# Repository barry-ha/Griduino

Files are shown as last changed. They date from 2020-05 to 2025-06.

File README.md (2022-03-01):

# Griduino
Griduino logoGPS display for vehicle dashboard showing position in the Maidenhead Locator System with distance to nearby grids. This is ideal for ham radio rovers.

# Introduction
Ham radio deals with invisible things.

We talk to invisible people. We look for contacts with invisible people that occupy invisible grid squares. To do so, we need to see invisible lines in the sky. I drive up mountains and travel on grid expeditions for VHF weak-signal operation. Being able to see these “invisible lines” is important to me. Seeing and hearing the unseen is always improved with technology (although I have that one uncle who doesn’t need any help /joke).

I want to know when I exit one grid square and enter another. Better yet, I want to know "how far to the next grid line in my current direction of travel?"

In contests I want time and distance figures to help me budget my time. I want to judge whether to stop and make contacts before leaving a grid. I want to get a sense of how long until I’m in the next grid. So, I’d like to know if a "new grid" opportunity is only a short distance away.

# Project Goals
For the operator:

1. How far to the next grid line?
1. What’s my current grid square?
1. Where am I in relation to the grid I’m occupying?
1. Where have I been? Or, how did I get here?
1. Make a bright display readable by a driver in motion.
1. What’s my altitude? Or, am I within a SOTA activation zone?
1. Hardware is powered from vehicle

For hobbyist developers:

1. Publish the software as open source
1. Make a programmable platform easily adaptable to related projects
1. Help the rover community build upon the platform.
1. Hardware should be possible for other hobbyists to duplicate
1. Hardware should small enough to mount conveniently on vehicle’s dashboard

# 	Griduino Usage
## Setup
Connect power: Griduino can be powered from two sources:

1. Connect USB to a computer for normal operation or programming, or
1. Attach 10- to 15-vdc source (automotive power) to the 5.5 mm barrel connector. The on-board regulator drops out at 9.8v. It seems to run okay with a 9v transistor battery for 30 minutes or more.

The speaker is louder with automotive power than with USB power, because the audio amplifier uses whichever power source has higher voltage. 

Connect speaker:

1. Connect a small speaker to the 3.5 mm stereo jack.
It produces one-channel (mono) output. If you attach a stereo speaker then both L and R output will have the same signal.

Place Griduino face up, preferably with a view of the sky to improve GPS satellite reception. The GPS receiver is very sensitive and will often work indoors.

## Operation
On power-up, Griduino shows credits (a splash screen) and plays Morse code callsigns of the authors.

Then it shows a Help screen to explain the touch-sensitive areas.
Touch Screen: There is a pressure-sensitive layer on top of the glass. We chose comically large touch regions so an operator can hit a target without looking.

- Top half:	Advance from one data screen to the next
- Bottom half:	Change brightness

Data Screens: Griduino v0.10 will display these screens.

1. Power-up animation (one time only)<br/>
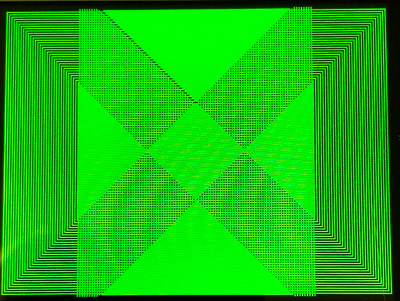
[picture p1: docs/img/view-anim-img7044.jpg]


2. Credits screen (one time only)<br/>
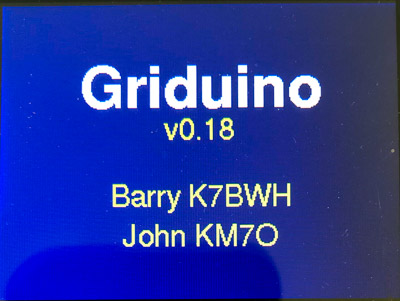
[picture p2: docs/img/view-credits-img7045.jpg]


3. Help screen (one time only)<br/>
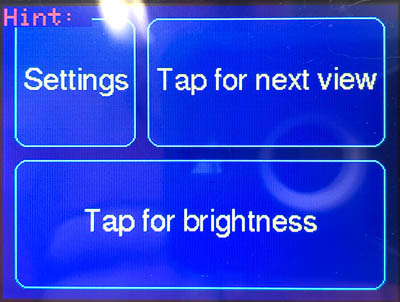
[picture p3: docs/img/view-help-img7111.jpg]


4. Grid location view<br/>
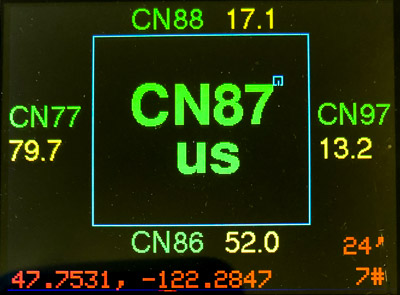
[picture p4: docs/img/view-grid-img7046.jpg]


5. Grid details view<br/>
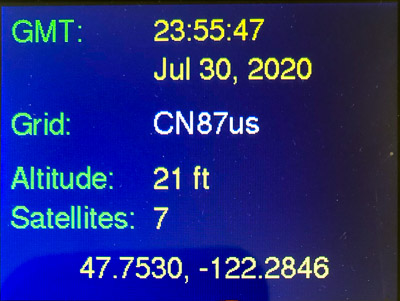
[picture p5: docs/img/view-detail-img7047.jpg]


6. GMT clock view<br/>
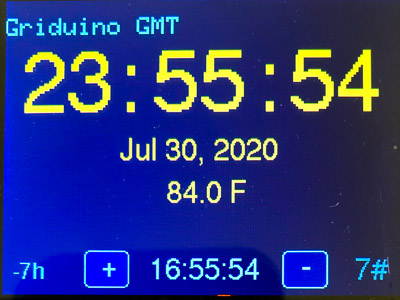
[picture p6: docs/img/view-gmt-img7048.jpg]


7. Audio volume control<br/>
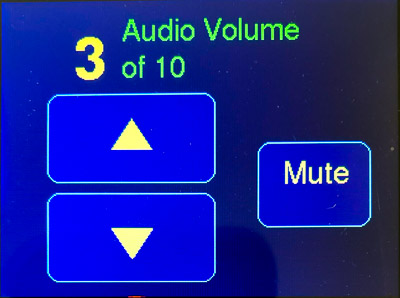
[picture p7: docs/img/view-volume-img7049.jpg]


8. Settings<br/>
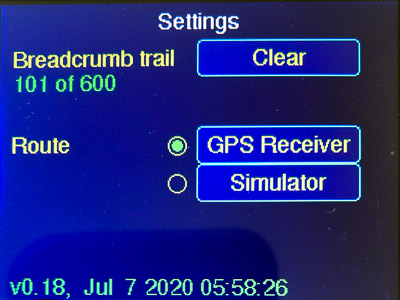
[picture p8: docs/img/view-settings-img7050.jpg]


# Programming
Griduino project hardware and software is open source and available on Github: [github.com/barry-ha/](https://github.com/barry-ha/)

To work with Griduino's source code, see the [Griduino Programming](./docs/PROGRAMMING.md) document.

# Parts List
Griduino's main building blocks are:
1. Arduino Feather M4 Express - https://www.adafruit.com/product/3857 
1. Adafruit 3.2" TFT color LCD display ILI-9341 - https://www.adafruit.com/product/1743 
1. Adafruit Ultimate GPS - https://www.adafruit.com/product/746
1. Adafruit Barometric Sensor - https://www.adafruit.com/product/3966 
1. Speaker for voice or CW grid-crossings. The audio chain produces line-level output to a digital potentiometer DS1804 for volume control, and an LM386 audio amplifier to a built-in speaker.

For a detailed list of parts, see the [Bill of Materials](./hardware/bill_of_materials.md).

Griduino kits are available from www.Griduino.com. Contact us directly to inquire about a pre-built and fully finished assembly.

# Support

Please browse our public group forum at [groups.io/g/Griduino/](https://groups.io/g/Griduino/)

Join our group to hear about upgrades, new software, ask questions, share your experience and suggest features.

# Disclaimer

The information provided is for general education and entertainment. We hope you learn from this and enjoy your hobbies in a safe manner with this new GPS information available at a glance. We take no responsibility for your assembly and construction, nor for how you use these devices. 

**Do not adjust Griduino while driving**. Keep your full attention on the road and the traffic around you. We cannot be held responsible for any property damage or injuries while using by this project. You are advised to check your local laws and consult professionals for any project involving electricity, construction or assembly. You are advised to drive in a safe and legal manner, consistent with all local laws, safety rules and good common sense.

You must accept that you and you alone are responsible for your safety and safety of others in any endeavor in which you engage.

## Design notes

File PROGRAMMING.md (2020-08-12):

<h1>Griduino Programming Instructions</h1>

<h2>1. Introduction</h2>

Griduino logoThank you for purchasing a Griduino GPS navigation kit. After [assembling the kit](https://github.com/barry-ha/Griduino/blob/master/ASSEMBLY.md "ASSEMBLY.md"), use this document to program it with the latest Griduino software. 

You can install a pre-compiled binary Griduino program, or set up the Arduino IDE (integrated development environment) to compile the source code yourself. By using the IDE, you can compile our example programs or modify the Griduino program or write all new software.

Griduino is open-source: https://github.com/barry-ha/Griduino

When complete, you'll have a useful driver's aid dedicated to show your location in the Maidenhead grid square system, your altitude, the exact time in GMT, barometric pressure and more.

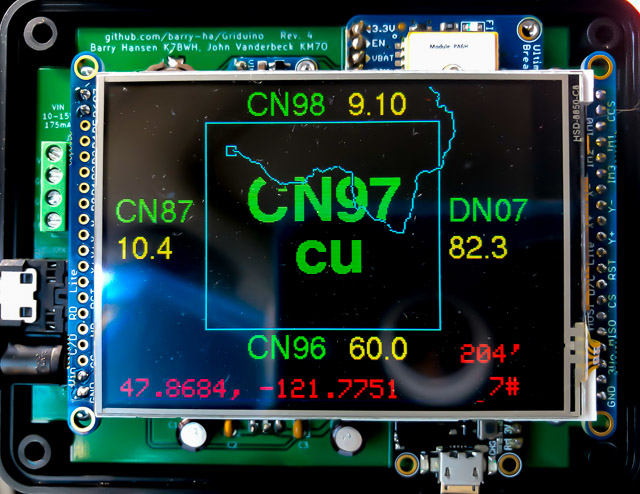
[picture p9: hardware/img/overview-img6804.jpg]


<h2>2. How to Install a Pre-Compiled Program on Griduino</h2>
Follow these steps to obtain the Griduino binary file and update the hardware.

1. **Download and Run Arduino IDE**<br/>
The Arduino IDE (integrated development environment) is the main workbench for writing, compiling and testing Arduino programs. Visit www.arduino.cc and find the **Software Downloads** section. Scroll down to the **Download the Arduino IDE** section. Find and **run the installer** for your operating system. For Windows, it is normal for it to open the Microsoft Store and download over 200 MB. Follow the prompts to install the software. **Launch the Arduino IDE**.<br/>
As of 8-7-2020, the latest workbench version is Arduino IDE v1.8.13

1. **Plug in Griduino**<br/>
Use a standard USB cable to connect your Griduino hardware to your computer. Depending on your computer, you should see some message about "setting up device" and possibly "device Feather M4 is ready".

1. **Select Port**<br/>
You'll need to figure out your COM port for this step. Here's how:<br/>
On Windows, run the **Device Manager** and expand the section for **Ports**. One of the items listed under Ports represents the Griduino device. It is possible for the port assignment to change from day to day, so be prepared to return to the Device Manager as needed.<br/>
In the Arduino IDE menu bar, go to **Tools > Port** and select the COM port that was given by the Device Manager. If there was more than one port listed, try them one by one.

1. **Install Board Support**<br/>
In this step, we will install support files needed by Arduino IDE to talk to the Feather M4. Here's how:<br/>
In the Arduino IDE menu bar, go to **Tools > Board > Boards Manager**. It will display a long list of hardware. Install the latest version of:
<ul>
<li>Arduino AVR Boards by Arduino: v1.8.3</li>
<li>Arduino SAMD Boards (32-bits ARM Cortex-M0+): v1.8.6</li>
</ul>

1. **Select Board**<br/>
On the Arduino IDE menu bar, select **Tools > Board > Arduino SAMD (32-bits ARM Cortex-M0+ and Cortex-M4) > Adafruit Feather M4 Express**<br/>
If the option is not available, please review previous step "Install Board Support".

1. **Download Griduino Binary**
You'll need a copy of the latest pre-compiled Griduino binary file. Here's how:<br/>
Visit the GitHub repository at https://github.com/barry-ha/Griduino. Find and click on **Griduino.ino.feather_m4.bin**. This will open a new web page for the binary file alone. Find and click on the **Download** link. Save this file in a place where you can easily find it for the next step.<br/>
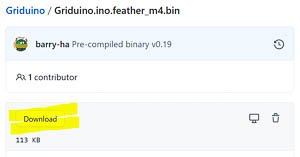
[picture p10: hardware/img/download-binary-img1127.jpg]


1. **Install Griduino Binary on Feather M4 Express**
Now that the Arduino IDE is ready, and we have the binary file, here's how to download it to the Feather M4.<br/>
<ul>
<li>Check that the Griduino hardware is still plugged in via USB to your computer.</li>
<li>Run Arduino IDE</li>
<li>On the menu bar, use **Tools > something (help!)**
</ul>

How to install without the IDE: https://forum.arduino.cc/index.php?topic=417659.0<br/>

How to install with AVRDude: https://arduino.stackexchange.com/questions/20978/is-there-a-way-to-upload-precompiled-code-to-an-arduino<br/>

More and sample cmd: https://forum.arduino.cc/index.php?topic=292979.0 such as "avrdude -c stk500v1 -P [com port] -p atmega328p -U flash:w:[Filename.hex]:i"<br/>

My command line is:<br/>
C:\Users\barry\Documents\ArduinoData\packages\arduino\tools\bossac\1.8.0-48-gb176eee/bossac -i -d --port=COM12 -U -i --offset=0x4000 -w -v C:\Users\barry\AppData\Local\Temp\arduino _ build _ 72645/Griduino.ino.bin -R

<h2>3. How to Setup the Arduino IDE for Griduino</h2>
If you want to compile Griduino source code or work with its example files (and we hope you do) then here's everything you need to setup the workbench.

(Coming soon)

<h2>4. How to Create a Binary File for Distribution</h2>

It may be useful to know how to create a binary image of a compiled program for Arduino processors in general. If you ever want to distribute an Arduino program, it is easier for people to install a binary image than to compile the source code themselves. 

This section also applies to how we create the Griduino program for general distribution.

1. **Launch Arduino IDE**<br/>
Run the Arduino workbench on your computer.

1. **File > Open > Griduino.ino**<br/>
Open the main source code file.

1. **Sketch > Export Compiled Binary**<br/>
Wait for the compilation process to finish

2. **Sketch > Show Sketch Folder**<br/>
You will find a binary file in the sketch folder with **.bin** extension. This is the compiled file which can be installed onto an Arduino board. e.g. “Griduino.ino.feather_m4.bin”

<h2>4. Disclaimer</h2>

The information provided is for general education and entertainment. We hope you learn from this and enjoy your hobbies in a safe manner with this new GPS information available at a glance. We take no responsibility for your assembly and construction, nor for how you use these devices. 

**Do not adjust Griduino while driving**. Keep your full attention on the road and the traffic around you. We can not be held responsible for any property or medical damages caused by these projects. You are advised to check your local laws and consult professionals for any project involving electricity, construction or assembly. You are advised to drive in a safe and legal manner, consistent with all local laws, safety rules and good common sense.

You must accept that you and you alone are responsible for your safety and safety of others in any endeavor in which you engage.

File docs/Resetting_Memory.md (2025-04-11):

<h1>Griduino Memory Reset Instructions</h1>

<h2 id="intro">1. Introduction</h2>

Griduino logoIn rare instances, the Griduino flash memory may become corrupted. Here's how to recover by reformatting its internal file system and then re-installing Griduino software.

<h2 id="save">2. Backup Your Current Griduino Software</h2>
These steps will copy the software from Griduino to your hard drive. This is easier than downloading new software. Later, you'll restore this backup onto Griduino which guarantees you'll be running the exact same version as before.

1. **Plug in Griduino**<br/>
   - Use a standard USB data cable to connect your Griduino hardware to your computer.
   - Depending on your computer, you should see a message about "setting up device" and possibly "device Feather M4 is ready".
   - Remove Griduino's top cover to expose the "reset" button adjacent to the USB connector.

1. **Open Feather as a Drive**<br/>
   - Press the Feather's "reset" button **twice** rapidly, about a tenth of a second apart.
   - The Griduino screen may go blank out and turn white. Many computers will sound an audible "drive ready" chime.
   - In Windows, open the **File Explorer**.
   - Find the new drive, e.g. "**FEATHERBOOT (F:)**"
   - If the USB device name is CIRCUITPY, then double-click the Reset button again until you get FEATHERBOOT.

1. **Copy "CURRENT.UF2" from FEATHERBOOT to your computer**
   - Note: The file "current.uf2" is always the current software program loaded into the processor memory system.
   - Drag and drop "current.uf2" to your computer's local storage. 
   - Store the .UF2 file in a temporary place that you can find again later when you restore this software.

<h2 id="program">2. Reformat File System</h2>
Normally, you'll never need to reformat Arduino's file system. In the rare case you need to start over with a clean file system, here's how. 

1. **Download "flash_erase_express.uf2" file from GitHub**<br/>
   - Visit https://github.com/barry-ha/Griduino/tree/master/downloads
   - Download a copy of **flash_erase_express.uf2**
   - Note: We pre-compiled this program for you. It is a direct and unmodified program from the `examples` folder of https://github.com/adafruit/Adafruit_SPIFlash

1. **Install flash_erase_express**<br/>
   - Press the Feather's "reset" button **twice** rapidly, about a tenth of a second apart.
   - Drag the .UF2 file that you downloaded and drop it on the new FEATHERBOOT drive. Or you can copy/paste it to the new drive.
   - After the copying completes, the on-board Neopixel will be blue.
   - A few seconds later, the Neopixel should starting flashing green once per second. This indicates the SPI flash has been erased and all is well.
   - If the Nexopixel starts flashing red two or three times a second, an error has occurred and hardware repair is needed.
 
<h2 id="circuitpy">3. Install CircuitPython</h2>
We temporarily install CircuitPython, which prepares the flash memory file system to become compatible with Windows file systems.

1. **Download "CircuitPython" binary distribution file**<br/>
   - Get the latest CircuitPython UF2 file for your board (Feather M4 Express) from https://circuitpython.org/downloads.
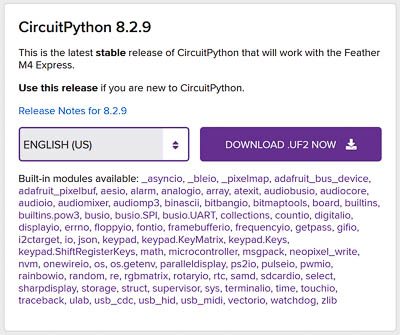
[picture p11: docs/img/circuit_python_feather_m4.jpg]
   - As of April 2025, the latest stable release is 9.2.7 and the UF2 file is named "[adafruit-circuitpython-feather_m4_express-en_US-8.2.9.uf2](https://downloads.circuitpython.org/bin/feather_m4_express/en_US/adafruit-circuitpython-feather_m4_express-en_US-9.2.7.uf2)" and will look something like:<br/>

1. **Start the bootloader on the Feather board** by double-clicking its Reset button.<br/>
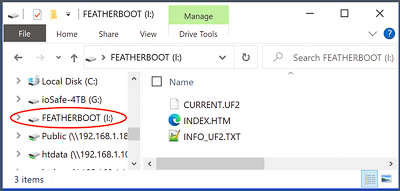
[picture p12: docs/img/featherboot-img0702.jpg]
   - After a moment, you should see a "FEATHERBOOT" drive appear on your desktop computer.<br/>

1. **Drag the circuitpython UF2 file** from Windows to FEATHERBOOT.
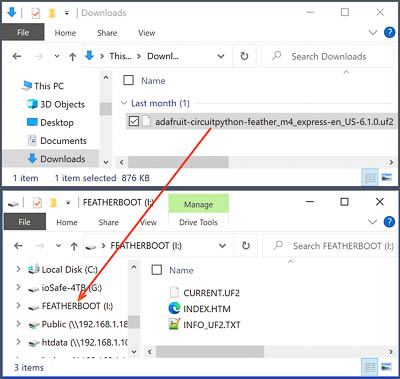
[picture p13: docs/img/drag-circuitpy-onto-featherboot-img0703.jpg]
   - 
   - The UF2 file will be copied and the Feather will reboot.
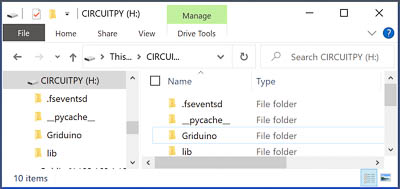
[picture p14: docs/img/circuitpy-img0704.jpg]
   - Then you should see a CIRCUITPY drive appear as an external USB drive. It will already have a few files on it.<br/>

<h2 id="audio">4. Optional: Install Audio Files</h2>

Optional: Griduino can use speech to announce grid lines. To do so, you can install audio recordings of the letters and numbers. These are .WAV files provided on GitHub in the `audio` folder.

If you don't need spoken-word announcements, skip to "Re-install Griduino Program" below.

You only need to install audio files one time.

The idea here is to use the CircuitPython installation (above) which allows the Flash memory to appear as an external USB drive. Then we can copy the "audio" folder to Flash. If, instead, the Griduino software is running then we cannot access its file system from the computer. The first time CircuitPython is installed, it automatically formats Flash memory in a way that remains compatible thereafter.

1. **Download "griduino_audio.zip" file from GitHub**<br/>
   - Visit https://github.com/barry-ha/Griduino/tree/master/downloads
   - Get a copy of **audio_female.zip** and **audio_male.zip**
   - Choose the voice you want; Griduino can only work with one voice at a time. To switch to another voice, repeat this process with the other files.
   - If you want to make your own recordings that are compatible with Griduino, see the README document at https://github.com/barry-ha/Audio_QSPI.

1. **Unzip e.g. "audio_male.zip"**
   - Extract this file to a temporary folder. 
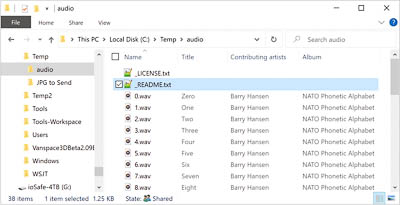
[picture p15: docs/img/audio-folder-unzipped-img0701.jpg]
Extracted audio folder
   - The result will have a folder named "audio" that contains 26 letters and 10 numbers as short recordings in standard Microsoft WAV format.<br/>

1. **Start the bootloader on the Feather board** by double-clicking its Reset button.<br/>
   - After a moment, you should see a "FEATHERBOOT" drive appear on your desktop computer.<br/>

1. **Drag the circuitpython UF2 file** from Windows to FEATHERBOOT.
   - 
   - The UF2 file will be copied and the Feather will reboot.
   - Then you should see a CIRCUITPY drive appear as an external USB drive. It will already have a few files on it.<br/>

1. **Drag the audio folder** from Windows to CIRCUITPY.<br/>
   - Be sure to store all of the WAV files (there are at least 36 of them) in a top-level folder named "audio".
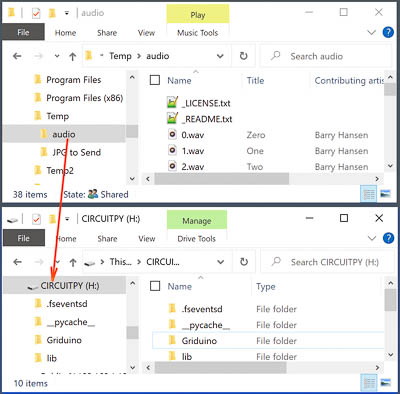
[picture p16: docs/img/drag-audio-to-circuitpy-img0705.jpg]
   - Note that file names and folders are case-sensitive.<br/>
   - Now we're all done with CircuitPy mode, although you can use re-install CircuitPy later for direct access to the file system.

<h2 id="griduino">4. Re-install Griduino Program</h2>

You can re-install the Griduino software you saved earlier, or you may download the latest software from GitHub.

1. **Open Feather as a Drive**<br/>
   - Press the Feather's "reset" button **twice** rapidly, about a tenth of a second apart.
   - Find the new drive, e.g. "**FEATHERBOOT (F:)**"
   - If the USB device name is CIRCUITPY, then double-click the Reset button again until you get FEATHERBOOT.

1. **Install Griduino Software on Feather M4 Express**<br/>
   - Drag the .UF2 file that you saved earlier and drop it on the new FEATHERBOOT drive. Or you can copy/paste it to the new drive.
   - After the copying completes, Griduino will automatically restart with the new software.
   - First it shows an animation, then it shows a credits screen with the program name and version number, then a hints screen with a visual reminder of the default touch-sensitive areas.

1. **Test Griduino's audio playback**<br/>
   - If you installed audio files: Start the Griduino program
   - Plug a speaker into the speaker jack (or connect to the internal terminal strip).
   - Press the "gear" icon until you see the **Audio Type** screen.<br/>Select **Spoken Word**.<br/>It should immediately announce your grid square.<br/>If it beeps, then Griduino did not find the audio files.
   - Press the "gear" icon until you see the **Speaker Volume** screen.<br/>Press the up/down buttons to adjust a comfortable volume.<br/>It should play an audio sample on each press.
   - To troubleshoot errors, open the **Arduino IDE** and click **Tools** > **Serial Monitor** to read error messages.

<h2 id="uf2">5. Understanding File System's Configuration Files</h2>

Griduino automatically creates and updates its internal configuration files. These are in a binary format you'll never need to work with them. However, it may be interesting to know where they are and how they work.

The files are stored in Flash memory in a section of onboard memory. To see the directory of files:

* **Terminal window:** Open a terminal window and send the command "list files", or
* **CircuitPy:** Reload Griduino with the CircuitPy program and use Windows File Explorer

Some of the files you can expect to see are:

* Directory of audio
   * `19004 0.wav`
   * `24712 1.wav`
   * `19602 2.wav`
   * etc
   * `25040 z.wav`
   * `38 files, 799330 bytes`
* Directory of Griduino
   * ` 97 announce.cfg` - Morse code, Spoken word, No audio
   * `272 gpshistory.csv` - GPS breadcrumb trail
   * `216 gpsmodel.cfg` - latitude, longitude, altitude, metric/english, timezone
   * ` 97 nmea.cfg` - send NMEA sentences to USB cable yes/no
   * `100 screen.cfg` - screen orientation
   * `100 volume.cfg` - audio volume
   * `9 files, 882 bytes`

<h2 id="more">Appendix. Griduino's File System</h2>

Here is additional information about Griduino's file system:

1. (Understanding Configuration Files)[https://github.com/barry-ha/Griduino/blob/master/docs/PROGRAMMING.md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]
1. (How to Use a Serial Console)[https://github.com/barry-ha/Griduino/blob/master/docs/PROGRAMMING.md#8-how-to-use-a-serial-console]
1. (Griduino Programming Instructions)[https://github.com/barry-ha/Griduino/blob/master/docs/PROGRAMMING.md]

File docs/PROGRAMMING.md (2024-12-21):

<h1>Griduino Programming Instructions</h1>

<h2 id="intro">1. Introduction</h2>

Griduino logoThank you for purchasing a Griduino GPS navigation kit. After [assembling the kit](https://github.com/barry-ha/Griduino/blob/master/ASSEMBLY.md "ASSEMBLY.md"), use this document to program it with the latest Griduino software.

You can install a pre-compiled binary Griduino program, or set up the Arduino IDE (integrated development environment) to compile the source code yourself. By using the IDE, you can compile our example programs or modify the Griduino program or write all new software.

Griduino is open-source: https://github.com/barry-ha/Griduino

When complete, you'll have a useful driver's aid dedicated to show your location in the Maidenhead grid square system, your altitude, the exact time in GMT, barometric pressure and more.



<h2 id="program">2. Install the Griduino Program</h2>
Follow these steps to obtain the Griduino binary file and update the software.

1. **Download Griduino Binary**<br/>
   - Visit https://github.com/barry-ha/Griduino
   - Click on **downloads/griduino_v108.uf2** or later version. This will open a new web page for the binary UF2 file.
   - Click on the **Download** link. Save this file where you can easily find it for the next step.

1. **Plug in Griduino**<br/>
   - Use a standard USB cable to connect your Griduino hardware to your computer.
   - Depending on your computer, you should see a message about "setting up device" and possibly "device Feather M4 is ready".
   - Get a wooden (must not be metal or conductive) toothpick that can fit in the hole in the front cover. Or remove the cover to expose the "reset" button.

1. **Open Feather as a Drive**<br/>
   - Press the Feather's "reset" button **twice** rapidly, about a tenth of a second apart.
   - The Griduino screen will blank out and turn white. Most Windows computers will sound an audible "drive ready" chime.
   - In Windows, open the **File Explorer**.
   - Find the new drive, e.g. "**FEATHERBOOT (F:)**"
   - If the USB device name is CIRCUITPY, then double-click the Reset button again until you get FEATHERBOOT.

1. **Install Griduino Software on Feather M4 Express**<br/>
   - Drag the .UF2 file that you downloaded and drop it on the new FEATHERBOOT drive. Or you can copy/paste it to the new drive.
   - After the copying completes, Griduino will automatically restart with the new software.
   - First it shows an animation, then it shows a credits screen with the program name and version number, then a hints screen with a visual reminder of the default touch-sensitive areas.

<h2 id="audio">3. Install Audio Files</h2>

Griduino can use speech to announce grid lines. To do so, we must install audio recordings of the letters and numbers. These WAV files are copied onto the Feather separately using a different process than the binary program file.

You only need to install audio files one time.

The idea here is to temporarily install CircuitPython which allows the Flash memory to appear as an external USB drive. Then copy our "audio" folder to Flash and install the Griduino program again. The first time CircuitPython is installed, it automatically formats Flash memory in a way that remains compatible thereafter.

1. **Download "griduino_audio.zip" file from GitHub**<br/>
   - Visit https://github.com/barry-ha/Griduino/tree/master/downloads
   - Get a copy of **audio_female.zip** and **audio_male.zip**
   - Choose the voice you want; Griduino can only work with one voice at a time. To switch to another voice, repeat this process with the other files.
   - If you want to make your own recordings that are compatible with Griduino, see the README document at https://github.com/barry-ha/Audio_QSPI.

1. **Unzip e.g. "audio_female.zip"**
   - Extract this file to a temporary folder. 
   - The result will have a folder named "audio" that contains 26 letters and 10 numbers as short recordings in standard Microsoft WAV format.<br/>Extracted audio folder

1. **Download "CircuitPython" binary distribution file**<br/>
   - Get the latest CircuitPython UF2 file for your board (Feather M4 Express) from https://circuitpython.org/downloads.
   - As of December 2023, the latest stable release is 8.2.9 and the UF2 file is named "adafruit-circuitpython-feather_m4_express-en_US-8.2.9.uf2" and will look something like:<br/>

1. **Start the bootloader on the Feather board** by double-clicking its Reset button.<br/>
   - After a moment, you should see a "FEATHERBOOT" drive appear on your desktop computer.<br/>

1. **Drag the circuitpython UF2 file** from Windows to FEATHERBOOT.
   - 
   - The UF2 file will be copied and the Feather will reboot.
   - Then you should see a CIRCUITPY drive appear as an external USB drive. It will already have a few files on it.<br/>

1. **Drag the audio folder** from Windows to CIRCUITPY.<br/>
   - Be sure to store all of the WAV files (there are at least 36 of them) in a top-level folder named "audio".
   - Note that file names and folders are case-sensitive.<br/>

1. **Reboot Feather and re-install Griduino**<br/>
   - Follow the steps (above) in [2. How to Install the Griduino Program](#program) above to run the program.

1. **Test Griduino's audio playback**<br/>
   - Start the Griduino program
   - Press the "gear" icon until you see the **Audio Type** screen.<br/>Select **Spoken Word**.<br/>It should immediately announce your grid square.<br/>If it beeps, then Griduino did not find the audio files.
   - Press the "gear" icon until you see the **Speaker Volume** screen.<br/>Press the up/down buttons to adjust a comfortable volume.<br/>It should play an audio sample on each press.
   - To troubleshoot errors, open the **Arduino IDE** and click **Tools** > **Serial Monitor** to read error messages.

<h2 id="format">4. How to Reformat File System</h2>

Normally, you'll never need to reformat Arduino's file system. The memory partition and FAT file system will automatically take care of itself.

The first time you install CircuitPy it will automatically reformat the Flash chip. Subsequently reloading CircuitPy will not affect the Flash chip contents. 

We recommend loading CircuitPy when you first start using a new Feather M4. This ensures that all further file operations are done in a file system that easily shared with CircuitPy. The file system format is compatible with all IDE program that are based on the Adafruit SPI Flash framework ( https://github.com/adafruit/Adafruit_SPIFlash ).

In the rare case you need to start over with a clean file system, here's how. Adafruit provides some reformatting sketches in their ‘examples’ folder of Adafruit_SPIFlash. Open the IDE and use the menu bar to navigate to Files > Examples > Adafruit SPIFlash. Some of the programs are:

* **Flash erase express** - will nuke the file system from orbit to start over. This will completely erase all data on the QSPI flash for “Express” models, ie, processors with on-board QSPI chips such as the Feather M4 Express. This is handy to reset the flash into a known empty state and fix potential filesystem or other corruption issues.
* **SdFat format** - SPI Flash FatFs formatting example. Use the console (serial monitor) to respond to prompts to confirm the operation. Partitioning and formatting will take about 60 seconds.
* **Flash speedtest** - measures size and R/W speed of the RAM file system. This will erase the chip but not reformat it. You'll need to install CircuitPy next to format the filesystem.

<h2 id="uf2">5. Understanding File System's Configuration Files</h2>

Griduino automatically creates and updates its internal configuration files. These are in a binary format you'll never need to work with them. However, it may be interesting to know where they are and how they work.

The files are stored in Flash memory in a section of onboard memory. To see the directory of files:

* **Terminal window:** Open a terminal window and send the command "list files", or
* **CircuitPy:** Reload Griduino with the CircuitPy program and use Windows File Explorer

The files you can expect to see are:

* Directory of audio
   * `19004 0.wav`
   * `24712 1.wav`
   * `19602 2.wav`
   * etc
   * `25040 z.wav`
   * `38 files, 799330 bytes`
* Directory of Griduino
   * ` 97 announce.cfg` - Morse code, Spoken word, No audio
   * `272 gpshistory.csv` - GPS breadcrumb trail
   * `216 gpsmodel.cfg` - latitude, longitude, altitude, metric/english, timezone
   * ` 97 nmea.cfg` - send NMEA sentences to USB cable yes/no
   * `100 screen.cfg` - screen orientation
   * `100 volume.cfg` - audio volume
   * `9 files, 882 bytes`

<h2 id="uf2">6. How to Create a Binary File for Distribution</h2>

It may be useful to know how to create a binary image of a compiled program for Arduino processors in general. If you ever want to distribute your own Arduino program, it is easier for your users to install your binary image than to compile the source code themselves.

This section also applies to how we prepared the Griduino software for general distribution.

1. **Launch Arduino IDE**<br/>
Run the Arduino workbench on your computer.

1. **File > Open > Griduino.ino**<br/>
Open the main source code file.

1. **Sketch > Export Compiled Binary**<br/>
It will compile; wait for this to finish.

1. **Sketch > Show Sketch Folder**<br/>
You will find a binary file in the sketch folder with **.bin** extension. This is the compiled binary file but it cannot be directly distributed or installed onto an Arduino board.
   - Arduino IDE 1: Griduino.ino.feather_m4.bin
   - Arduino IDE 2: build / adafruit.samd.adafruit_feather_m4 / Griduino.ino.bin

1. **Convert Compiled Binary to UF2**<br/>
Run the Python conversion script (author https://github.com/microsoft/uf2):
   - Open command line window
   - Change directory to the .bin file, e.g.:<br/>**cd C:\Users\barry\Documents\Arduino\Griduino**
   - Run the Python converter script, e.g.:<br/>**py uf2conv.py -c -b 0x4000 -o downloads/griduino.uf2 Griduino.ino.feather_m4.bin**
   - Where "**-c:**" will pass remaining arguments to python script, "**-b 0x4000**" will set start of program, "**-o file.uf2**" is output file, and "**file.bin**" is input file

<h2 id="ide">7. How to Setup the Arduino IDE for Griduino</h2>

If you want to compile Griduino source code or work with its example files (and we hope you do) then here's everything you need to setup the workbench.

1. **Download and Run Arduino IDE**<br/>
The Arduino IDE (integrated development environment) is the main workbench for writing, compiling and testing Arduino programs. As of October 2024, the latest version is Arduino IDE v2.3.3. We recommend the latest version, although initial development was done with v1.18,  and the majority of work was done with v2.0 and v2.2.

  * Visit www.arduino.cc and find the **Software Downloads** section.
  * Scroll down to the **Download the Arduino IDE** section.
  * Find and **run the installer** for your operating system. For Windows, it is normal for it to open the Microsoft Store and download over 200 MB. Follow the prompts to install the software.
  * **Launch the Arduino IDE**.
  
2. **Add Packages Link to Board Manager**<br/>
The IDE can't find the list of SAMD boards unless we add their magic URL to preferences:

  * **File** > **Preferences**
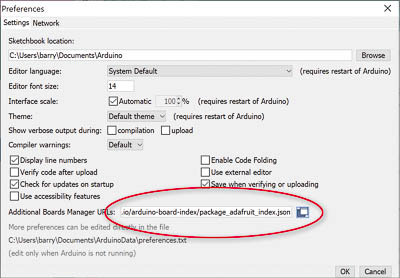
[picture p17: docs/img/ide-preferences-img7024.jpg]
Preferences dialog
  * Find the "Additional Boards Manager URLs" section<br/>
  * To the right is an icon that when selected will open up a window to add the new URL.
  * If the below URL is not visible or a different one is showing, add the following URL using the icon to be able to see the file "Adafruit SAMD Boards v 1.6.3" in the next step.
  * Add: https://adafruit.github.io/arduino-board-index/package_adafruit_index.json
  * It's important to use the icon because if you just type the above in to the URL slot, and select OK it will not store the new URL and be empty when you check it again.
  * Click OK

3. **Install Board Support**<br/>
In this step, we will install support files needed by Arduino IDE to talk to the Feather M4. Here's how:<br/>
In the Arduino IDE menu bar, go to **Tools > Board > Boards Manager**. It will display a long list of hardware. Install the latest version of:

  * Arduino AVR Boards, Built-In by Arduino: v1.8.6
  * Arduino SAMD Boards (32-bits ARM Cortex-M0+): v1.8.14
  * Adafruit SAMD Boards: v1.7.16

4. **Select Board**<br/>
On the Arduino IDE menu bar, select **Tools > Board > Arduino SAMD (32-bits ARM Cortex-M0+ and Cortex-M4) > Adafruit Feather M4 Express**<br/>
If the option is not available, please review previous step "Install Board Support".

5. **Select Port**<br/>
You'll need to figure out your COM port for this step. Here's how:<br/>
On Windows, run the **Device Manager** and expand the section for **Ports**. One of the items listed under Ports represents the Griduino device. It is possible for the port assignment to change from day to day, so be prepared to return to the Device Manager as needed.<br/>
In the Arduino IDE menu bar, go to **Tools > Port** and select the COM port that was given by the Device Manager. If there was more than one port listed, try them one by one.

6. **Install Library Dependencies**</br>
In the Arduino IDE menu bar, go to **Tools > Manage Libraries**. Install the latest version (and their dependencies) of these libraries:
   - ##AudioZero## by Arduino v1.1.2 (orig v1.1.1)
   - ##SD## by Arduino, SparkFun v1.3.0 (orig v1.2.4)
   - ##Adafruit TFTLCD Library## by Adafruit v1.0.3? (orig v1.0.6)
   - ##Adafruit BMP3XX Library## by Adafruit v2.1.5 (orig v2.1.2)
   - ##Adafruit BusIO## by Adafruit v1.16.1 (orig v1.11.0) (there is a known issue with v1.11.1)
   - ##I2CDevice" by Adafruit
   - ##Adafruit GFX Library## by Adafruit v1.11.10 (orig v1.10.13)
   - ##Adafruit GPS Library## by Adafruit v1.7.5 (orig v1.6.0)
   - ##Adafruit ILI9341## by Adafruit v1.6.1 (orig v1.5.10) also available: ILI9341_t3 by Limor Fired, Adafruit, Paul Stoffregen v1.0.0
   - ##Adafruit ImageReader Library## by Adafruit v2.9.2 (orig v2.7.0)
   - ##Adafruit NeoPixel## by Adafruit v1.12.3 (orig v1.10.4)
   - ##Adafruit SPIFlash## by Adafruit v5.0.0 (orig v3.9.0)
   - ##Adafruit TouchScreen## by Adafruit v1.1.5 (orig v1.1.3)
   - ##elapsedMillis## by Paul Stoffregen v1.0.6
   - ##SdFat – Adafruit Fork## by Bill Greiman v2.2.3 (orig v1.5.1)<br>*Note:* Use v1, as we have not tested v2<br> *Note:* There are two libraries with similar names. Be sure to install "SdFat - Adafruit Fork" and not "SdFat" which has an incompatible SdFat.h file
   - #Time# by Michael Margolis v1.6.1 <br>*Note:* searching the library manager for the word "time" lists just about every library. Searching for the word "timekeeping" will show the correct library.

These components are outside of Arduino's Library Manager, so follow these links to GitHub and install the latest version:

- https://github.com/tom-dudman/DS1804 v0.1.1 - library to control DS1804 Digital Potentiometer
- https://github.com/barry-ha/Audio_QSPI v1.1.0 - library to play WAV files from Quad-SPI memory chip

<h2 id=serialconsole>8. How to Use a Serial Console</h2>

You can download GPS tracks from Griduino without the Arduino IDE. There are some common "serial terminal" programs that can interact directly with Griduino's console interface over the USB connection.

We recommend Tera Term (https://tera-term.en.lo4d.com). Although we tested PuTTY (https://www.putty.org/), it randomly fails to chunks of text from Griduino. Use Tera Term instead.

How to use Tera Term to capture the breadcrumb trail in both KML and CSV format:

1. Run Tera Term
1. New connection window:
	1. Choose Serial
	2. Set Port: COM7 <i>(or your own Griduino port)</i>
	3. Leave everything else at default settings <i>(baud rate setting does not matter)</i>
1. Menu bar: <b>File > Log ...</b> <i>(pick a filename you can find later, e.g., griduino.log)</i>
1. Type: <b>stop nmea</b> <i>(don't press Enter!)</i>
1. Type: <b>help</b> <i>(don't press Enter!)</i>
1. Type: <b>version</b> <i>(don't press Enter!)</i>
1. Type: <b>dump kml</b> <i>(don't press Enter!)</i>
1. Type: <b>dump gps</b> <i>(don't press Enter!)</i>
1. Close Tera Term
1. Run Notepad
	1. Edit <i>griduino.log</i>
	1. Keep only from \<xml\> to \</xml\>
	1. Save as <i>griduino.<b>kml</b></i>
	1. Edit <i>griduino.log</i> again
	1. Keep only from "Record, Grid, Lat, Long, Date GMT" <br/>to last line e.g. "101, CN97ct, 47.8128,-121.8053, 11-17-2022  17:57:0"
	1. Save as <i>griduino.<b>csv</b></i>
	
Now you can open <i>griduino.kml</i> in Google Earth and <i>griduino.csv</i> in Microsoft XML.

<h2 id=disclaimer>9. Disclaimer</h2>

The information provided is for general education and entertainment. We hope you learn from this and enjoy your hobbies in a safe manner with this new GPS information available at a glance. We take no responsibility for your assembly and construction, nor for how you use these devices. 

**Do not adjust Griduino while driving**. Keep your full attention on the road and the traffic around you. We can not be held responsible for any property or medical damages caused by these projects. You are advised to check your local laws and consult professionals for any project involving electricity, construction or assembly. You are advised to drive in a safe and legal manner, consistent with all local laws, safety rules and good common sense.

You must accept that you and you alone are responsible for your safety and safety of others in any endeavor in which you engage.

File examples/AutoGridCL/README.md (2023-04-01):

# AutoGridCL

This is a command-line program to update the grid square in WSJT-X from Griduino in real time.

## Install Software

Install Python

* Download and Install Python https://www.python.org/downloads/
* Add Python to PATH https://datatofish.com/add-python-to-windows-path/
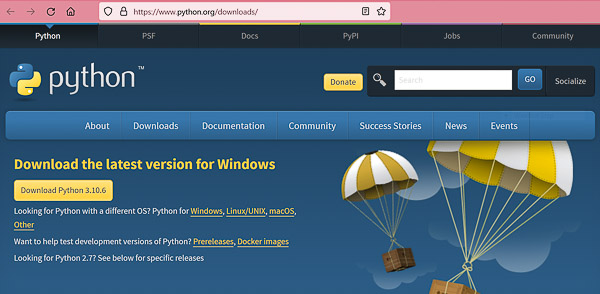
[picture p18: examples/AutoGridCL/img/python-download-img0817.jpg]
python download
<br/>

Get AutoGridCL files into a local folder

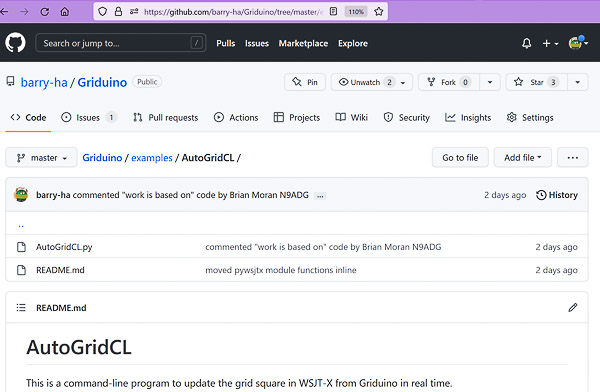
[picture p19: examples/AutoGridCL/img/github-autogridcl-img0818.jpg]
GitHub example folder
* Visit GitHub at https://github.com/barry-ha/Griduino <br/>
* Fetch the files in the 'examples/AutoGridCL' folder, currently:
  * AutoGridCL.py
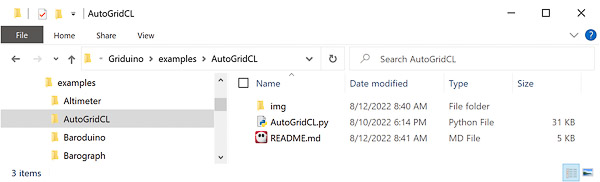
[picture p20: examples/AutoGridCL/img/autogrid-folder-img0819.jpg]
autogrid folder
  * README.md <br/>
 
## Configure WSJT-X for multicast

Run WSJT-X and configure File > Settings > Reporting:

* <b>UDP Server: 224.0.0.1</b> <br/>*224.0.0.1 is the most compatible with JTAlert, GridTracker, HRD, etc and these packets are not routed outboard onto your LAN*<br/>*127.0.0.1 can be used if you use WSJT only with AutoGridCL and no other programs*
* <b>UDP Server port number: 2237</b> <br/>*2237 is the default*
* <b>Outgoing interfaces: loopback_0</b> <br/>*a loopback interface is required*
* <b>Multicast TTL: 1</b> <br/>*this is a packet's Time-To-Live, a small number of seconds*

configure WSJT-X multicast
 
## Configure AutoGridCL

You need to modify the file 'AutoGridCL.py' so it can read NMEA sentences from Griduino and send UDP packets to and from WSJT-X.

Using a text editor (e.g. Notepad or Visual Studio Code), modify 'AutoGridCL.py': 

* line 7: <b>GPS_PORT = "COM53"</b> <br/>*must match that of your Griduino or GPS*
* line 8: <b>GPS_RATE = 115200</b> <br/>*Griduino always runs at 115200 baud. Other GPS devices often use 9600 baud.*
* line 11: <b>MULTICAST_ADDR = "224.0.0.1"</b> <br/>*must match the Multicast IP address in WSJT-X*
* line 12: <b>MULTICAST_PORT = 2237</b> <br/>*must match the Multicast UDP port in WSJT-X*

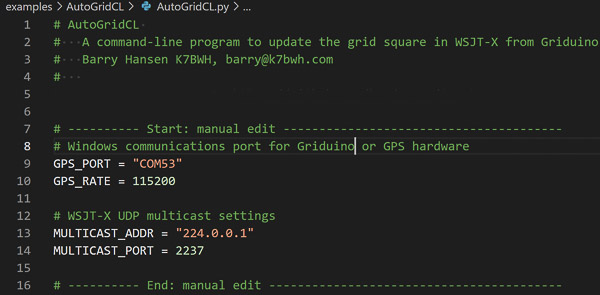
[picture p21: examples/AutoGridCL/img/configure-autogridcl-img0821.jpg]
configure AutoGridCL


## Run AutoGridCL

WSJT-X must be started first. AutoGridCL will not retry if it fails to find WSJT-X - it throws an exception and ends.

Start WSJT-X and set your grid using File>Settings>General to a grid different than the grid you are in and check the box to enable Autogrid.

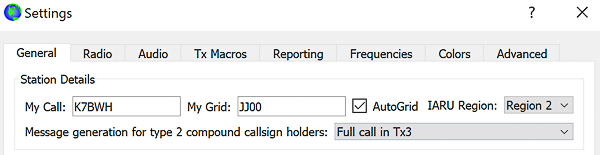
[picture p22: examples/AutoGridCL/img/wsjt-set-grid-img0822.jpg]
configure WSJT grid square


Run AutoGridCL.py by double-clicking it in your File Explorer. Or, you can open a command window and run ''python AutoGridCL.py'

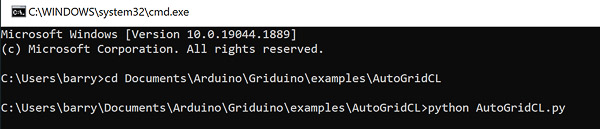
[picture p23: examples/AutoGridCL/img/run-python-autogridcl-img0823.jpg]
run python AutoGridCL from command line


You should see a command line window open with its console messages.

Then you should start to see UDP packets read from WSJT-X and, after Griduino syncs with satellites, some NMEA sentences from the GPS.

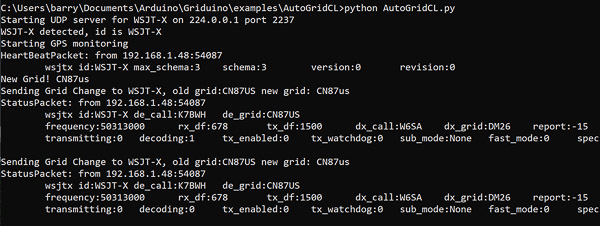
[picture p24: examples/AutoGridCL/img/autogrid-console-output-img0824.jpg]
example output of AutoGridCL


If everything is set up properly, you should see your TX6 message in WSJT-X change to the gridsquare you are actually in.

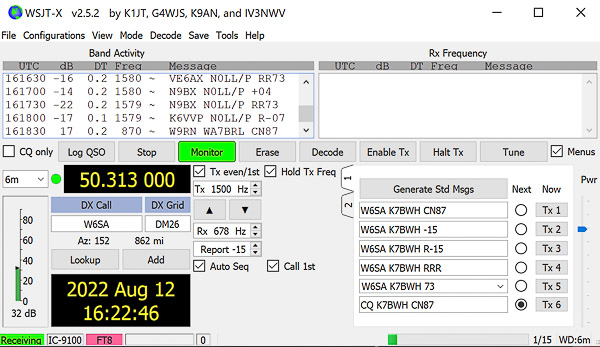
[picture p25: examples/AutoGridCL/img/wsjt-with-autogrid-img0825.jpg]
running WSJT with AutoGridCL


When you end AutoGridCL, its last grid will linger until you change it, or restart WSJT-X, or toggle autogrid off/on. When you restart WSJT-X, it will always remember and revert to the grid square you originally configured.

## Troubleshooting

Error reporting is fairly basic in this program. You will need to be resourceful to troubleshoot problems at this early stage.

In theory, this program should work with several different USB-attached GPS pucks. As long as the GPS sends standard NMEA data with lat/long position in $GPGGA or $GPGLL sentences, this will automatically decode them. We tested and recommend GPS pucks based on the GlobalSat BU-353-S4 chipset, typically $50 on Amazon in 2022.

The serial port for Griduino can only be opened by one program at a time, causing it to be mutually exclusive with programs like NMEA Time2. If you want full-time GPS-based clock synchronization, some work-arounds are:

* AutoGridCL and NMEA Time2 can run together if they each have their own GPS receiver and serial port. 
* Run [JTSync](http://www.dxshell.com/jtsync.html) instead of [NMEA Time2](https://www.visualgps.net/).

Here are some suggestions that might help.

* If a command-line window does not appear after starting AutoGridCL.py, then it might have an exception and have ended right away. To see messages, open a command window, change to the directory where the file is located, and type 'python AutoGridCL.py'
* If you don't see NMEA messages from Griduino, reboot it and watch the screen to see the version number. Griduino software version must be 1.10 or later.
* If this program can't connect to Griduino, close any programs using it (such as NMEA Time2 or the Arduino workbench) before starting AutoGridCL. Note that the USB port cannot be shared, so only one program at a time can listen to Griduino. For extra fun, note that NMEA Time2 is a background service and cannot be closed; you must configure its GPS setting to 'Off' to disconnect it from the serial port.
* Tell Barry about problems you run into so he can add it to the list: barry@k7bwh.com.

## Acknowledgements

We owe a great deal of credit to:

* Francis KV5W, https://kv5w.com/2021/10/17/wsjt-x-autogrid/
* Brian Moran N9ADG, https://github.com/bmo/py-wsjtx

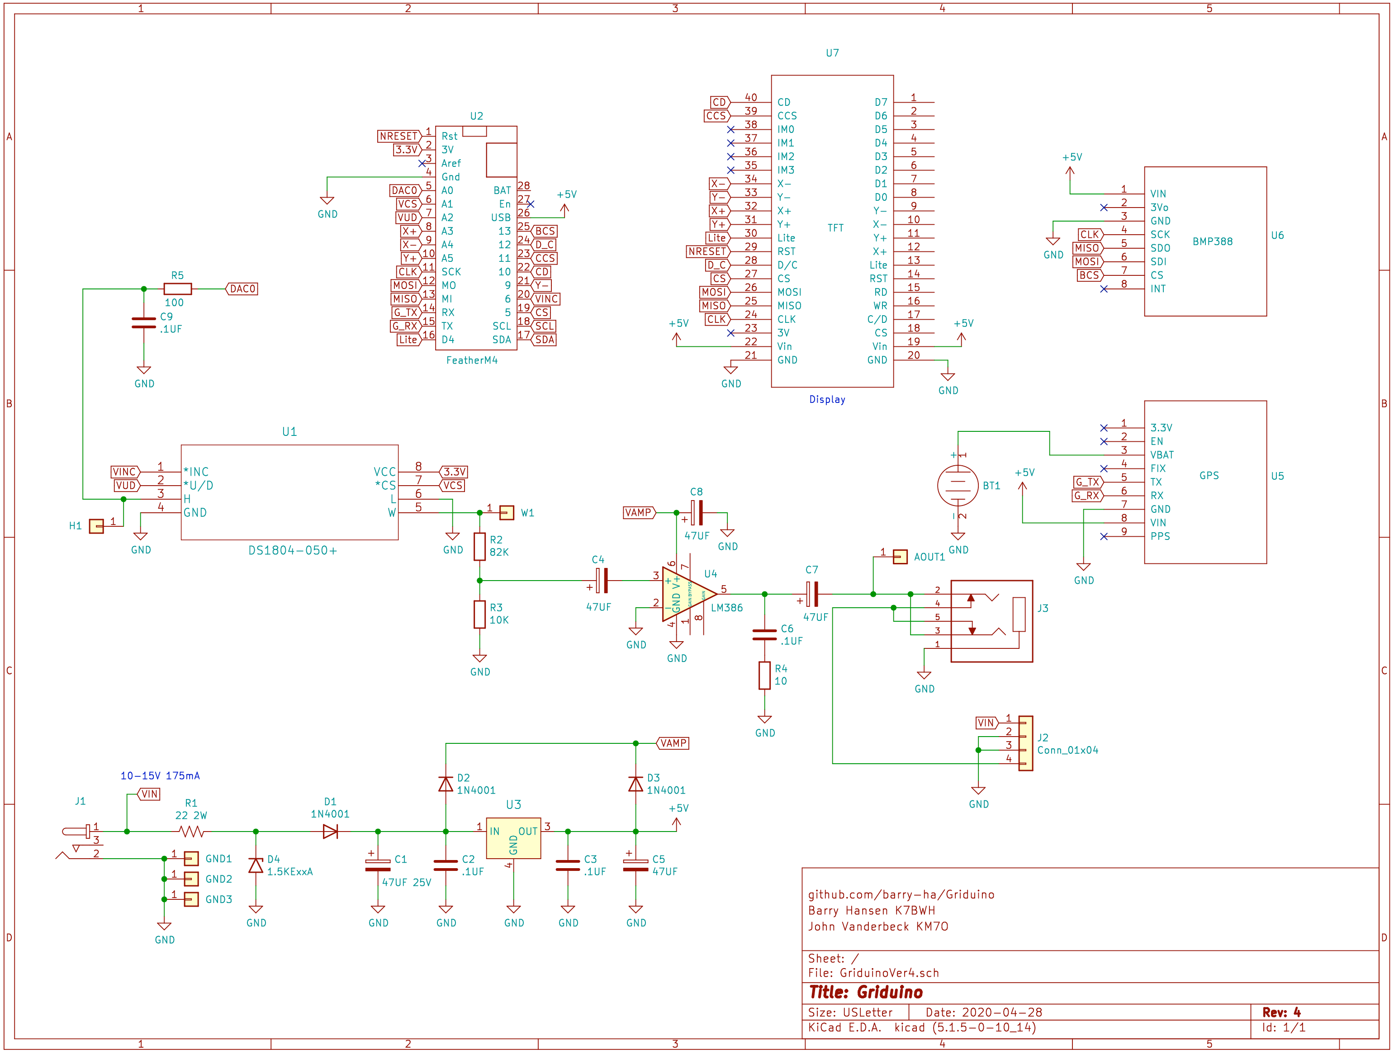
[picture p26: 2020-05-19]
hardware/Griduino v4 Schematic 2020-04-28.png

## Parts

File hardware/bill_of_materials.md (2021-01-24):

# Griduino
GPS display for vehicle dashboard showing position in the Maidenhead Locator System with distance to nearby grids, designed for ham radio rovers.

## Active Components
| Mfr | Mfr Part No | Digi-Key Part No | Reference | Qty | USD$  | Ext$ | Description  |
| --- | --- | --- | --- | :---: | ----- | --- | --- |
| Maxim | DS1804-050+ | DS1804-050+-ND | U1 |  1 |  4.30 | 4.30 | IC Digital Pot 50KOHM 100-tap |
| Adafruit | 3857 | 1528-2648-ND | U2 |  1 | 22.95 |  22.95 | Feather M4 Express |
| Microchip | MIC5239-5.0YS | MIC5239-5.0YS-ND | U3 |  1 |  2.79 | 2.79 | IC Linear Regulator 5v 500mA |
| TI | LM386N-3/NOPB | 296-43959-5-ND | U4 |  1 |  1.24 | 1.24 | Audio Amp, Mono LM386 700MW |
| Adafruit | 746 | 1528-1153-ND | U5 |  1 | 39.95 |  39.95 | Ultimate GPS, 66 channel (do not buy part #4279) |
| Adafruit | 3966 | 1528-2733-ND | U6 |  1 |  9.95 | 9.95 | BMP-388 Barometric Pressure |
| Adafruit | 1743 | 1528-2614-ND | U7 |  1 | 29.95 |  29.95 | TFT Display  |
| | | | **total** | **6** | | **111.13** | |

## Passive Components
| Mfr | Mfr Part No | Digi-Key Part No | Reference |  Qty | USD$  | Ext$ | Description  |
| --- | --- | --- | --- | :----: | ----- | --- | --- |
| Panasonic | ECE-A1EKA470I | P19582CT-ND | C1, C4, C5, C7, C8 | 5 |  0.25 | 1.25 | CAP Electrolytic 47uF 25v radial |
| KEMET | C320C104K5R5TA  | 399-4264-ND | C2, C3, C6, C9 | 4 |  0.24 | 0.96 | CAP Ceramic 0.1uF 50V radial |
| ON Semi | 1N4001G | 1N4001GOS-ND | D1, D2, D3 | 3 |  0.21 | 0.63 | Gen Purpose Diode 50V 1A |
| Vishay | 1.5KE18CA | 1.5KE18CA-E3/51GI-ND | D4 | 1 |  1.33 | 1.33 | Zener Diode 25.2v Clamp |
| Adafruit | 4445 | 3351-ND | LS1 | 1 |  3.95 | 3.95 | Speaker, 3W 4ohm |
| Yageo | FKN2WSJT-73-22R | 22AUCT-ND | R1 | 1 |  0.47 | 0.47 | RES 22-ohm 2W 5% axial |
| Yageo | CFR-25JB-52-82K | 82KQBK-ND | R2 | 1 |  0.10 | 0.10 | RES 82K 1/4W 5% axial |
| Yageo | CFR-25JB-52-10K | CFR-25JB-52-10K | R3 | 1 |  0.10 | 0.10 | RES 10K 1/4W 1% axial |
| Yageo | MFR-25FBF52-10R | 10.0XBK-ND | R4 | 1 |  0.10 | 0.10 | RES 10-ohm 1/4W 1% axial |
| Stackpole | CF14JT100R | CF14JT100RCT-ND | R5 | 1 |  0.10 | 0.10 | RES 100-ohm 1/4W 5% axial |
| | | | **total** | **16** | | **8.99** | |

## Hardware
| Mfr | Mfr Part No | Digi-Key Part No | Reference |  Qty  | USD$  | Ext$ | Description  |
| --- | --- | --- | --- | :---: | ----- | --- | --- |
| Panasonic | CR1220 | P033-ND | B1 | 1 |  1.00 | 1.00 | Lithium Battery 3-volt Coin Cell |
| Keystone | 1056 | 36-1056-ND | BT1 | 1 |  1.50 | 1.50 | Battery Holder (Open) 12.5 mm |
| CUI Devices | PJ-102A | CP-102A-ND | J1 jack | 1 |  0.64 | 0.64 | Connector Power Jack 2X5.5 mm |
| CUI Devices | PP3-002A | CP3-1000-ND | J1 plug | 1 |  1.29 | 1.29 | Connector Power Plug 2.1X5.5 mm |
| Amphenol | YO0421500000G | 609-3920-ND | J2 | 1 |  1.01 | 1.01 | Connector Screw Terminal 4pin |
| CUI Devices | SJ1-3545N | CP1-3545N-ND | J3 jack | 1 |  1.31 | 1.31 | Connector 3.5mm Audio Stereo Jack |
| CUI Devices | MP3-3501 | MP3-3501 | J3 plug | 1 |  1.22 | 1.22 | Connector 3.5mm Audio Mono Plug |
| Sullins | PPTC201LFBN-RC  | S7018-ND | | 1 |  1.23 | 2.46 | Connector 20-pos 0.1 Tin (LCD)  |
| Sullins | PPTC021LFBN-RC  | S7000-ND | | 2 |  0.32 | 0.64 | Connector 2-pos 0.1 Tin (LCD) |
| Keystone | 4952 | 36-4952-ND | TP1-3, TP_GND | 6 |  0.22 | 1.32 | PC Test Point Loop |
| JLC PCB | | n/a | PCB | 1 |  6.00 | 6.00 | Printed Circuit Board |
| Polycase | QS-50MBT | n/a | | 1 | 15.00 |  15.00 | Plastic Case, Custom 4.5 x 3.5 x 1.25 |
| | | | **total** | | | **41.36** | |

## Packaging
| Mfr | Mfr Part No | Digi-Key Part |  Qty  | USD$  | Ext$  | Description  |
| --- | --- | --- | :---: | ----- | ----- | --- |
| Desco | 13879 | 16-1344-ND | 4 |  0.12 |  0.48 | Antistatic bag, 3" x 5" |
| Desco | 12250 | 16-1231-ND | 1 |  0.06 |  0.06 | Antistatic foam, 1/4" 1" x 2" |
| Aviditi | M752 | n/a | 1 |  0.79 |  0.79 | White easy-fold box, 7 x 5 x 2 |
| Beadaholic  | ZDI-0203 | n/a | 1 |  0.05 |  0.05 | Bag for screws 2x3" |
| Alin | | n/a | 1 |  0.19 |  0.19 | Cushion foam pouch 7.5 x 12" |
| | | | **total** | | **1.53** | |

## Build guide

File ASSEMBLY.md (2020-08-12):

<h1>Griduino Kit Assembly Instructions</h1>

<h2>1. Introduction</h2>

Griduino logoThank you for purchasing a Griduino GPS navigation kit. Once assembled, this kit is a useful driver's aid dedicated to show your location in the Maidenhead grid square system, your altitude, the exact time in GMT, barometric pressure and more. Further, the hardware is a highly capable platform for programming your own features.



These assembly instructions apply to Revision 4 of the printed circuit board.

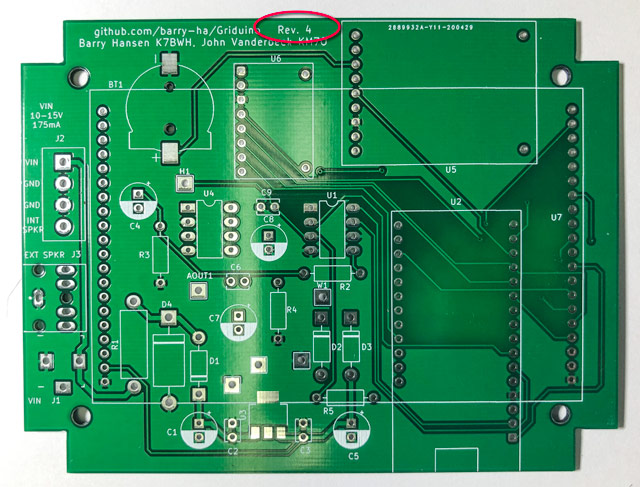
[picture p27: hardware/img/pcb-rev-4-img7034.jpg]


<h2>2. You Will Need</h2>

This kit is almost entirely "through hole" construction. Only two components, the battery holder and voltage regulator, are large surface-mount parts.

<h3>You must have:</h3>

* **Printed BOM and schematic diagram.** The component values are found on the bill of materials and the schematic. For example, to learn that R1 is a 22-ohm 2-watt resistor, you must find it in the BOM or schematic. These assembly instructions generally *don't* include part values in an attempt, possibly futile, to avoid multiple documents getting out of sync. The schematic is your ultimate golden master reference for all Griduino design. This is an open-source project and the latest documents are available on https://github.com/barry-ha/Griduino.
* **Fine-tipped soldering iron.** A standard fine-tipped iron suitable for use with conventional 0.1” pitch through-hole components.  It is recommended that you use a temperature controlled iron at a suitable temperature for your solder, if you have one. It is assumed that you will already have the necessary skills to solder this kit. If however you are not comfortable with through-hole electronic soldering, there are plenty of soldering tutorials available online.
* **Decent quality solder, with a flux core.**  Any decent quality, thin, flux cored solder designed for electronic use should be suitable for assembling this kit. Solder size 0.50 mm is ideal. Do not use solder intended for plumbing.
* **Needle nose pliers.** The component's leads must be bent with small pliers for a good fit into holes. Small pliers are also good for picking up the smallest parts from a tray.
* **Side cutters.** After you solder discrete components to the board, you will need to clip off the protruding wires. Wear eye protection and aim the bits away from you in a safe direction. 
* **Philips-head screwdriver.** There are four small screws to attach the PCB into the case.
* **Solderless breadboard.** To solder header pins onto small board assemblies, temporarily using a solderless breadboard will hold pins in correct alignment.<br/>
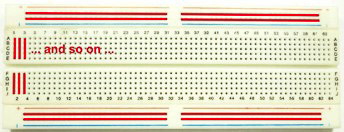
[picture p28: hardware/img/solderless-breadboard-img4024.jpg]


<h3>It will be nice to have:</h3>

* **Hobbyist bench vise.** You'll need a way to hold the PCB at a convenient height and angle for soldering parts. A small adjustable bench vise, such as a <a href="https://www.panavise.com/">Panavise Model 366</a>, will make your task easier. Use a holder wide enough to grip the Griduino PCB of 4-1/2" width.<br/>
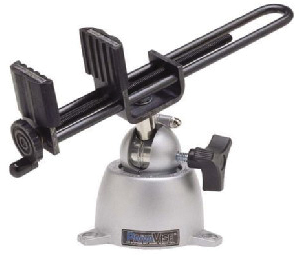
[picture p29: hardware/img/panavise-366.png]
 
 
* **Craft knife.** The plastic case will need small cutouts for power and speaker wires to reach the connectors. A very careful application of a sharp small knife can trim out the holes you need. A craft detail knife such as Fiskars 165110-1002 has better safety and precision than Exacto knives.<br/>


* **Blue painters tape.** While soldering things upside down, an easy-to-remove tape can temporarily hold parts onto the PCB. When you do this, solder only one pin, then double-check the parts are still tight on the PCB. If not, reheat the one pin and press on the part to re-seat it. Then solder the remaining leads.<br/>
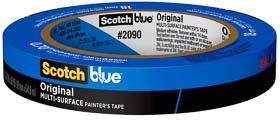
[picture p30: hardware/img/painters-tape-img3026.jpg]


* **Tiny flat head screwdriver.** If you use the 4-terminal strip after assembly (optional), it needs an unusually narrow-bladed screwdriver to reach the recessed screw heads.

* **Ohmmeter.** Use an ohmmeter or VOM (volt-ohm-milliameter) to measure resistors before installation to help ensure you have the right one in the right place.

* **Scosche Magnetic Mount** You'll want a way to mount this in your vehicle within easy view of the driver. The Griduino case can most likely be adapted to almost any popular cellphone mounting system. A particularly convenient and interchangeable system is the **Scosche Magic Mount** product line. It has a magnetic base mounted to the dashboard, and a ferrous plate stuck on the back of a Griduino or cellphone. https://www.scosche.com/
 
<h2>3. Identifying the Components</h2>

Some of Griduino's hardware, such as the connectors and PCB, should be easy to identify. Every connector has a different footprint and will only fit one way.

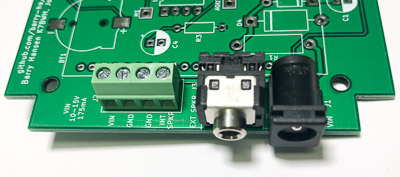
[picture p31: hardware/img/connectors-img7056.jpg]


There are two 8-pin DIPs (dual inline package) chips. Inspect the silkscreen label to identify which is which. Then look closely for a notch at one end -- this helps locate Pin 1. The notch must be oriented the same direction as the semicircle on the PCB.

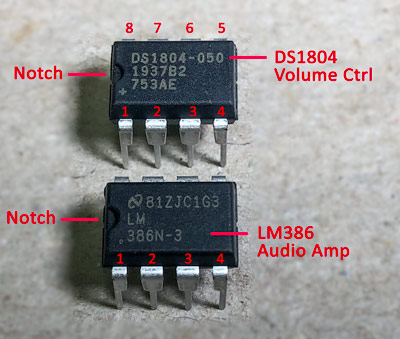
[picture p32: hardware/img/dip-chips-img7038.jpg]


Small 1N4001 diodes are marked with a band on one end for polarity; the band must be oriented the same direction as the band on the PCB. 

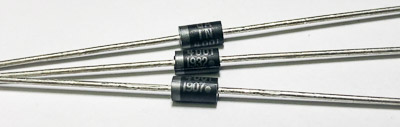
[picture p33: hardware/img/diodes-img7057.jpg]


The larger zener diode, D4, is a TVS protection diode (transient voltage suppressor) for clamping voltage spikes from exceeding +25 or -25 volts. It is bidirectional (not polarized) and can be installed in either orientation.



Electrolytic capacitors are marked with an arrow or "-" to indicate the negative polarity terminal. Also note the "minus" lead is shorter than the other lead. The PCB locations are marked with a filled semicircle (minus) and a small "+" symbol on the other side. When you install electrolytics, mount them flush on the PCB; the image below has extra lead length to show the board markings.

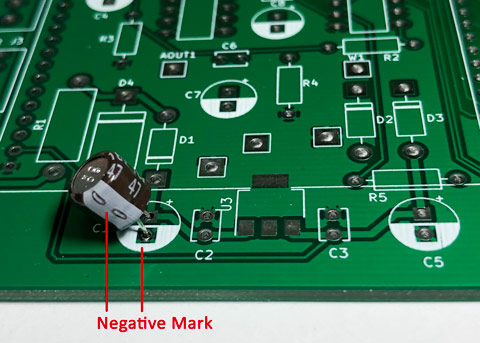
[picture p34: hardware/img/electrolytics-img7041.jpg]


Header pins can join a small PCB onto the main board. They are designed to let you break off the number you need. Use needle nose pliers to hold steady the pins you'll keep and use your fingers to snap off the rest.

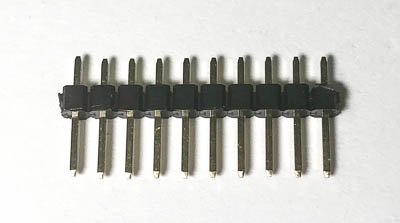
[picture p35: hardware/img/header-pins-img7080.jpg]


<h2>4. Construction Step-By-Step</h2>

You should now be ready to build your Griduino. Here is a step-by-step progression through the assembly process in a recommended order. This order is not compulsory, however it has been chosen to ensure that smaller components are fitted before larger components that may make them difficult to reach for soldering. It is **strongly recommended** that you only unpack one component at a time: that which you are currently installing.

<h3>Step 1: U3 Voltage Regulator</h3>

Start with the small 3-terminal voltage regulator. This is surface-mounted and not a "through hole" component so use a clothespin or surgical clamp or paper clip or anything but your finger to hold it in place while soldering. 

Solder one pin to the board. Remove your clamp. Solder the remaining pins. 

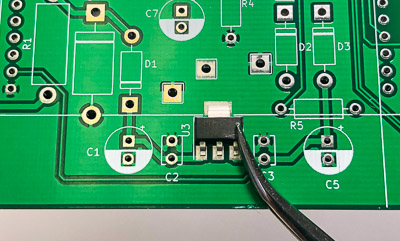
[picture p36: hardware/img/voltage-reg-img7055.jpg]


<h3>Step 2: Diodes</h3>

Insert the three small 1N4001 diodes, D1 - D3, being careful of polarity; match the banded end (cathode) with the board marking. The board also indicates the banded end with a square solder pad. It is good practice to bend its wires in such a way that its marking "4001" is on top and readable.

Solder the three diodes into place and snip off excess wire lengths.

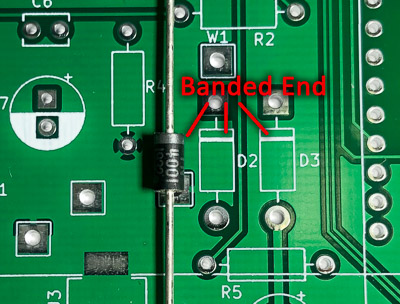
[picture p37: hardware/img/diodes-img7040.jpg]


Insert the larger TVS diode, D4, and solder into place. Although the board marking shows its location with a banded end, this diode is bidirectional and can go either way.

<h3>Step 3: Resistors</h3>

This kit uses five resistors, R1 - R5, each of a different value. Refer to the schematic or bill-of-materials for the values.

Measure the resistance of each item with your ohmmeter before installation. These resistors are very small and it's easy to mistake the color coded bands.

Insert resistor R1 - R5 onto the PCB. It is good practice to orient the color code bands in the same direction; this makes them easier to read.

Solder the five resistors and snip off excess wire lengths.

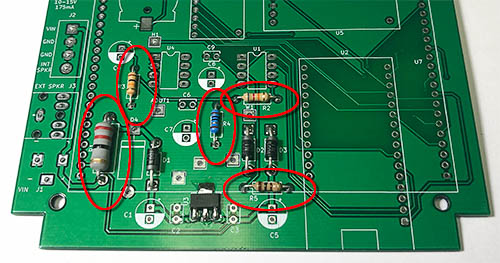
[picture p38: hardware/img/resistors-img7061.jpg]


<h3>Step 4: Small 0.1 uF Capacitors</h3>

The four tiny 0.1 uF ceramic capacitors are all the same, but they're tiny so don't drop them. They are not polarized; however, it is good practice to orient their labels all in the same direction to make it easier to read their legends.

Solder the four small ceramic capacitors onto the PCB and snip off excess wire length.

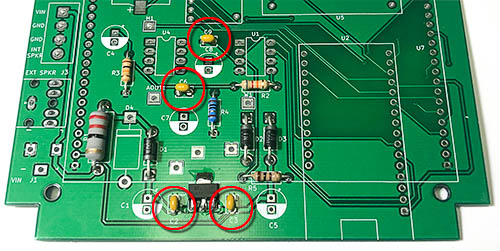
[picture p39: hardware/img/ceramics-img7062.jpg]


<h3>Step 5: Electrolytic Capacitors</h3>

This kit has five identical 47 uF electrolytic capacitors. Be careful of polarity; incorrect installation can cause them to burst and leak acid. The PCB is designed so they are all installed in the same orientation. 

Don't substitute taller capacitors - although they would be electrically equivalent, they won't fit under the display board above them.

Solder only one lead of each electrolytic. Then check that the capacitor is flush with the board. If not, reheat the wire while pushing it down. Then solder the other lead. Snip off excess wire.

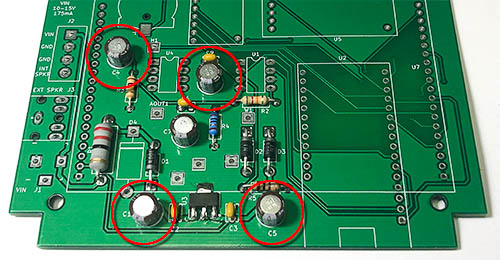
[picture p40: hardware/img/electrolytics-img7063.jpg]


<h3>Step 6: U1 Volume DS1804 and U4 Audio LM386, 8-pin DIPS</h3>

The two 8-pin DIPs (dual inline package) are soldered directly to the board. It is recommended to *not* use a socket so that vibration cannot cause them work loose over time. The notch on the chip must be aligned with the matching semicircle printed on the PCB.

Note: pins on the DIP are slightly wider than the PCB hole spacing. They are designed this way for pick-and-place machines that squeeze DIPS during assembly. You may find it helpful to manually compress the pins together ever so slightly before inserting into the board. Be gentle; if you press too hard the chip flips over and inserts its pins into your thumb.

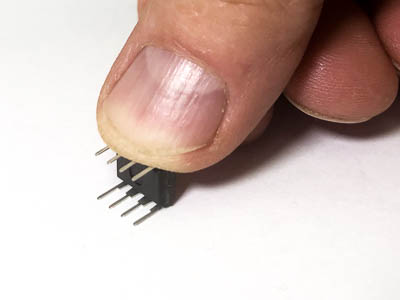
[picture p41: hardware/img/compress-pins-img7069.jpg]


Insert U1 Digital Potentiometer DS1804 and U4 Audio Amplifier LM386 into the PCB. Make sure each chip's notch is oriented to match the board's silkscreen. You may want to tack-solder a single pin from the top to hold the chip in place, before turning over the board to solder all the pins from the bottom.

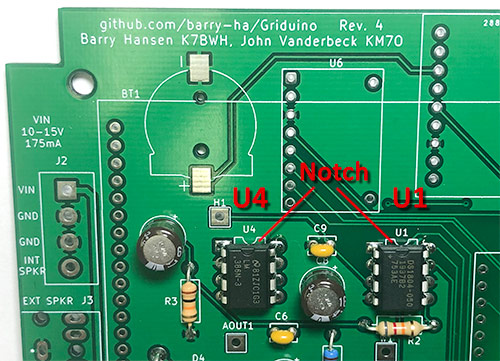
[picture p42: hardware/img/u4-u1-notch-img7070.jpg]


<h3>Step 7: U2 Feather M4 Express</h3>

Test the Feather before using it. By testing first, we ensure it's usable before permanently installing it. To test it, plug a standard micro-USB cable into the Feather's onboard connector; the lights should show activity. If this is a new Feather, it comes with a factory program that shines the NeoPixel LED bright green every two seconds as a simple "hello world" program.

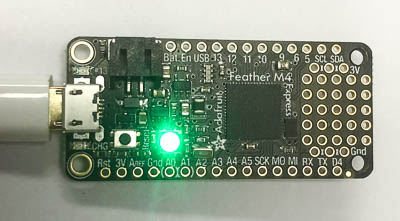
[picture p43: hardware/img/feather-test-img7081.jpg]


The Feather comes with two 16-pin header strips loose in the package. Take one strip and break off 4 pins so it exactly matches the Feather's pinout: one 12-pin strip, and one 16-pin strip. Temporarily put the strips into a solderless breadboard to hold them in precise alignment. The long end of the pins go down into the breadboard; the short end goes into the Feather's PCB. (Actually the long pins can go up *or* down, it doesn't matter. We like them down for a more tidy appearance from the top.) Solder the Feather board to both header pin strips.

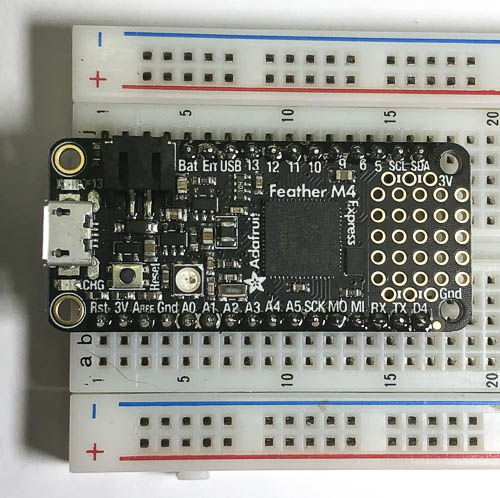
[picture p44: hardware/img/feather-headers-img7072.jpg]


To remove the Feather from the breadboard, carefully work it upward gently from both ends. It can be helpful to lever it *gently* upwards with a small screwdriver from underneath.

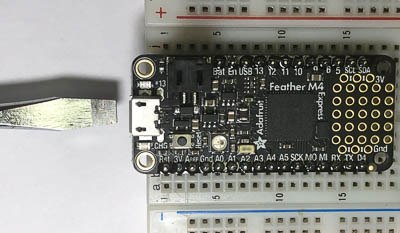
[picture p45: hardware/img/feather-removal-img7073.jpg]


Insert the Feather board into the PCB. Make sure the pins are completely inserted and the Feather is held off the PCB by only the small black part of the header strip. 

<h3 style="color:darkred">Wrong:</h3>

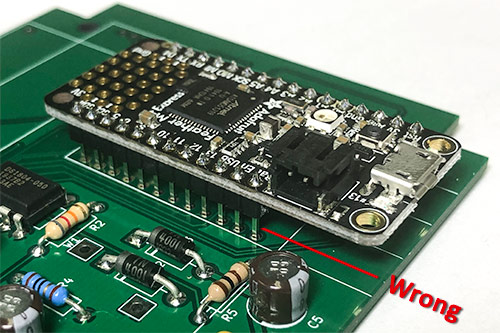
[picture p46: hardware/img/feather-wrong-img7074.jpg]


<h3 style="color:green">Correct:</h3>

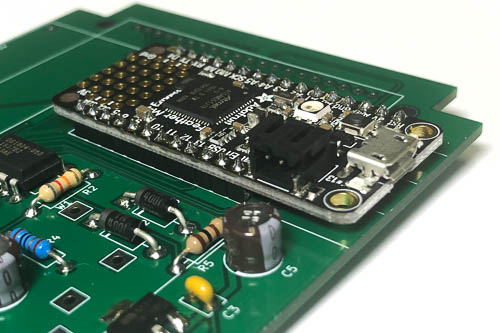
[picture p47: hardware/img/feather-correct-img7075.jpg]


Solder the pins to the Griduino board. You don't need to clip off the long ends; there is ample room inside the case.

<h3>Step 8: U5 Ultimate GPS</h3>

The "Ultimate GPS" package shipped from Adafruit comes with a header strip and a battery holder.

* Count the pins on the supplied header strip. The GPS requires a 9-pin header and sometimes Adafruit may ship an 8-pin header. Add an extra pin from some extra strip, such as the one leftover from the Feather.
* Do not solder a battery holder onto the back of the GPS. It won't hurt anything to have this holder, but it will go unused. Its slot will be unreachable after all the parts are installed. Instead, the Griduino board is designed with a separate coin battery holder, BT1, to replace this one on the back of the Ultimate GPS board.

Insert a 9-pin header pin strip onto the Griduino PCB. Break off two single pins from a leftover strip and insert them into the other two corners. Do not solder them yet. Also shown below are the two battery holders and which one goes on the board in the next step.

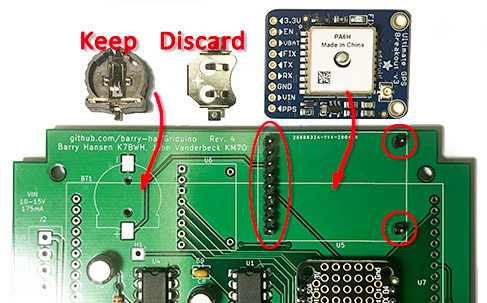
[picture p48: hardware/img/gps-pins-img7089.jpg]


Lower the GPS onto the pins and solder the top pins. The two single pins in the corners only provide physical support and have no other functional purpose.

Tape the GPS assembly in place, if needed. Turn the board over and solder one pin. Check the GPS assembly is still tight to the board. If not, reheat the pin while pushing it down. Solder the remaining pins.

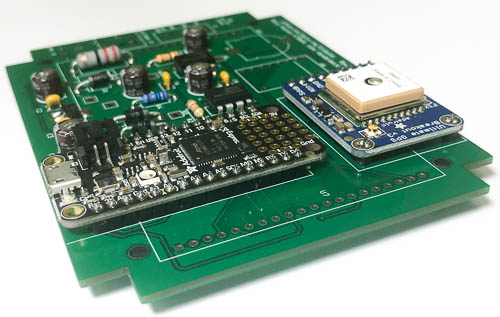
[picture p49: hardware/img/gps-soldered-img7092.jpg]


<h3>Step 9: BT1 Battery Holder</h3>

Solder the battery holder onto the PCB. This is a surface-mount device; note that is has a small plastic detent to precisely align it in place. You might still need a small clamp or clothespin (remember those?) or tape to temporarily hold it in place while soldering. 

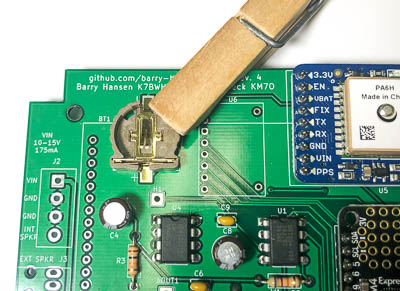
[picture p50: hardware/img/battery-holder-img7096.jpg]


**Do not** insert a battery yet. Put the battery aside until the end to avoid any chance of shorts during construction.

<h3>Step 10: Barometric Pressure Sensor</h3>

The barometric sensor comes with a matching 8-pin header strip. Insert this header strip into the main board, long pins first and short pins extending upward. (Okay, it doesn't really matter but we think this looks better.)

Break off two single pins from a leftover strip and insert them into the other two corners. The two single pins in the corners are for physical support and have no other functional purpose. Do not solder them yet.

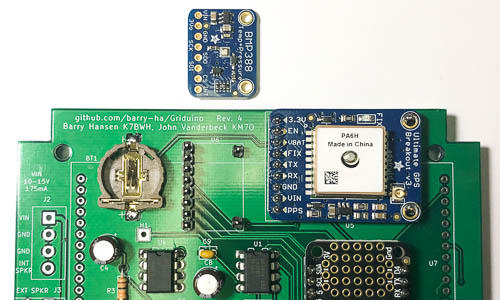
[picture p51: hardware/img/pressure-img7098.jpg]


Lower the barometric sensor mini-board onto the pins and solder the top pins. 

If needed, clamp or tape the pressure sensor in place, and turn over the assembly and solder one pin on the end of the strip on the bottom of the board. 

Check the assembly is still tight to the board. If not, reheat the pin while pushing the assembly tight to the board. Solder the remaining bottom pins, and solder any remaining top pins.

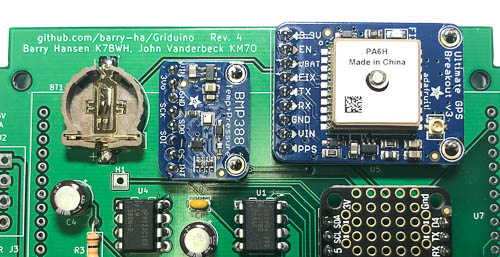
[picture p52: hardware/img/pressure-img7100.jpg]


<h3>Step 11: U7 Display ILI9341</h3>

First, solder jumpers IM1/IM2/IM3 on the back of the board. Melt a solder bridge across each "jumper". The traces are close together to make this easier. This enables the SPI interface. Do not solder jumper IM0.

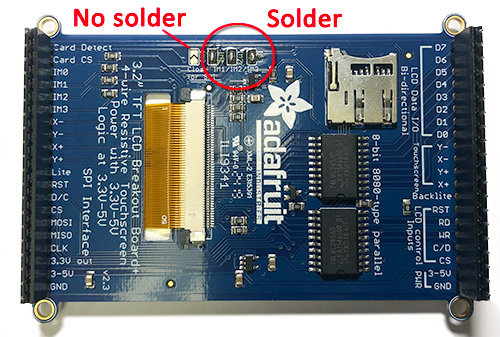
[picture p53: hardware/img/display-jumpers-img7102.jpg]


Note the orientation of the 3.2" TFT display board is important:

* The two **GND pins** must go nearest to the USB connector. 
* The corner with **CD and CCS pins must go nearest to the GPS**; this is the SPI interface that Griduino uses. The other side with pins D0-D7 is the parallel port which is unused.

Assemble the display parts on the main board, which will hold everything in correct alignment before soldering:

1. Start with Griduino main board
2. Insert two 20-pin sockets
3. Insert one 20-pin header in the socket nearest GPS
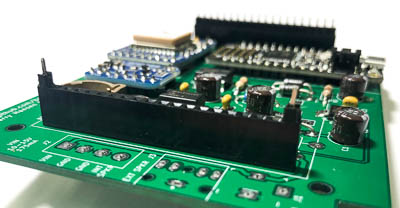
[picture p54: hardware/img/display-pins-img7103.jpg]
4. Break off two 1-pin headers and insert them in the socket aligned with the outer holes on the opposite side of the display; these will physically support the display.<br/>
4. Lower the display board onto the pins, spanning all the parts underneath. 
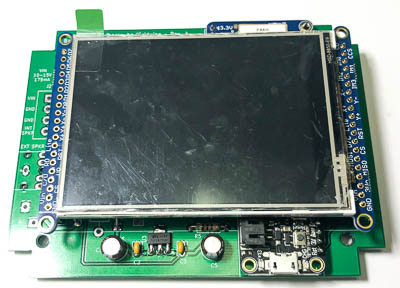
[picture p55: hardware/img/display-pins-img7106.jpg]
5. Check pin alignment and orientation of the display. The two GND pins go along the USB connector side.<br/>

From the top, solder the header pins on the display board.

Turn it over, holding the display assembly together, and rest the display on a soft surface. Solder the socket pins on the bottom of the main board.

Turn it right side up and gently unplug the display from the sockets for safekeeping while working on other parts. Later, when everything else is completed, the display will be inserted again.

<h3>Step 12: Test Points</h3>

Griduino has 6 optional test points. Three grounding points are together near the voltage regulator and the other three are in the audio chain for checking sound levels and linearity. See the schematic for details. Test points are intended for software developers and are not used during assembly.

The test points are sized to wedge into their holes up to their shoulders, holding them in place while you turn the board upside down and solder them.

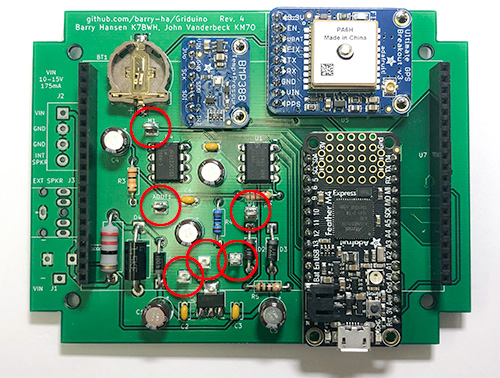
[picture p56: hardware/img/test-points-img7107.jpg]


<h3>Step 13: Connectors</h3>

Lastly, insert and solder the power connector, speaker jack and 4-pin terminal strip into place. Be sure to orient the terminal strip so its openings face outwards. Most of these connectors extend slightly beyond the edge of the PCB, so they are installed after everything else to avoid interfering with the bench vise hardware.

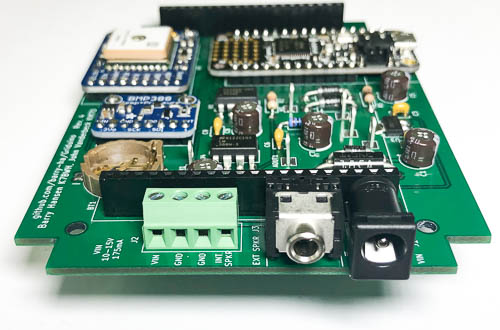
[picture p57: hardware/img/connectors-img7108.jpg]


<h3>Step 14: Plastic Case</h3>

The Griduino kit comes with a plastic enclosure from <a href="https://www.polycase.com/">Polycase</a> in their QS Series that exactly matches the PCB mounting holes. Other enclosures could probably be used. If you choose something else, avoid metallic cases since they would block the microwave GPS signal.

*Bottom Half:* Screw the PCB onto the bottom half of the case. Use a craft detail knife to notch out a square hole for each of the three connectors (speaker, power, USB connector). The exact size depends on your particular cable that you choose to use.  For sake of sizing the hole, find a USB cable that has the largest connector available. 

*Top Half:* There are at least three choices for the top cover.

* No cover – this is how I use my Griduino.
* Polycase cover – carefully cut an opening to fit the display. You'll have to come up with your own cutting template. It's not recommended to cut an opening because it's difficult to do accurately and neatly.
* 3D printed cover – The author designed a top cover to fit the Polycase bottom half. The STL design file is available upon request so you can print and decorate your own.<br/>
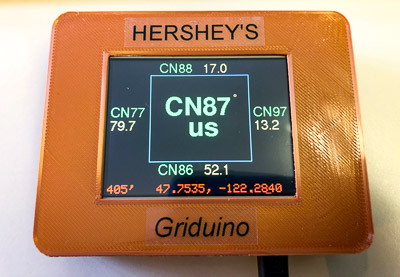
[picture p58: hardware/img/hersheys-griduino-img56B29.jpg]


<h3>Step 15: Speaker</h3>

You can connect a small 8-ohm or 4-ohm speaker to the stereo plugin jack or to the screw terminal strip.

Note that both the speaker jack and speaker plug must be standard stereo connectors. (Do not use a mono plug: it will result in muted or very low volume.) However, this kit can only generate a single audio channel and it is connected to both sides of the stereo jack.

If you have a speaker wired to the 4-screw terminal strip, it will automatically be disconnected when you plug something in to the audio speaker jack.

For a good audio quality speaker and sufficient volume to fill a car and overcome road noise, Adafruit part number 3351 is recommended. This small speaker can be glued to the back of Griduino case. 

Note that increased audio volume is available when powering the Griduino from a car’s electrical system with 10-15 vdc, compared to powering it from the 5v USB connector.

<h2>5. Before You Use It</h2>

Snap a coin cell battery (3-volt CR1220 lithium) into the battery holder.

Plug in the display board.

You should now have a completed Griduino GPS kit. Congratulations! 

Before you connect power, make a detailed visual inspection under a magnifier and good light. Look for *un*soldered pads and fix them. Look for possible solder bridges that may have formed between adjacent pads. Remove any surplus solder or solder bridges with desoldering braid. 

A visual check is **very important** because short circuits or solder bridges can damage the power supply, the battery, the TFT display or the Feather M4. **If that happens it is your responsibility as the builder of the board.** It is better to have to rework or desolder something than to damage it. 

Visually check that the display is correctly plugged in to its two sockets. Look for isolated pins at each end that are not engaged in the socket. If it is accidentally mis-aligned onto the wrong pins, the power supply circuit is likely to be damaged. (Don't ask us how we know.)

<h2>6. First Power Up</h2>

Connect a micro-USB cable to the Feather M4 Express connector. If this is a factory-fresh Feather, you should see:

* Backlight turns on for the display
* Yellow LED flashes rapidly
* NeoPixel LED flashes green once per second
* No text or graphics is shown on the display
* No audio is produced by the speaker

<h2>7. Programming the Griduino GPS</h2>

To load the Griduino programming onto your device, please refer to the open-source project on GitHub:

https://github.com/barry-ha/Griduino

Find the PROGRAMMING.md file for complete programming instructions.

The Griduino hardware platform offers a great deal of capability with a bright colorful display, powerful cpu, GPS receiver, barometric sensor, and a digital audio channel. We hope you invent fun and useful new things for it to do.

You may find the "examples" folder useful. It contains a variety of smaller programs that were used to develop certain concepts and check out features. For example, the barograph display can be a handy desktop application, showing the last 48 hours of barometric pressure and 1-hour and 3-hour trends.

<h2>8. Using the Griduino GPS</h2>

After loading and running the Griduino program, touch the top half of the screen to advance from one view to the next:

1. Power-up animation (one time only)<br/>


2. Credits screen (one time only)<br/>


3. Help screen (one time only)<br/>


4. Grid location view<br/>


5. Grid details view<br/>


6. GMT clock view<br/>


7. Audio volume control<br/>


8. Settings<br/>


Touch the bottom half of the screen to adjust brightness levels.

Griduino has non-volatile storage to save your breadcrumb trail (driving track) from one day to the next. 

For a demonstration, bring up the **Settings** view. Change the Route to **Simulator** and return to the main grid view. It follows a pre-programmed route to show the breadcrumb trail and what happens at grid crossings. There are a few different routes available, which can be selected at compile-time. The most interesting canned route will drive in a big ellipse near the edges of one grid square. 

When you cross a grid line, the new grid is announced with CW on the speaker.

When you arrive at a destination, you can switch to the GMT clock view. This is useful to visually compare to your computer clock for accurate time.

<h2>9. Disclaimer</h2>

The information provided is for general education and entertainment. We hope you learn from this and enjoy your hobbies in a safe manner with this new GPS information available at a glance. We take no responsibility for your assembly and construction, nor for how you use these devices. 

**Do not adjust Griduino while driving**. Keep your full attention on the road and the traffic around you. We can not be held responsible for any property or medical damages caused by these projects. You are advised to check your local laws and consult professionals for any project involving electricity, construction or assembly. You are advised to drive in a safe and legal manner, consistent with all local laws, safety rules and good common sense.

You must accept that you and you alone are responsible for your safety and safety of others in any endeavor in which you engage.

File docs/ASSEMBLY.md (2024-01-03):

# Griduino Kit Assembly Instructions

## 1. Introduction

Griduino logoThank you for purchasing a Griduino GPS navigation kit. Once assembled, this kit is a useful driver's aid dedicated to show your location in the Maidenhead grid square system, your altitude, the exact time in GMT, barometric pressure and more. Further, the hardware is a highly capable platform for programming your own features.



These assembly instructions apply to Revision 4 of the printed circuit board.



## 2. You Will Need

This kit is almost entirely "through hole" construction. Only two components, the battery holder and voltage regulator, are large surface-mount parts.

### You must have:

* **Printed BOM and schematic diagram.** The component values are found on the bill of materials and the schematic. Both of these are available in the (hardware)[https://github.com/barry-ha/Griduino/tree/master/hardware] folder of GitHub. For example, to learn that R1 is a 22-ohm 2-watt resistor, you'll find it in the BOM or schematic. These assembly instructions generally *don't* include part values in an attempt, possibly futile, to avoid multiple documents getting out of sync. The schematic is your ultimate golden master reference for all Griduino design. This is an open-source project and the latest documents are available on https://github.com/barry-ha/Griduino.

* **Fine-tipped soldering iron.** A standard fine-tipped iron suitable for use with conventional 0.1” pitch through-hole components.  It is recommended that you use a temperature controlled iron at a suitable temperature for your solder, if you have one. It is assumed that you will already have the necessary skills to solder this kit. If however you are not comfortable with through-hole electronic soldering, there are plenty of soldering tutorials available online.

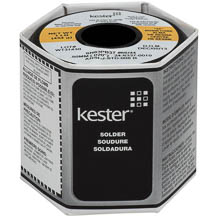
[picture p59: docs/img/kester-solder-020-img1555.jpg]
* **Solder with a flux core.**  Any decent quality, thin, flux-cored solder for electronics will work. Solder diameter of 0.031" is good and 0.020" (0.50 mm) is better. Do not use solder intended for plumbing. <br/>Some people like to use "no clean" solder but personally I've not had good luck it. We recommend something like Kester 245 63% Tin 37% Lead, part number [24-6337-0010](https://www.amazon.com/dp/B00068IJWC/ref=cm_sw_em_r_mt_dp_dfmcGb5707H9N). If the look of flux residue is bothersome, clean it with 91% isopropyl alcohol. Don't clean the _front_ of the PCB because alcohol can remove the silkscreen lettering.<br/>

* **Needle nose pliers.** The component's leads must be bent with small pliers for a good fit into holes. Small pliers are also good for picking up the smallest parts from a tray.

* **Side cutters.** After you solder discrete components to the board, you will need to clip off the protruding wires. Wear eye protection and aim the bits away from you in a safe direction.

* **Philips-head screwdriver.** Four small screws attach the PCB into the case. Four more screws attach the top cover to the bottom case.

### It will be nice to have:

* **Hobbyist bench vise.** You'll want a way to hold the PCB at a convenient height and angle for soldering parts. A small adjustable bench vise, such as a <a href="https://www.panavise.com/">Panavise Model 366</a>, will make your task easier. Use a holder wide enough to grip the Griduino PCB of 4-1/2" width.<br/>
 

* **Solderless breadboard.** A solderless breadboard can hold pins in exact alignment while soldering header pins onto small board assemblies. However, it works just as well to solder header pins while placed on the PCB.<br/>


* **Craft knife.** The plastic case might need optional small cutouts to bring wires into the case, depending on how you choose to connect power and speakers. A careful application of a sharp knife can trim out notches or holes. A craft detail knife such as Fiskars 165110-1002 has better safety and precision than Exacto knives.<br/>


* **Blue painters tape.** While soldering things upside down, an easy-to-remove tape is one way temporarily hold parts onto the PCB. When you do this, solder only one pin, then double-check the parts are still tight on the PCB. If not, reheat the one pin and press on the part to re-seat it. Then solder the remaining leads.<br/>


* **Tiny flat head screwdriver.** If you use the 4-terminal strip after assembly (optional), it needs an unusually narrow-bladed screwdriver to reach the recessed screw heads. A "jeweler's screwdriver" will work well here.

* **Surgical clamp** or **clothespin** can be helpful to hold small parts onto the PCB. For example, the flat voltage regulator chip is a surface-mount device that needs something to accurately hold it in place to solder its first pin.

* **Ohmmeter.** Use an ohmmeter or VOM (volt-ohm-milliammeter) to measure resistors before installation to help ensure you have the right one in the right place.

* **Scosche Magnetic Mount.** Eventually you'll want a way to mount this in your vehicle within easy view. The Griduino case can most likely be adapted to almost any popular cellphone mounting system. A particularly convenient and interchangeable system is the **Scosche Magic Mount** product line. It has a magnetic base mounted to the dashboard, and a ferrous plate stuck on the back of a Griduino or cellphone. https://www.scosche.com/

## 3. Identifying the Components

Some of Griduino's hardware, such as the connectors and PCB, should be easy to identify. Every connector has a different footprint and will only fit one way.



To identify the two 8-pin DIPs (dual inline package), inspect the silkscreen label to identify which is which. Then look closely for a notch at one end -- this helps locate Pin 1. The chip's notch must be oriented the same direction as the PCB's semicircle.



Small 1N4001 diodes are marked with a band on one end for polarity; the band must be oriented the same direction as the band on the PCB.



The larger zener diode, D4, is a TVS protection diode (transient voltage suppressor) for clamping voltage spikes from exceeding +25 or -25 volts. It is bidirectional (not polarized) and can be installed in either orientation.



Electrolytic capacitors are marked with an arrow or "-" to indicate the negative polarity terminal. Also note the "minus" lead is shorter than the other lead. The PCB locations are marked with a filled semicircle (minus) and a small "+" symbol on the other side. When you install electrolytics, mount them flush on the PCB; the image below has extra lead length to show the board markings.



Header pins can join a small PCB onto the main board. They are designed to let you break off the number you need. Use needle nose pliers to hold steady the pins you'll keep and use your fingers to snap off the rest.



## 4. Construction Step-By-Step

You should now be ready to build your Griduino. We recommend this step-by-step progression through the assembly process, chosen to install the smaller components before the larger components which makes them easier to solder into place. We recommend that you only unpack one component at a time: that which you are currently installing.

### Step 1: U3 Voltage Regulator

Start with the small 3-terminal voltage regulator. This is surface-mounted and not a "through hole" component so use a clothespin or surgical clamp or paper clip or anything but your finger to hold it in place while soldering.

Solder one pin to the board. Remove your clamp. Solder the remaining pins.



### Step 2: Diodes

Insert the three small 1N4001 diodes, D1 - D3, being careful of polarity; match the banded end (cathode) with the board marking. The board also indicates the banded end with a square solder pad. It is good practice to bend its wires in such a way that its marking "4001" is on top and readable.

Attention: Diode D1 on the PCB is turned in the opposite direction of D2 and D3.

Solder the three diodes into place and snip off excess wire lengths.

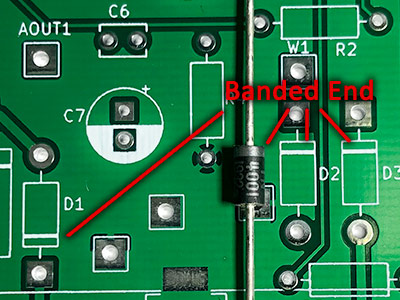
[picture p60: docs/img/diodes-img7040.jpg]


Insert the larger TVS diode, D4, and solder into place. Although the board marking shows its location with a banded end, this diode is bidirectional and can go either way.

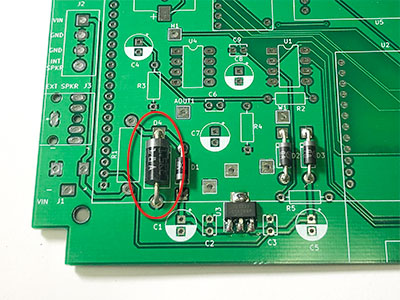
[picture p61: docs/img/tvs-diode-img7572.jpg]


Automobiles are "the power supply from hell." The TVS diode protects the Griduino from wild voltage spikes in either direction. 

### Step 3: Small 0.1 uF Capacitors

The four tiny 0.1 uF ceramic capacitors are all the same, but they're tiny so don't drop them. They are not polarized; however, it is good practice to orient their labels all in the same direction to make it easier to read their legends.

Solder the four small ceramic capacitors onto the PCB and snip off excess wire length.



### Step 4: Resistors

This kit uses five resistors, R1 - R5, each of a different value as shown in the v4 [bill-of-materials](https://github.com/barry-ha/Griduino/blob/master/hardware/bill_of_materials.md#passive-components "BOM") or [schematic](https://github.com/barry-ha/Griduino/blob/master/hardware/Griduino%20v4%20Schematic%202020-04-28.png):

1. R1 = 22 ohms, 2-watt
2. R2 = 82K
3. R3 = 10K
4. R4 = 10 ohm
5. R5 = 100 ohm

Measure the resistance of each item with your ohmmeter before installation. These resistors are very small and it's easy to mistake the color coded bands.

Insert resistor R1 - R5 onto the PCB. It is good practice to orient the color code bands in the same direction; this makes them easier to read.

Solder the five resistors and snip off excess wire lengths.



### Step 5: Electrolytic Capacitors

This kit has five identical 47 uF electrolytic capacitors. Be careful of polarity; incorrect installation can cause them to burst and leak acid. The PCB is designed so they are all installed in the same orientation.

Don't substitute taller capacitors - although they would be electrically equivalent, they won't fit under the display board above them.

If your electrolytic capacitors are taped onto a strip, as in for automatic insertion machines, then clip the leads off the strip. This is the easiest way to free the capacitor. Otherwise the tape's residue may stick to the wires and interfere with assembly.

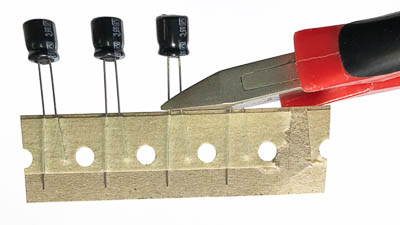
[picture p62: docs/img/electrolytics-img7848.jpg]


Solder only one lead of each electrolytic. Then check that the capacitor is flush with the board. If not, reheat the wire while pushing it down. Then solder the other lead. Snip off excess wire.

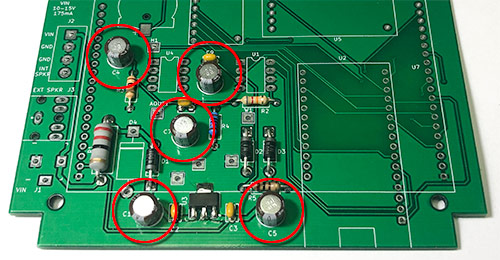
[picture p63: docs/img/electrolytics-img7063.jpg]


### Step 6: U1 Volume DS1804 and U4 Audio LM386, 8-pin DIPS

The two 8-pin DIPs (dual inline package) are soldered directly to the board. It is recommended to *not* use a socket so that vibration cannot cause them work loose over time. The notch on the chip must be aligned with the matching semicircle printed on the PCB.

Note: pins on the DIP are slightly wider than the PCB hole spacing. They are designed this way for pick-and-place machines that squeeze DIPS during assembly. You may find it helpful to manually compress the pins together ever so slightly before inserting into the board. Be gentle; if you press too hard the chip flips over and gently inserts its pins deep into your thumb.

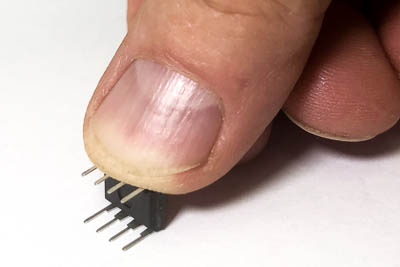
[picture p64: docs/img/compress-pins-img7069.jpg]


Insert U1 Digital Potentiometer DS1804 and U4 Audio Amplifier LM386 into the PCB. Make sure each chip's notch is oriented to match the board's silkscreen. You may want to tack-solder a single pin from the top to hold the chip in place, before turning over the board to solder all the pins from the bottom.

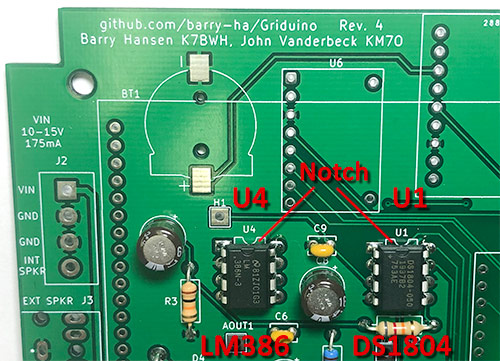
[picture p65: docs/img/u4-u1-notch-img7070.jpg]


### Step 7: Test Points

Griduino has 6 optional test points. Three grounding points are together near the voltage regulator and the other three are in the audio chain for checking sound levels and linearity. See the schematic for details. Test points are intended to attach an oscilloscope during software development and are not normally used.

The test points are sized to wedge into their holes up to their shoulders, holding themselves in place while you turn the board upside down and solder them.

Some people say the test points are easier to solder from the top side if you have a good fine-tip soldering iron.



### Step 8: Testing Feather M4 Express

Test the Feather before using it. By testing first, we ensure it's functional before permanently installing it. After soldering it in place, it will be very difficult to remove.

To test a Feather, plug a standard micro-USB cable into the onboard connector; the lights should show activity.

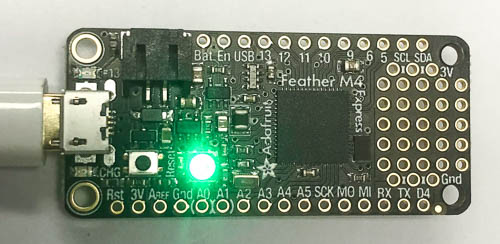
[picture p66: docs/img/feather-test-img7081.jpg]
* If this is a new Feather, it comes with a factory program that blinks the NeoPixel LED in *green* as a simple "hello world" program. <br>

* If this is *not* a new Feather, you can replace its programming. Get the [Blinky](https://learn.adafruit.com/adafruit-arduino-lesson-2-leds/blinking-the-led) demo program to blink the *red* LED, then compile and install the program using the Arduino workbench. <br>

### Step 9: Installing Feather M4 Express

The Feather comes with two 16-pin header strips loose in the package. Take one 16-pin strip and break off 4 pins so it exactly matches the Feather's pinout: one 12-pin strip, and one 16-pin strip.

Keep the small 4-pin piece that you separated. We'll use all of them later: two pins for the barometric sensor, two pins for the display.

Put the header strips into the PCB; this ensures precise alignment. The long end of the pins go down into the breadboard; the short end goes into the Feather's PCB. (Don't put the long pins *up* or they will collide with the display hardware above it.)



Put the Feather board onto the header strips.



Solder the top pins only.

Make sure the pins are completely inserted and the Feather is held off the PCB by only the small black part of the header strip.

<h3 style="color:darkred">Wrong:</h3>



<h3 style="color:green">Correct:</h3>



Solder one bottom pin to the PCB. Check again the header strips remained flush against the board. Solder the remaining pins.

You don't need to clip off the long ends; there is ample room inside the case.

It's a good idea to test the Feather once again with the Blinky program.

If the Feather's LED doesn't blink as expected, don't panic; sometimes the computer acquires the Feather M4 as an external drive identified as CIRCUIT.PY or FEATHERBOOT. Check the computer's list of drives to see if that's the case. Unplug and reconnect the Feather several times until it blinks its light.

### Step 10: Barometric Pressure Sensor

The barometric sensor comes with a matching 8-pin header strip. Insert this header strip into the main board, long pins first and short pins extending upward. (Okay, it doesn't really matter but we think this looks better.)

If you have a **BMP-388**, break off two single pins from a leftover strip and insert them into the other two corners. The two single pins in the corners are for physical support and have no other functional purpose. Do not solder them yet.

If you have a **BMP-388 after June 2022**, do not insert single-pin supports. Adafruit moved the two support holes and they no longer align with the PCB holes. Ignore the supports; they are not required.

If you have a **BMP-390**, do not insert two single-pin supports. The BMP-390 breakout board is pin-compatible but a different size and the support holes don't line up.



Lower the barometric sensor mini-board onto the pins and solder the top pins.

If needed, clamp or tape the pressure sensor in place, and turn over the assembly and solder one pin on the end of the strip on the bottom of the board.

Check the assembly is still tight to the board. If not, reheat the pin while pushing the assembly tight to the board. Solder the remaining bottom pins, and solder any remaining top pins.



### Step 11: BT1 Battery Holder

Solder the battery holder onto the PCB. This is a surface-mount device; note that it has a small plastic detent to precisely align it in place. You might still need a small clamp or clothespin (remember those?) or tape to temporarily hold it in place while soldering.



**Do not** insert a battery yet. Put the battery aside until the end to avoid any chance of shorts during construction. In fact, the battery is optional. Its only purpose is to maintain the RTC (real time clock) while Griduino is turned off, thereby reducing the wait-time for GPS synch.

### Step 12: U5 Ultimate GPS

The "Ultimate GPS" package shipped from Adafruit comes with a header strip and a battery holder.

* Count the pins on the supplied header strip. The GPS requires a 9-pin header and sometimes Adafruit may ship an 8-pin header. If needed, add an extra pin from some extra strip, such as the one leftover from the Feather.
* Do not solder a battery holder onto the back of the GPS. It won't hurt anything to have this holder, but it will go unused. Its slot will be unreachable after all the parts are installed. Instead, our Griduino board is designed with a separate coin battery holder, BT1, to replace the one on the Ultimate GPS board.

Insert a 9-pin header pin strip onto the Griduino PCB. Break off two single pins from a leftover strip and insert them into the other two corners. Do not solder them yet. Also shown below are the two battery holders and which one goes on the board.



Lower the GPS onto the pins and solder the top pins. The two single pins in the corners only provide physical support and have no other functional purpose.

Tape the GPS assembly in place, if needed. Turn the board over and solder one pin. Check the GPS assembly is still tight to the board. If not, reheat the pin while pushing it down. Solder the remaining pins.



### Step 13: U7 Display ILI9341

First, solder jumpers IM1/IM2/IM3 on the back of the board. Melt a solder bridge across each "jumper". The traces are close together to make this easier. This enables the SPI interface. Do not solder jumper IM0.



Turn the display-side up. Note the orientation of the 3.2" TFT display board is important:

* The two **GND pins** must go nearest to the USB connector.
* The corner with **CD and CCS pins must go nearest to the GPS**; this is the SPI interface that Griduino uses. The other side with pins D0-D7 is the parallel port which is unused.



**Warning:** Always insert the display in this orientation. The circuit will be damaged if you reverse it. Don't ask me how I know.

To help make the proper orientation obvious, we will mount different connectors on each side.

These steps will solder the fragile pins onto the PCB, and the sturdier sockets onto the display board. This makes it easier to set the display aside without bending pins or stabbing defenseless fingers.

Assemble the display parts on the main board, which will hold everything in correct alignment before soldering:

1. Start with main Griduino PCB
1. Insert one 20-pin header on the PCB to the right of the Feather, **long pins facing up**.
1. Insert two 2-pin headers on the PCB along the left edge, one at each end of the row of 20 holes, **long pins facing up**. These will physically support the display.<br/>
1. Insert one 20-pin socket on the display, matching the 20-pin header.
1. Insert two 2-pin sockets on the display, matching the 2-pin headers on the PCB.
1. Lower the display board onto the pins, spanning all the parts underneath.
1. Check pin alignment and orientation of the display.<br/>

Before you solder, gently wiggle the display to feel where the assembly is centered with the least stress and tension. This is the exact spot that will ultimately center the display into the cutout window of the plastic case. It will save work later to center the display onto the PCB as well as possible.

From the top, solder one pin on the display. It will start to feel more firmly mounted and you can check the alignment. When you like the position, solder one more pin and check again.

From the top, solder all pins on the display board.

Turn it over, holding the assembly together, and rest the display on a soft surface. Solder all socket pins on the bottom of the main board.

Hey, want to check your work? At this point of assembly, you can plug in USB power: The Blinky program will flash the red LED and the backlight will turn on. You can even load the Griduino program and it will basically work fine except it lacks its connectors to the world.

Turn the assembly right side up and gently unplug the display from the sockets for safekeeping while working on other parts. Later, when everything else is completed, the display will be inserted again.

### Step 14: Connectors

Lastly, insert and solder the power connector, speaker jack and 4-pin terminal strip into place. Be sure to orient the terminal strip so its **openings go toward the edge**. Most of these connectors extend slightly beyond the edge of the PCB, so they are installed after everything else to avoid interfering with your bench vise hardware.



### Step 15: Bottom Half of Plastic Case

The Griduino kit comes with  a plastic enclosure from <a href="https://www.polycase.com/">Polycase</a> in their QS-50 Series that exactly matches the PCB mounting holes. Other enclosures could probably be used. If you choose something else, avoid metallic cases since they would block the microwave GPS signal and would need an external antenna.

Temporarily position the PCB in bottom half of the Polycase enclosure. Check for interference and, if needed, use a craft detail knife to notch out holes for each of the three connectors (speaker, power, USB connector). The exact size depends on your particular cable that you choose to use.  For sake of sizing the USB hole, find a USB cable that has the largest connector available.

Screw the PCB onto the case's mounting posts, watching the speaker and power jacks clearance. You may need to carve a little extra room in the cutouts, even with the custom-milled case, depending on how the jacks were soldered onto the board.

Don't overtighten the PCB screws. These are short, small screws and can be easily stripped.

**Optional:** You can buy an active external antenna for this GPS from other vendors. The GPS has a "uFL" connector so be aware that you may need an [SMA to uFL RF Adapter Cable]([https://www.adafruit.com/product/851), depending on your choice of antenna.

**Optional:** If you'd like to run wires (e.g. power or speaker) through the back of the case, then drill a 3/16" hole (9 mm) at the position the mark in the mold as shown in the photo below.



There is just enough room for a few thin wires to fit between the PCB and the case, allowing them to exit through your drilled hole. Here's an example of speaker wires escaping out the back for an instance where the speaker was glued to the back of the case.



**Optional:** The Griduino kit includes optional nylon #6 washers that can go under the mounting posts as a standoff. Put these aside for later. They can help close a possible gap between the display and top cover surface.

### Step 16: Top Half of Plastic Case

There are several choices for the top cover. Choose one of these according to your desires and what you have available.

### 16.a No cover

This is how I use my Griduino. This is the easiest way to reach the Reset button during software development or to double-click the Reset button to apply pre-compiled software updates.

### 16.b Polycase standard cover

If you have the unmodified [Polycase QS50](https://www.polycase.com/qs-50), carefully cut an opening to fit the display. A [manual cutting template](https://github.com/barry-ha/Griduino/tree/master/hardware) can be printed and taped on for guidance.  Cutting the top cover's opening by hand is actually rather difficult to do accurately and neatly.

Carefully cut openings for the connectors and display with a sharp craft knife.



### 16.c Polycase custom-milled cover

This is the easiest approach to a professional-looking cover.



During final assembly, check the alignment and clearance as you lower the top case onto the bottom cover.

Examine the audio jack's opening. You will probably need to clean up a little extra plastic from the top cover for the round jack.

If the display is not quite centered in the opening, loosen the PCB screws and adjust its location slightly to line up correctly.

If there's a gap between the display and the top cover, use nylon #6 washers under the PCB to raise the interior assembly and close the gap.

### 16.d 3D printed cover

We designed a 3D printed top cover to fit the Polycase bottom half. The STL design file is available on request so you can print and decorate your own. Here's an example of a 3D printed cover in "gold" PLA. <br/>
<br>

We recommend 3D printing with PETG or ABS (instead of PLA) for improved durability and UV resistance.

<h3 id="speaker">Step 17: Speaker</h3>

You can connect a small 8-ohm or 4-ohm speaker either to the stereo plugin jack or to the screw terminal strip.

Note the speaker *plug* must be a standard stereo connector. The correct plug is included in the kit. Do not use a mono plug: it will result in muted or very low volume. This kit only generates a single audio channel which is connected to both sides of the stereo jack.

If you insert a speaker plug into the jack, it will automatically disconnect the speaker, if any, connected to the 4-terminal strip. Actually, it can be handy to jam in a plug to quickly silence the wired speaker during testing.

A good audio quality speaker is the Adafruit [part number 3351](https://www.adafruit.com/product/3351). This has sufficient volume to fill a car and overcome road noise.

This speaker can be glued to the back of the Griduino case. Gluing this with the "paper cone out" offers the most volume for noisy vehicles but puts the fragile speaker cone at risk.



Gluing or screwing this with the paper cone *in* toward the case will protect it from damage. The speaker has a small port vent and one end to let sound out. It's not as loud in this orientation but has proven to be sufficiently clear and audible.



Note that additional clarity (less distortion) at high audio volume is available when powering the Griduino from a car’s electrical system with 10-15 vdc, compared to powering it from the 5v USB connector. The higher voltage source reduces clipping at higher volume levels. At lower volume levels, the speaker sounds the same regardless of power source.

<h3 id="power">Step 18: Power Plug</h3>

You can optionally power Griduino from a battery or your vehicle:

* Power plug is positive on center pin and ground on the outer barrel
* It needs 10-15 vdc and up to 175 mA

Using voltage from your car is often called “the power supply from hell” so it's designed to be well protected:

* Griduino has an internal regulator and filtering for its 12v power input.
* An input diode protects Griduino if the 12v polarity is accidentally reversed.
* A TVS diode (transient voltage suppression) protects Griduino from voltage spikes.
* There’s no problem if you connect both the power plug and a USB cable at the same time.

Which power source, 12v or USB, is best? Not much difference, really. Use the one that’s most convenient. There is a minor advantage in running from 12vdc since the additional headroom allows more speaker volume before audio clipping sets in.

## 5. Before You Use It ##

Snap a coin cell battery (3-volt CR1220 lithium) into the battery holder. Flat side is positive (+) and faces up.

Plug in the display board, checking the pin alignment on all four corners. **Important:** The display's ribbon connector must go to the right. Connecting it in the wrong orientation will damage the display or the on-board power supply.

You should now have a completed Griduino GPS kit. <span style="green">**Congratulations!**</style>

Before you connect power, make a detailed visual inspection under a magnifier and good light. Look for *un*soldered pads and fix them. Look for possible solder bridges that may have formed between adjacent pads. Remove any surplus solder or solder bridges with desoldering braid.

A visual check is **very important** because short circuits or solder bridges can damage the power supply, the battery, the TFT display or the Feather M4. **If that happens, it is your responsibility as the builder of the board.** It is better to have to rework or desolder something than to damage it.

Visually check that the display is correctly plugged in to its two sockets. Look for isolated pins at each end that are not engaged in the socket. If it is accidentally mis-aligned onto the wrong pins, the power supply circuit is likely to be damaged. (Don't ask us how we know.)

## 6. First Power Up

Connect a micro-USB cable to the Feather M4 Express connector. If this is a factory-fresh Feather, you should see:

* Backlight turns on for the display
* Yellow LED flashes rapidly
* NeoPixel LED flashes green once per second (or the Blinky program will flash the red LED)
* No text or graphics is shown on the display
* No audio is produced by the speaker

## 7. Programming the Griduino GPS

You can download the latest pre-compiled binary image from GitHub. To load the Griduino programming onto your device, please see the documentation:

https://github.com/barry-ha/Griduino

The [docs/PROGRAMMING.md](https://github.com/barry-ha/Griduino/blob/master/docs/PROGRAMMING.md) file has complete programming instructions.

Once the Griduino program is installed, the first power-up will probably take 5-30 minutes to acquire GPS satellites. Subsequent usage will lock-up more quickly, since it's assisted by its internal real-time clock that has a coin battery backup.

The Griduino hardware platform offers a great deal of capability with a bright colorful display, powerful cpu, GPS receiver, barometric sensor, and a digital audio channel. We hope you invent fun and useful new things for it to do.

You may find the [examples](https://github.com/barry-ha/Griduino/tree/master/examples) folder interesting and useful. It contains a variety of smaller programs that were used to develop certain concepts and check out features. For example, the barograph display can be a handy desktop application, showing a few days of barometric pressure history.

## 8. Using the Griduino GPS

The [docs/USERS_GUIDE.md](https://github.com/barry-ha/Griduino/blob/master/docs/USERS_GUIDE.md) file has complete information about using and configuring your Griduino.



When you cross a grid line, the new grid is announced in Morse Code on the speaker. Note: The touchscreen may be unresponsive during audio playback.

After loading and running the Griduino program,

* Touch the "menu button" in the upper left to advance from one settings screen to the next.
* Touch the "next view" area in the upper right to advance from one view to the next.
* Touch the bottom third of the screen to adjust brightness.



When you arrive at a destination, you may find it useful to switch to a GMT clock view.



When you're at home in the shack, you may find it interesting to watch the 3-day graphing barometer view.

3-day barometer

## 9. Disclaimer

The information provided is for general education and entertainment. We hope you learn from this and enjoy your hobbies in a safe manner with this new GPS information available at a glance. We take no responsibility for your assembly and construction, nor for how you use this device and information.

**Do not adjust Griduino while driving**. Keep your full attention on the road and the traffic around you. We can not be held responsible for any damage of any sort associated with these projects. You are advised to check your local laws and consult professionals for any project involving electricity, assembly or mounting accessories in your vehicle.

Many areas restrict where and how you are allowed to mount items around your dashboard. You are advised to drive in a safe and legal manner, consistent with all local laws, safety rules and good common sense.

You must accept that you and you alone are responsible for the safety of yourself and others in all aspects of driving with and using a Griduino.

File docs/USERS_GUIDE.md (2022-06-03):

# Griduino User's Guide

This guide applies to Version 1.0 and above.

# 1. Introduction

Griduino logoThank you for purchasing a Griduino GPS navigation kit. Once assembled, this kit is a useful driver's aid dedicated to show your location in the Maidenhead grid square system, your altitude, the exact time in GMT, barometric pressure and more.

This guide contains: 

* <a href ="#Quick_Start_Guide">Quick Start Guide</a> tells you how to read the main grid display. 
* <a href="#Screen_Reference_Guide">Screen Reference Guide</a> provides detail about everything it can display.

If you like to write software, the hardware is a highly capable platform for programming your own features. The Griduino software is open source and it includes several smaller example programs.

# 2. Quick Start Guide



This example image shows a westbound trip on Hwy 20 driving from Eastern Washington State over the Cascade Mountains toward Seattle:

* Large blue rectangle represents your current Maidenhead grid square
* Small blue rectangle represents your current position
* Curved blue line shows your breadcrumb trail to reach your current position
* Grid names are in green
* Grid distances are in yellow
* Bottom row is the latitude and longitude in decimal degrees
* Bottom right is the number of GPS satellites received, e.g.  __7#__
* Bottom right is the height above sea level, e.g.  __204'__

Things you can do:

* Press the **Gear icon** in upper left to advance among the settings screen
* Press the **Arrow icon** in upper right to advance among the information screens
* Press the **bottom row** to change the screen's brightness

When you cross a grid line, the new grid is announced with Morse Code on the speaker.

When you arrive at a destination, you might want to switch to the GMT clock view. This is useful to visually compare to your computer clock for accurate time.

Griduino has non-volatile memory to save its settings, the breadcrumb trail, barometer readings, and more while it is turned off.

Optional connectors:

* Connect headphones or speaker to hear audio. [Here's how.](https://github.com/barry-ha/Griduino/blob/master/docs/ASSEMBLY.md#speaker "Speaker")
* Connect a battery or vehicle power. [Here's how.](https://github.com/barry-ha/Griduino/blob/master/docs/ASSEMBLY.md#power "Power")

# 2. Screen Reference Guide
Griduino will automatically show a few screens in sequence as it powers up. During this time, it does not respond to touches or anything else.

### 2.1 Power-up animation (one time only)
Griduino shows a simple animation while waiting for a serial monitor port. This allows it time to connect to your computer's serial monitor via a USB connection.



### 2.2 Credit screen (one time only)
Griduino will briefly show the author's name and program version number. This is an easy way to know what software is loaded. Later, in the settings screens, it show the version number again along with date it was compiled.



### 2.3 Help screen (one time only)
Griduino shows a brief reminder of the touch-sensitive areas on the main grid display. Although the later screens include small gear and arrow icons, you may note their touch-sensitive areas really cover most of the screen. Accuracy is not required for a busy driver.



# 3. User Screens
After loading and running the Griduino program,  

* Touch the "settings" gear in the upper left to advance from one configuration screen to the next.
* Touch the "next view" arrow in the upper right to advance from one view to the next.
* Touch the bottom third of the screen to adjust brightness. There are three backlight levels.

### 3.1 Grid location view
Griduino has non-volatile storage to save your breadcrumb trail (driving track) from one day to the next. 



### 3.2 Grid details view



### 3.3 GMT clock view



# 4. Configuration Screens
To cycle among the various configuration screens, repeatedly press the "gear" icon.

To return to the main display screens, press the "next screen" arrow in the upper right.

### 4.1 Select audio volume



### 4.2. Select GPS or Demo Mode
To start a demonstration mode, Griduino can simulate travel. Bring up the **Settings 2** view. Change the Route to **Simulator** and return to the main grid view. It follows a pre-programmed route to show the breadcrumb trail and what happens at grid crossings. There are a few different routes available, selectable at compile-time. The most interesting and the default canned route will drive at 900 mph in a big ellipse near the edges of one grid square. 

To cancel the GPS demonstration, reboot Griduino. Or you can return to **Settings 2** and select **GPS Receiver**.



*Delete img/view-settings-img7050.jpg*

### 4.3 Select English or Metric
Although this says "miles" and "kilometers", it actually changes all reported units of all types to English or Metric. That is, the barometric pressure will be shown in "inHg" or "hPa".



### 4.4 Select Audible Announcement Boundaries
You can choose between audible announcements at 4-digit grid boundaries or 6-digit boundaries. Typically:

* 6-meter rovers are interested in distances to the next major grids.
* Microwave rovers often use distance scoring based on 6-digit grid lines and are interested in the next minor boundary. 



When you press one of these buttons, Griduino will play an audible sample of the announcement.

The main grid display continues to show the 4-digit grid. This selection only controls when announcements are made.

### 4.5 Screen Orientation
You can use Griduino in either one of two landscape orientations. This allows you to place its connectors on either side for ease of installing this on your desk or in your vehicle.



# 5. Commands in Terminal Session

In version 1.07 or later, you can open a terminal session to Griduino, such as the Serial Monitor in the Arduino IDE. Type a command and Griduino will respond in this interactive window. 

## help

The **help** command will list all supported commands:

    10:06:08.730 -> help: Available commands are:
    10:06:08.730 -> help, version, dump kml, dump gps, list, start nmea, stop nmea, start gmt, stop gmt

## version

The **version** command will report build information:

    10:06:11.636 -> version: Griduino v1.07
    10:06:11.636 -> Compiled Feb 28 2022 10:04:39
    10:06:11.636 -> Barry K7BWH  John KM7O
    10:06:11.636 -> C:\Users\barry\Documents\Arduino\Griduino\Griduino.ino
    10:06:11.636 -> https://github.com/barry-ha/Griduino

## dump kml

**dump kml** command will list all the recorded GPS readings in text that is compatible with KML (keyhole markup language) for Google Earth and other mapping programs. This is intended for the Griduino Desktop program; to use it independently you can copy/paste this into a text file. For example:

    10:13:19.195 -> dump kml: <?xml version="1.0" encoding="UTF-8"?>
    10:13:19.195 -> <kml xmlns="http://www.opengis.net/kml/2.2" xmlns:gx="http://www.google.com/kml/ext/2.2" xmlns:kml="http://www.opengis.net/kml/2.2" xmlns:atom="http://www.w3.org/2005/Atom">
    10:13:19.195 -> <Document>
    10:13:19.195 -> 	<name>Griduino Track</name>
    10:13:19.195 -> 	<Style id="gstyle">
    10:13:19.195 -> 		<LineStyle>
    10:13:19.195 -> 			<color>ffffff00</color>
    10:13:19.195 -> 			<width>4</width>
    10:13:19.195 -> 		</LineStyle>
    10:13:19.195 -> 	</Style>
    10:13:19.195 -> 	<StyleMap id="gstyle0">
    10:13:19.195 -> 		<Pair>
    10:13:19.195 -> 			<key>normal</key>
    10:13:19.195 -> 			<styleUrl>#gstyle1</styleUrl>
    10:13:19.195 -> 		</Pair>
    10:13:19.195 -> 		<Pair>
    10:13:19.195 -> 			<key>highlight</key>
    10:13:19.195 -> 			<styleUrl>#gstyle</styleUrl>
    10:13:19.195 -> 		</Pair>
    10:13:19.195 -> 	</StyleMap>
    10:13:19.195 -> 	<Style id="gstyle1">
    10:13:19.195 -> 		<LineStyle>
    10:13:19.195 -> 			<color>ffffff00</color>
    10:13:19.195 -> 			<width>4</width>
    10:13:19.195 -> 		</LineStyle>
    10:13:19.195 -> 	</Style>
    10:13:19.195 -> 	<Placemark>
    10:13:19.195 -> 		<name>Griduino Track</name>
    10:13:19.195 -> 		<styleUrl>#gstyle0</styleUrl>
    10:13:19.195 -> 		<LineString>
    10:13:19.195 -> 			<tessellate>1</tessellate>
    10:13:19.195 -> 			<coordinates>
    10:13:19.195 -> -122.2844,47.7530,0 
    10:13:19.195 -> 			</coordinates>
    10:13:19.195 -> 		</LineString>
    10:13:19.195 -> 	</Placemark>
    10:13:19.195 -> 	<Placemark>
    10:13:19.195 -> 		<name>Start 02/28/22</name>
    10:13:19.195 -> 		<styleUrl>#m_ylw-pushpin0</styleUrl>
    10:13:19.195 -> 		<Point>
    10:13:19.195 -> 			<gx:drawOrder>1</gx:drawOrder>
    10:13:19.195 -> 			<coordinates>-122.2844,47.7530,0</coordinates>
    10:13:19.195 -> 		</Point>
    10:13:19.195 -> 	</Placemark>
    10:13:19.195 -> </Document>
    10:13:19.195 -> </kml>

## start nmea

The **start nmea** and  **stop nmea** commands will echo raw NMEA sentences to the console. This is intended for the Griduino Desktop program. For example:

    10:17:33.996 -> start nmea: started
    10:17:34.463 -> $GPRMC,181734.000,A,4745.1831,N,12217.0822,W,0.28,31.44,280222,,,A*42
    10:17:35.397 -> $GPRMC,181735.000,A,4745.1831,N,12217.0822,W,0.43,340.55,280222,,,A*7B
    10:17:36.510 -> $GPRMC,181736.000,A,4745.1832,N,12217.0823,W,0.14,298.75,280222,,,A*7E
    10:17:37.491 -> $GPRMC,181737.000,A,4745.1833,N,12217.0823,W,0.47,81.89,280222,,,A*41
    10:17:38.465 -> $GPRMC,181738.000,A,4745.1833,N,12217.0821,W,0.36,93.99,280222,,,A*48

## start gmt

The **start gmt** and **stop gmt** commands will echo the Griduino RTC (real time clock) to the console. It's pretty busy; the console will receive updates every clock tick on the second. This is intended for the Griduino Desktop program. For example:

    10:18:59.871 -> start gmt: started
    10:19:00.271 -> 2022-02-28 18:18:59+00:00
    10:19:01.250 -> 2022-02-28 18:19:00+00:00
    10:19:02.276 -> 2022-02-28 18:19:01+00:00
    10:19:03.272 -> 2022-02-28 18:19:02+00:00

## list

The **list** command will report SDRAM usage. This is mainly for debugging file problems, such as when the 2 MB file system is nearly full:

    10:06:12.937 -> list: 
    10:06:12.937 -> Directory of Griduino
    10:06:12.937 ->          100 screen.cfg
    10:06:12.937 ->          100 volume.cfg
    10:06:12.937 ->           97 announce.cfg
    10:06:12.937 ->         6240 barometr.dat
    10:06:12.937 ->        19416 gpsmodel.cfg
    10:06:12.937 ->         1240 ten_mile.cfg
    10:06:12.937 ->          100 barogrph.cfg
    10:06:12.937 ->            7 Files, 27293 bytes
    10:06:12.937 -> 
    10:06:12.937 -> Directory of audio
    10:06:12.937 ->        34916 _LICENSE.md
    10:06:12.937 ->         1542 _README.md
    10:06:12.937 ->        20552 0.wav
    10:06:12.937 ->        15860 1.wav
    10:06:12.937 ->        15874 2.wav
    (snip)
    10:06:12.937 ->        24140 x.wav
    10:06:12.937 ->        22964 y.wav
    10:06:12.937 ->        22732 z.wav
    10:06:12.937 ->           38 Files, 804870 bytes

# 6. Programming the Griduino GPS

You can find, download and install the latest Griduino program using the latest documentation on GitHub: 

https://github.com/barry-ha/Griduino

For hobbyists interested in a deep dive, [docs/PROGRAMMING.md](https://github.com/barry-ha/Griduino/blob/master/docs/PROGRAMMING.md) has complete Arduino IDE setup and programming instructions. 

# 7. Files Saved in RAM

Griduino uses the 2 MB Quad SPI RAM chip built onto the Feather M4 board to save its configuration settings (such as audio volume and distance units) and its data logging files (such as GPS track and barometer history).

**View:** There are a few ways to view the Griduino's RAM file system.

1. Run the Griduino main program and, using the serial monitor, type "list" and press Enter.
1. Run CircuitPython and use Windows file system to examine external drive named ``CIRCUITPY``
1. Run our example program: ``Flash_file_directory_list``

Our example program shows a few files on the display and sends the complete file listing to the serial monitor. It will re-send the listing periodically. A typical output from this program (May 2022) is:

	Listing files in the root directory:
	1. System Volume Information  (dir)
		 IndexerVolumeGuid  76
		 WPSettings.dat     12
	2. .fseventsd      (dir)
	3. code.py         22
	4. boot_out.txt    117
	5. data.txt        70
	6. Griduino        (dir)
		 screen.cfg      100
		 volume.cfg      100
		 announce.cfg    97
		 barometr.dat    6240
		 ten_mile.cfg    1240
		 altimetr.cfg    100
		 gpsmodel.cfg    38632
	7. main.py         0
	8. audio           (dir)
		 _LICENSE.md     34916
		 _README.md      1542
		 0.wav           20552
		 1.wav           15860
		 2.wav           15874
		 3.wav           16108
	     ...

**Modify:** To edit or delete file in the 2 MB Quad SPI RAM chip, run CircuitPython and use your Windows file system to manage the files on the external drive named ``CIRCUITPY``.

# 8. Support

Please browse our public group forum at [groups.io/g/Griduino/](https://groups.io/g/Griduino/)

Join our group to hear about upgrades, new software, ask questions, share your experience and suggest features.

# 9. Disclaimer

The information provided is for general education and entertainment. We hope you learn from this and enjoy your hobbies in a safe manner with all this new and interesting GPS information available at a glance. We take no responsibility for your assembly and construction, nor for how you use these devices. 

**Do not adjust Griduino while driving**. Keep your full attention on the road and the traffic around you. We can not be held responsible for any property or medical damages caused by these projects. You are advised to consult professionals for any project involving electricity, construction or assembly. You are advised to check local regulation for allowable methods of mounting and using dashboard devices. You are advised to drive in a safe and legal manner, consistent with all local laws, safety rules and good common sense.

You must accept that you and you alone are responsible for your safety and safety of others in all aspects of working with Griduino.


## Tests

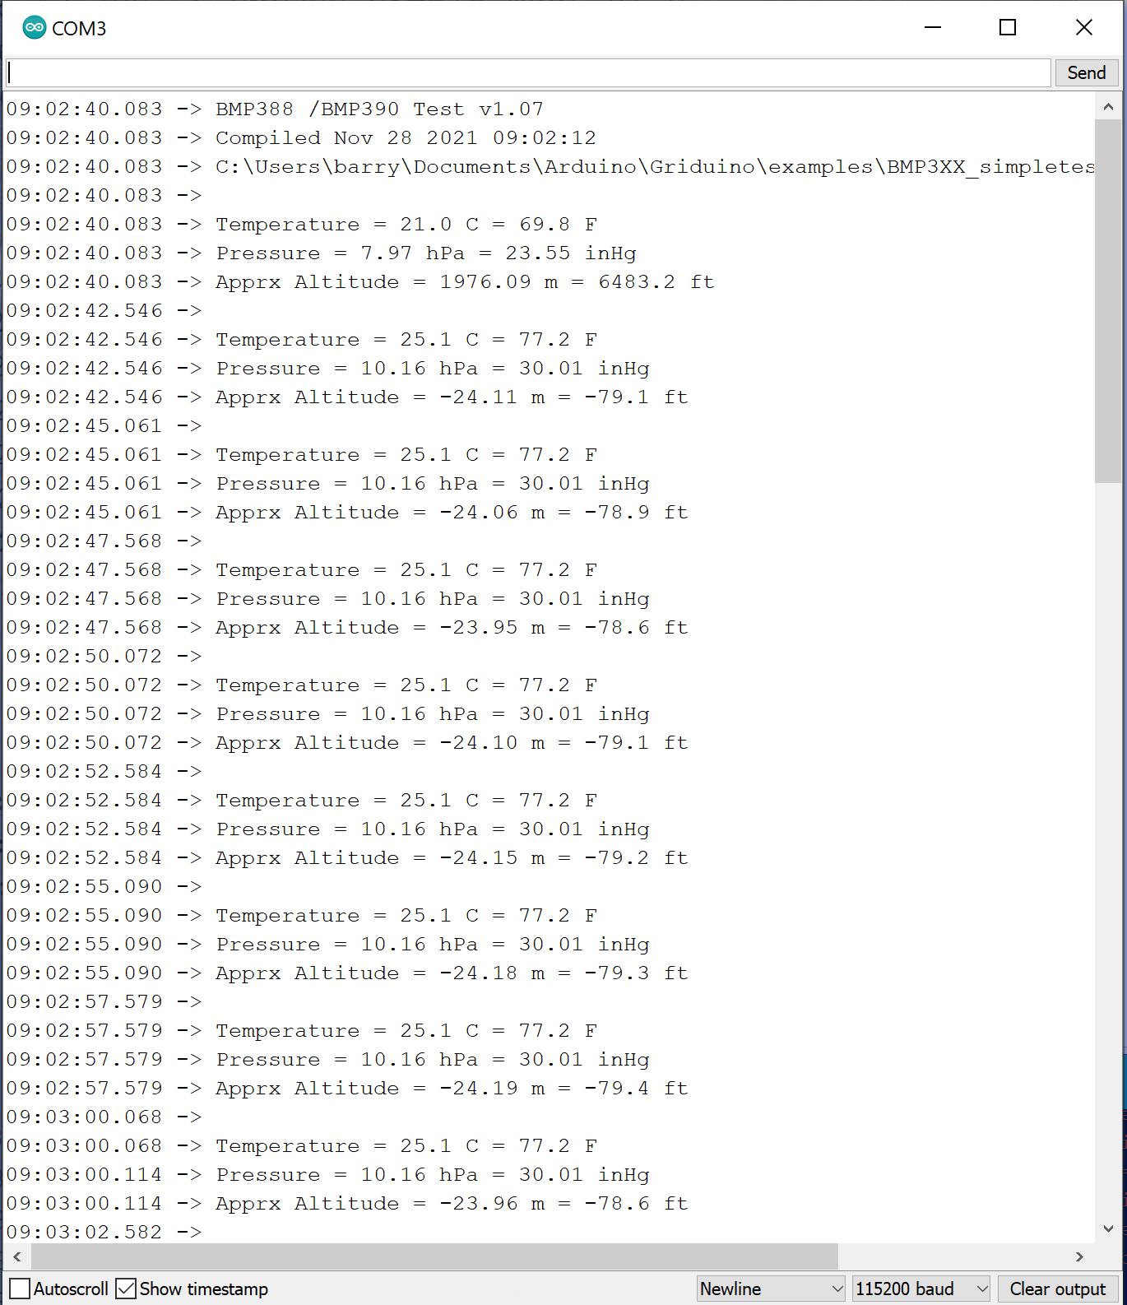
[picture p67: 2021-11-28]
examples/BMP3XX_simpletest/2021-11-28 BMP388 Simple Test img6245.JPG

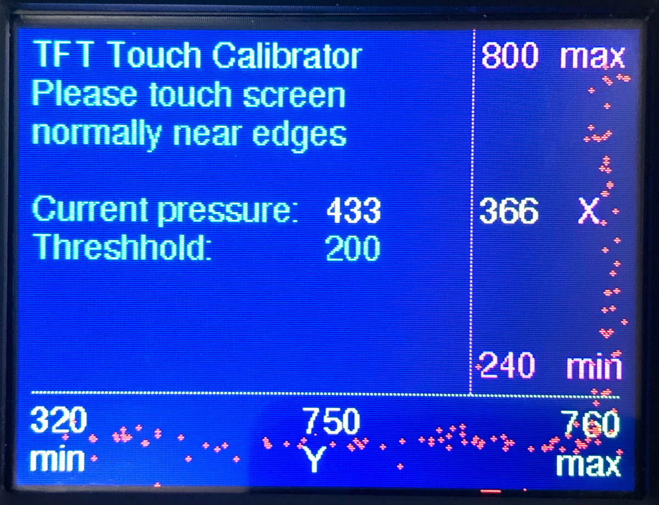
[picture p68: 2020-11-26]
examples/TFT_Touch_Calibrator/TFT-Touch-Calibrator-img7609.jpg

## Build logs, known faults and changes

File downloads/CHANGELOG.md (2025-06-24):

# Changelog

To install a firmware update, see the [Programming](https://github.com/barry-ha/Griduino/blob/master/docs/PROGRAMMING.md#2-how-to-install-the-griduino-program) instructions.

All notable changes to this project are documented in this file.

Version numbers correspond to [Downloads](https://github.com/barry-ha/Griduino/tree/master/downloads) available as pre-compiled binary Griduino programs.

The changelog format is based on [Keep a Changelog](https://keepachangelog.com/en/1.0.0/), and the Griduino project uses [Semantic Versioning](https://semver.org/spec/v2.0.0.html).

## v1.15 beta &nbsp; 2025-06-22

Version 1.15 is a beta release to consolidate enhancements since the last stable release of v1.10 on 2022-08-05. Read the changelog features below to find more new features.

New: an additional main grid display shows vehicle speed and a large bright pointer of direction. The breadcrumb trail will paint over the status while you drive. The large 6-digit grid letters are smaller to make room for the compass. The compass is derived from GPS readings; when you're stopped at 0 mph, you can expect the compass to wander around.

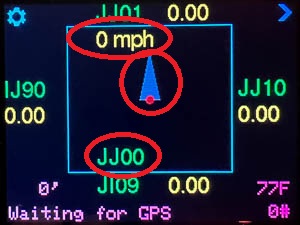
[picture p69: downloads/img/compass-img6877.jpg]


New: Griduino runs correctly on both PCB v4 and the latest PCB v14 hardware 

New: Configurator screens are resequenced to put the most commonly used options first.

New: GPS Simulator rewritten and now generates speed for the compass+speedometer display. Note it will show 2,000-3,000 mph which is the real ground speed required to traverse the big oval track that it generates.

New: example/TFT_Triangle_Demo.ino sketch shows the simplest possible "speed+compass" for performance testing 

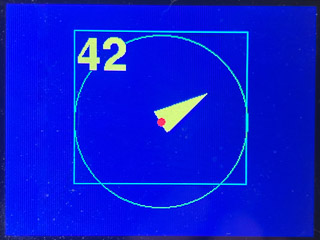
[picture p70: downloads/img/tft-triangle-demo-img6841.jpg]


New: auto detect barometric sensor SPI or I2C hardware

Fixed: coin battery voltage is only shown on PCB hardware that has a voltage sensor (PCB v12 and later)

Issue: no spoken word audio

Issue: barometric pressure "Baroduino" screen will plot three days of air pressure readings in real time but it does not save history when turned off

## v1.14.4 alpha &nbsp; 2024-12-20

Version 1.14.4 is an Alpha release, bringing enhancements and fixes over the last twelve months that were made while preparing new hardware.

New: "Reformat Flash Memory" screen can recover from corrupted flash memory situations

New: major new general-purpose debug logging system is configurable by subsystem and severity

New: Coin Battery measurement, bar graph, low battery warning, and logging (new hardware only)

New: moved Help screen into main loop, now it's just another view of many views

New: "dir" command, synonymous with "list files"

New: added example NeoPixel program, the simplest possible thing that can work

## v1.13.2 beta &nbsp; 2024-01-04

Version 1.13.2 is a Beta release.

Fixed: Laggard "one second" screen refresh which occurred only every 47 seconds.

Fixed: Satellite reception bar graph in inverted mode; history increased to ten minutes.

Removed: Speech announcements temporarily disabled until a lockup condition is fixed.

## v1.13 alpha &nbsp; 2023-11-30

Version 1.13 is an Alpha release. This is a snapshot of current development as we freeze the RPi 2040 development. Now that Adafruit has started shipping the Feather M4 Express again, we shelved the rp2040 PCB project.

New: Added a bar graph history of satellite reception for the last 8 minutes.

Fixed: Task scheduling is more reliable, although a lockup condition is still possible after several days of continuous operation.

## v1.12 beta &nbsp; 2023-05-17

Version 1.12 is a Beta release containing significant changes. Please report any problems, thank you.

New: If GPS satellite signal is lost, make an audible announcement every 5 minutes. This is often enough to tell the driver without distracting them too much.

New: Re-wrote entire breadcrumb trail and 'dump kml' function.

New: Internal history now keeps track of more information: speed, direction, altitude, and number of satellites. All these are available in 'dump kml' and can be displayed in Google Earth and other KML-compatible programs.

New: Breadcrumb trail now records are "power up" and "first valid time from GPS receiver". This will help diagnose situations where GPS reception is spotty.

New: Automatically records GPS position every 10 minutes to keep track of being parked in one spot for awhile.

New: Animated logo on opening screen.

New: Support for a new microprocessor: RP2040. Since the Adafruit Feather M4 is no longer obtainable, we've put considerable effort over the last six months for the replacement CPU and a new PCB. On eventual release, we can recompile this source code for either processor.

Fixed: The main display screen no longer bogs down when the breadcrumb trail has more than 1,500 items. This would also cause slow GPS sync and loss of GPS signal because it failed to poll the GPS chip often enough.

## v1.10 &nbsp; 2022-08-05

New: Supports the "GPS Status" panel of NMEATime2, showing the satellite signal strength and sky location of GPS satellites.

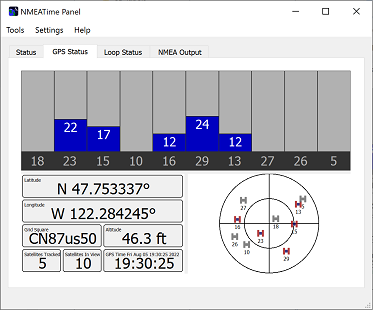
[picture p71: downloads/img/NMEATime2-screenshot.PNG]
screen showing NMEATime2 Title


## v1.09 beta &nbsp; 2022-06-21

Fixed: Hang on Hint screen (If this has any problems, please run v1.06 instead.)

New: Doubled the size of the GPS bread crumb trail. It'll retain about 1,500 miles of GPS history before overwriting the oldest spot in its circular buffer.

New: Griduino can automatically and continually update your computer's time of day. It requires you to install NMEATime2, available from www.visualgps.com and is free for 30 days then purchased for about $20. Please try it out and send me comments about this beta test.

## v1.08 &nbsp; 2022-06-07

Not Quite Fixed: A rare condition in some Griduinos running v1.07 causes it to hang on the startup Hint screen. This doesn't happen often, but if starts then it will always hang during boot. The problem tends to occur after driving for some distance, perhaps about a hundred miles.

Version 1.08 is not recommended for any users.

## v1.07 &nbsp; 2022-02-28

New: Added terminal session commands. Now you can open a terminal session to Griduino, such as the Serial Monitor in the Arduino IDE. Type a command and Griduino will respond. 

**help** - list all supported commands:

    10:06:08.730 -> help: Available commands are:
    10:06:08.730 -> help, version, dump kml, dump gps, list, start nmea, stop nmea, start gmt, stop gmt

**version** - report build information:

    10:06:11.636 -> version: Griduino v1.07
    10:06:11.636 -> Compiled Feb 28 2022 10:04:39
    10:06:11.636 -> Barry K7BWH  John KM7O
    10:06:11.636 -> C:\Users\barry\Documents\Arduino\Griduino\Griduino.ino
    10:06:11.636 -> https://github.com/barry-ha/Griduino

**dump kml** - list all the recorded GPS readings in text that is compatible with KML (keyhole markup language) for Google Earth and other mapping programs. This is intended for the Griduino Desktop program; to use it independently you can copy/paste this into a text file. For example:

    10:13:19.195 -> dump kml: <?xml version="1.0" encoding="UTF-8"?>
    10:13:19.195 -> <kml xmlns="http://www.opengis.net/kml/2.2" xmlns:gx="http://www.google.com/kml/ext/2.2" xmlns:kml="http://www.opengis.net/kml/2.2" xmlns:atom="http://www.w3.org/2005/Atom">
    10:13:19.195 -> <Document>
    10:13:19.195 -> 	<name>Griduino Track</name>
    10:13:19.195 -> 	<Style id="gstyle">
    10:13:19.195 -> 		<LineStyle>
    10:13:19.195 -> 			<color>ffffff00</color>
    10:13:19.195 -> 			<width>4</width>
    10:13:19.195 -> 		</LineStyle>
    10:13:19.195 -> 	</Style>
    10:13:19.195 -> 	<StyleMap id="gstyle0">
    10:13:19.195 -> 		<Pair>
    10:13:19.195 -> 			<key>normal</key>
    10:13:19.195 -> 			<styleUrl>#gstyle1</styleUrl>
    10:13:19.195 -> 		</Pair>
    10:13:19.195 -> 		<Pair>
    10:13:19.195 -> 			<key>highlight</key>
    10:13:19.195 -> 			<styleUrl>#gstyle</styleUrl>
    10:13:19.195 -> 		</Pair>
    10:13:19.195 -> 	</StyleMap>
    10:13:19.195 -> 	<Style id="gstyle1">
    10:13:19.195 -> 		<LineStyle>
    10:13:19.195 -> 			<color>ffffff00</color>
    10:13:19.195 -> 			<width>4</width>
    10:13:19.195 -> 		</LineStyle>
    10:13:19.195 -> 	</Style>
    10:13:19.195 -> 	<Placemark>
    10:13:19.195 -> 		<name>Griduino Track</name>
    10:13:19.195 -> 		<styleUrl>#gstyle0</styleUrl>
    10:13:19.195 -> 		<LineString>
    10:13:19.195 -> 			<tessellate>1</tessellate>
    10:13:19.195 -> 			<coordinates>
    10:13:19.195 -> -122.2844,47.7530,0 
    10:13:19.195 -> 			</coordinates>
    10:13:19.195 -> 		</LineString>
    10:13:19.195 -> 	</Placemark>
    10:13:19.195 -> 	<Placemark>
    10:13:19.195 -> 		<name>Start 02/28/22</name>
    10:13:19.195 -> 		<styleUrl>#m_ylw-pushpin0</styleUrl>
    10:13:19.195 -> 		<Point>
    10:13:19.195 -> 			<gx:drawOrder>1</gx:drawOrder>
    10:13:19.195 -> 			<coordinates>-122.2844,47.7530,0</coordinates>
    10:13:19.195 -> 		</Point>
    10:13:19.195 -> 	</Placemark>
    10:13:19.195 -> </Document>
    10:13:19.195 -> </kml>

**start nmea** and  **stop nmea** - echo raw NMEA sentences to the console. This is intended for the Griduino Desktop program and for NMEATime2 by www.visualgps.com. For example:

    10:17:33.996 -> start nmea: started
    10:17:34.463 -> $GPRMC,181734.000,A,4745.1831,N,12217.0822,W,0.28,31.44,280222,,,A*42
    10:17:35.397 -> $GPRMC,181735.000,A,4745.1831,N,12217.0822,W,0.43,340.55,280222,,,A*7B
    10:17:36.510 -> $GPRMC,181736.000,A,4745.1832,N,12217.0823,W,0.14,298.75,280222,,,A*7E
    10:17:37.491 -> $GPRMC,181737.000,A,4745.1833,N,12217.0823,W,0.47,81.89,280222,,,A*41
    10:17:38.465 -> $GPRMC,181738.000,A,4745.1833,N,12217.0821,W,0.36,93.99,280222,,,A*48

**start gmt** and **stop gmt** - echo the Griduino RTC (real time clock) to the console. This is intended for the Griduino Desktop program. For example:

    10:18:59.871 -> start gmt: started
    10:19:00.271 -> 2022-02-28 18:18:59+00:00
    10:19:01.250 -> 2022-02-28 18:19:00+00:00
    10:19:02.276 -> 2022-02-28 18:19:01+00:00
    10:19:03.272 -> 2022-02-28 18:19:02+00:00

**list** - report SDRAM usage. This is mainly for debugging file problems, such as when the 2 MB file system is nearly full:

    10:06:12.937 -> list: 
    10:06:12.937 -> Directory of Griduino
    10:06:12.937 ->          100 screen.cfg
    10:06:12.937 ->          100 volume.cfg
    10:06:12.937 ->           97 announce.cfg
    10:06:12.937 ->         6240 barometr.dat
    10:06:12.937 ->          280 gpsmodel.cfg
    10:06:12.937 ->         1421 gpshistory.csv
    10:06:12.937 ->         1240 ten_mile.cfg
    10:06:12.937 ->          100 barogrph.cfg
    10:06:12.937 ->            7 Files, 27293 bytes
    10:06:12.937 -> 
    10:06:12.937 -> Directory of audio
    10:06:12.937 ->        34916 _LICENSE.md
    10:06:12.937 ->         1542 _README.md
    10:06:12.937 ->        20552 0.wav
    10:06:12.937 ->        15860 1.wav
    10:06:12.937 ->        15874 2.wav
    (snip)
    10:06:12.937 ->        24140 x.wav
    10:06:12.937 ->        22964 y.wav
    10:06:12.937 ->        22732 z.wav
    10:06:12.937 ->           38 Files, 804870 bytes

**Scottish Voice** &nbsp; 2020-02-22

New: Added Scottish female voice speaking NATO alphabet for grid-crossing.

You can install this by over-writing restarting Griduino in "Circuit Python" mode, so that it will become an external USB-attached file system. In this mode you can drag-n-drop the "audio" folder and overwrite the previous "audio" folder with the new voice files. Read the complete instructions in the **doc** folder section **3. Install Audio Files**.

## v1.06 &nbsp; 2021-10-11

New: Added the "internal case temperature" to the main screen display in the lower right corner, right above the number-of-satellites-received indicator. This will help people in hot climates recognize if Griduino running too hot (above 150F).

New: Opening animation shows colorful starbursts instead of the green time tunnel, just for fun.

## v1.05 &nbsp; 2021-08-07

Fix: The "set" button on the Ten Mile Alert screen did not always save the location.

New: The Ten-Mile Alert screen is slightly changed to highlight "Here" and improve visual focus.

## v1.04 &nbsp; 2021-07-21

New: Ten Mile Alert screen for microwave rovers. This lets you set a pushpin at your current location and then report straight-line distance and direction while you drive around. It's designed for ARRL microwave contests that require moving at least ten miles (16 km) before contacting the same station again.

Fix: Now it will remember your local timezone through a power cycle.

## v1.03 &nbsp; 2021-07-10

Fixed the visual layout when the screen is rotated. This affected the Altimeter display and the Countdown to Date screens which were badly mangled.

## v1.02 &nbsp; 2021-06-24

New: The "count-down to date" view can cycle among five different events: ARRL June VHF Contest, Groundhogs Day, Christmas, Halloween, and Valentine's Day. Look for a "More" button on the right edge of the screen. This was a major revision to view_date.h module.

## v1.01 &nbsp; 2021-04-26

New: Replaced the status screen with new "Grid Size and Scale" information.

This gives the user a sense of scale looking at our main screen map. It helps understand the bread crumb trail and how far to go within a 4-digit and 6-digit grid squares. The previous status screen was one of the first screens built and became redundant with other screens.

## v1.0 &nbsp; 2021-04-17

Griduino has all major features completed, so the version number jumps to **v1.0**. We like the [semantic versioning](https://semver.org/) scheme so we'll manage our version numbers accordingly. However, since Griduino doesn't have an API, our scheme is  modified to only use two numbers.

Given a version number `MAJOR.MINOR`, we will increment the:

   * `MAJOR` version when adding major features or hardware changes, and
   * `MINOR` version for fixing bugs or for small incremental changes.

## v0.37 &nbsp; 2021-04-12

Added speech audio output as an alternative to Morse code. This is a major upgrade.

Griduino can now speak grid square names. This feature requires:

   1. Install audio recordings of the letters and numbers. These WAV files are copied onto the Feather separately using a different process than the binary program file. See https://github.com/barry-ha/Griduino/blob/master/docs/PROGRAMMING.md#3-install-audio-files
   1. Install the latest Griduino program, v0.37 or later
   1. Press the "gear" icon until you see the **Audio Type** screen.<br/>Select **Spoken Word**.<br/>It should immediately announce your grid square.<br/>If it beeps, then Griduino did not find the audio files.

## v0.36 &nbsp; Skipped

This was an internal testing version. The pre-compiled binary was not released.

## v0.35 &nbsp; 2021-02-25

Fixed several bugs in the Altimeter view. Added a small 'sync' button on right-hand side which calibrates the sea level pressure so that the two reported altitudes match each other. The GPS is not always right but it's pretty close and the 'sync' button will make large adjustments easy.

Also fixed the three-day graph of barometric pressure. It had been graphing only two days and now it will show up to three full days.

Get this download and try it out! Recommended for all users.

## v0.34 &nbsp; 2021-02-11

Improved the Altimeter view usability. This is a work in progress.

## v0.33 &nbsp; 2021-02-09

Added Altimeter view which compares altitude from the barometer to altitude from the GPS. This is an interesting way to cross-check and decide for yourself the accuracy of reports.

The problem is that both of them can be off:

* An accurate reading from the barometer depends on knowing your current pressure at sea level at your location. The altimeter screen therefore offers + and - buttons to calibrate it. You can get the correct pressure by searching the web for a local weather report, or by adjusting it to a known altitude.
* An accurate reading from the GPS depends on the number and position of satellites overhead. You would need a good satellite right overhead for best results. Further, signal reflections from nearby objects can throw it off. Unfortunately the consumer GPS service was designed to be more accurate positionally than for altitude. For example, at my home, the GPS reports can vary day-by-day by 300 feet or so.

## v0.32 &nbsp; 2021-02-03

Added 3-day graph of barometric pressure, a "Baroduino" if you'll excuse the amalgam. Please report any bugs or usability glitches.

This is a major update that merges code from [examples/Baroduino](https://github.com/barry-ha/Griduino/tree/master/examples/Baroduino) into the main Griduino program which becomes an additional view in the screens as you cycle through views. The standalone example program is no longer needed. We also fixed a few bugs and changed titles of the configuration screens to be more descriptive, such as "1. Speaker" instead of "Settings 1".

## v0.31 &nbsp; 2021-01-30

Updated the pressure sensor code to use the latest BMP3XX library. Please update to the v2 library from Adafruit or you’ll get a compile error:
1 Run the Arduino workbench
1 Tools > Manage Libraries … > Type: Updatable
1 Find “Adafruit BMP3XX Library” in the list and update to the latest version
1 It’s okay to get all the latest library dependencies, too. The list has been updated and tested for v0.31.

When we started the Griduino project in early 2020, Adafruit offered only one barometric sensor: BMP388. In October 2020, Bosch introduced a more sensitive device, BMP390, and Adafruit followed suit to sell it on a pin-compatible breakout board. However, it’s not quite software-compatible. I bought and tested the new BMP390 to make sure it works successfully and today I checked in the code changes. Griduino software will now work with either barometric sensor and is a little more future-proof.

## v0.30 &nbsp; 2020-12-19

Fixed the background color of the activity indicator on the bottom line. The code change was to extend the base class in view.h so that every screen is allowed to have its own background color independent of other screens.

## v0.29 &nbsp; 2020-11-26

Created new example program to study TFT Resistive Touchscreen behavior and calibration. See [examples/TFT Touch Calibrator](https://github.com/barry-ha/Griduino/tree/master/examples/TFT_Touch_Calibrator). The idea is to display the touchscreen configuration values along with values actually measured when you actually touch it. The screen feedback shows how where each touch is mapped into screen coordinates. There is a certain amount of manufacturing variability and it's possible that my values don't suite your own device. If your particular touchscreen looks too far off, it reports the measured values which you can use to edit your source code and compile/run again.

## v0.28 &nbsp; 2020-11-12

In the graphing barometer, added "number of satellites" and today's date. Also added debug output for the serial-attached console to help track down if the RTC hangs up.

## v0.27 &nbsp; 2020-11-03

Added new feature to select how often grid-crossing announcements are made. You can choose either 4-digit grid lines (about 70 miles N-S and 100 miles E-W) or 6-digit grid lines (about 3 miles N-S and 4 miles E-W). The setting is implemented as a new 'view' in cfg_setting4.h and is retained in non-volatile RAM.

##  v0.26 &nbsp; 2020-10-29

Added data logger for barometric pressure into the main Griduino program. Now it collects the weather history in the background while doing everything else.  Then, to display the pressure graph, download baroduino_v026.uf2.

## v0.25 &nbsp; 2020-10-03

Improved timing to make the GMT clock more closely match WWV.

Before this change, it typically displayed 'xx:59' seconds as the tone is heard.  But sometimes the 'xx:58' is displayed, and sometimes it skips the 'xx:59'  display and goes directly to the :00 seconds exactly on the 1 second 'tick'.

## v0.24 &nbsp; 2020-10-02

Added new view for a frivolous "Groundhog Day" counter display. We feel like we're stuck in a time loop, just like Bill Murray in his 1993 movie. Now we know how long we've been in the pandemic and self-imposed social distancing.

Also vastly updated the standalone "Baroduino" example program.

## v0.23 &nbsp; 2020-09-02

Refactored views into base class "View" and derived classes. No visible change to usage and operation.

## v0.22 &nbsp; 2020-08-23

Added setting to show distance in miles/kilometers

## v0.21 &nbsp; 2020-08-20

Fixed audio volume set-save-restore bug

## v0.20 &nbsp; 2020-08-14

Added icons for gear, arrow

## v0.18 &nbsp; 2020-07-06

Added runtime selection of GPS receiver vs simulated trail

## v0.17 &nbsp; 2020-06-23

Added Settings control panel, and clear breadcrumb trail

## v0.16 &nbsp; 2020-06-03

Added GMT Clock view

## v0.15 &nbsp; 2020-05-30

Added simulated GPS track (class MockModel)

## v0.13 &nbsp; 2020-05-12

Implemented our own TouchScreen functions

## v0.12 &nbsp; 2020-05-09

Refactored screen writing to class TextField

## v0.11] &nbsp; 2020-05-21

Added GPS save/restore to visually power up in the same place as previous spot

## v0.10 &nbsp; 2020-04-19

Added altimeter example program

## v09.8 &nbsp; 2020-02-18  

Added saving settings in 2MB RAM

## v09.4 &nbsp; 2020-02-18

Added a new view for controlling audio volume

## v09.3 &nbsp; 2020-01-01  

Made the Morse Code actually work, and replaces view-stat-screen

## v09.2 &nbsp; 2019-12-30  

Added Morse Code announcements via generated audio waveform on DAC.

## v09.0 &nbsp; 2019-12-20  

Generates sound by synthesized sine wave intended for decent fidelity from a small speaker. The hardware goal is to support spoken-word output.

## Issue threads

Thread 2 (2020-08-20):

Feature request: audible 6-digit grid lines

barry-ha, 2020-08-20:
Rod WE7X: Some contests are scored by distance as measured by 6-digit grid coordinates, not just 4-digit grid squares. For example, microwave contests are distance-scored. At mid latitudes, grid6 lines occur every 3-4 miles. It would help keep a driver's eyes on the road to get an audio annunciation instead of frequently checking the display.

barry-ha, 2021-01-31:
This feature was added in v0.27 on Nov 3, 2020. The audible announcement can be configured on the "Settings 4" screen.
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

Closed 2021-01-31.

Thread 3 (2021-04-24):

Power Polarity

Winger5555, 2021-04-24:
I assume that the power to the unit is positive center pin and the negative pin is to the outer shield?

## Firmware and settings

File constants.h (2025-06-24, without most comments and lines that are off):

#pragma once   // Please format this file with clang before check-in to GitHub
#define PROGRAM_TITLE "Griduino"
#if defined(ARDUINO_ADAFRUIT_FEATHER_RP2040)
#define PROGRAM_VERSION "v1.14"
#else
#define PROGRAM_VERSION "v1.15"
#endif
#define HARDWARE_VERSION "Rev 4"   // Rev 4 | Rev 7 | Rev 12 | Rev 14
#define PROGRAM_LINE1    "Barry K7BWH"
#define PROGRAM_LINE2    "John KM7O"
#define PROGRAM_VERDATE  PROGRAM_VERSION ", compiled " __DATE__
#define PROGRAM_COMPILED __DATE__ " " __TIME__
#define PROGRAM_FILE     __FILE__
#define PROGRAM_GITHUB   "https://github.com/barry-ha/Griduino"
#define gScreenWidth  320   // screen pixels wide
#define gScreenHeight 240   // screen pixels high
#define gBoxWidth  180   // grid square width as shown on display, pixels
#define gBoxHeight 160   // grid square height as shown on display, pixels
#define gMarginX   70    // define space for grid outline on screen
#define gMarginY   26    // and position text relative to this outline
const float gridWidthDegrees  = 2.0;   // horiz E-W size of one grid square, degrees
const float gridHeightDegrees = 1.0;   // vert N-S size of one grid square, degrees
const double minLong = gridWidthDegrees / gBoxWidth;     // longitude degrees from one pixel to the next (minimum visible movement)
const double minLat  = gridHeightDegrees / gBoxHeight;   // latitude degrees from one pixel to the next
#define feetPerMeters         (3.28084)    // altitude conversion
#define mphPerKnots           (1.15078)    // speed conversion
#define mphPerMetersPerSecond (0.44704)    // speed conversion
#define knotsPerKph           (0.539957)   // speed conversion
#define milesPerKm            (0.621371)   // speed conversion
#define degreesPerRadian (57.2957795)   // (360 degrees)/(2 pi radians)
#define radiansPerDegree (0.01745329)   // (2 pi radians)/(360 degrees)
#define earthRadiusMiles (3958.8)   // average Earth radius (miles)
#define earthRadiusKM    (6371.0)   // average Earth radius (kilometers)
#define SECS_PER_1MIN  ((time_t)(60UL))
#define SECS_PER_5MIN  ((time_t)(300UL))
#define SECS_PER_10MIN ((time_t)(600UL))
#define SECS_PER_15MIN ((time_t)(900UL))
#define SECS_PER_HOUR  ((time_t)(3600UL))
#define DEFAULT_SEALEVEL_PASCALS (101740.0)
#define DEFAULT_SEALEVEL_HPA     (1017.40)
#define FIRST_RELEASE_YEAR  (2019)   // this date can help filter out bogus GPS timestamps
#define FIRST_RELEASE_MONTH (12)
#define FIRST_RELEASE_DAY   (19)
#define CONFIG_FOLDER "/Griduino"
enum Rotation {
  PORTRAIT          = 0,   //   0 degrees = portrait
  LANDSCAPE         = 1,   //  90 degrees = landscape
  FLIPPED_PORTRAIT  = 2,   // 180 degrees = portrait flipped 180-degrees
  FLIPPED_LANDSCAPE = 3,   // 270 degrees = landscape flipped 180-degrees
};
enum {
  eGPSRECEIVER = 1,   // use the GPS receiver hardware
  eGPSSIMULATOR,      // use a GPS simulator
};
enum {
  eFONTGIANT    = 36,
  eFONTBIG      = 24,
  eFONTSMALL    = 12,
  eFONTSMALLEST = 9,
  eFONTSYSTEM   = 0,
  eFONTUNSPEC   = -1,
};
const int MAXBRIGHT = 255;   // = 100% brightness = maximum allowed on individual LED
const int BRIGHT    = 32;    // = tolerably bright indoors
const int HALFBR    = 20;    // = half of tolerably bright
const int OFF       = 0;     // = turned off
const float GOOD_BATTERY_MINIMUM    = (2.25);   // green, if above this voltage
const float WARNING_BATTERY_MINIMUM = (2.10);   // yellow, if above this voltage
const float BAD_BATTERY_MAXIMUM     = (2.00);   // red, if below this voltage
#define BACKGROUND     0x00A            // a little darker than ILI9341_NAVY
#define cBACKGROUND    0x00A            // 0,   0,  10 = darker than ILI9341_NAVY, but not black
#define cGRIDNAME      ILI9341_GREEN    //
#define cLABEL         ILI9341_GREEN    //
#define cDISTANCE      ILI9341_YELLOW   //
#define cVALUE         ILI9341_YELLOW   // 255, 255, 0
#define cVALUEFAINT    0xbdc0           // darker than cVALUE
#define cDISABLED      0x7bee           // 125, 125, 115 = gray for disabled screen item
#define cHIGHLIGHT     ILI9341_WHITE    //
#define cBUTTONFILL    ILI9341_NAVY     //
#define cBUTTONOUTLINE 0x0514           // was ILI9341_CYAN
#define cTITLE         ILI9341_GREEN    //
#define cTEXTCOLOR     0x67FF           // rgb(102,255,255) = hsl(180,100,70%)
#define cCYAN          ILI9341_CYAN     // rgb(0,255,255) = hsl(180,100,50%)
#define cFAINT         0x0555           // rgb(0,168,168) = hsl(180,100,33%) = blue, between CYAN and DARKCYAN
#define cFAINTER       0x04B2           // rgb(0,128,128) = hsl(180,100,29%) = blue, between CYAN and DARKCYAN
#define cBOXDEGREES    0x0410           // rgb(0,128,128) = hsl(180,100,25%) = blue, between CYAN and DARKCYAN
#define cBUTTONLABEL   ILI9341_YELLOW   //
#define cSTATUS        0xFC10           // 255, 128, 128 = lavender
#define cWARN          0xF844           // brighter than ILI9341_RED but not pink
#define cTOUCHTARGET   ILI9341_RED      // outline touch-sensitive areas
#define cCOMPASSPOINTER ILI9341_YELLOW   // TFT_Compass.h
#define cCOMPASSCIRCLE  ILI9341_GREEN    //
#define cCOMPASSPIVOT   ILI9341_RED      //
#define cCOMPASSLETTERS ILI9341_RED      //
#define cSPEEDOMETER    ILI9341_WHITE    //
#define cBREADCRUMB ILI9341_CYAN   //
#define cVEHICLE    0xef7d         // light gray (white is too bright)
#define cSCALECOLOR ILI9341_DARKGREEN   // pressure graph, I tried yellow but it's too bright
#define cGRAPHCOLOR ILI9341_WHITE       // graphed line of baro pressure
#define cDARKPURPLE 0x2809   // debug: 2809 = very dark purple
#define cDARKRED    0x4000   // debug: 4000 = very dark red
#define cDARKBROWN  0x49A0   // debug: 49A0 = dark orange
#define cDARKGREEN  0x01A0   // debug: #0x01A0 = very dark green
struct Point {
  int x, y;
};
struct PointGPS {
public:
  double lat, lng;
};
#include <TimeLib.h>   // time_t=seconds since Jan 1, 1970, https://github.com/PaulStoffregen/Time
class BaroReading {
public:
  float pressure;   // in millibars, from BMP388 sensor
  time_t time;      // in GMT, from realtime clock
};
struct TwoPoints {
  int x1, y1;
  int x2, y2;
  uint16_t color;
};
struct Rect {
  Point ul;
  Point size;
  bool contains(const Point touch) {
    if ((ul.x <= touch.x) && (touch.x <= ul.x + size.x) && (ul.y <= touch.y) && (touch.y <= ul.y + size.y)) {
      return true;
    } else {
      return false;
    }
  }
};
struct Route {   // screen coordinates
  uint16_t x, y;
};
struct Label {
  char text[26];
  int x, y;
  uint16_t color;
};
typedef void (*simpleFunction)();
struct Button {
  char text[26];
  int x, y;
  int w, h;
  int radius;
  uint16_t color;
  simpleFunction function;
};
struct TimeButton {
  char text[26];
  int x, y;
  int w, h;
  Rect hitTarget;
  int radius;
  uint16_t color;
  simpleFunction function;
};
struct FunctionButton {
  char text[26];       // one line of text, centered
  int x, y;            // fillRoundRect ul corner
  int w, h;            // fillRoundRect size
  Rect hitTarget;      // touch-sensitive area
  int radius;          // radio button size
  uint16_t color;      // text color
  int functionIndex;   // button identifier
};
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

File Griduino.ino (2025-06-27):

/*
  Griduino -- Grid Square Tracker with GPS

  Version history:
            https://github.com/barry-ha/Griduino/blob/master/downloads/CHANGELOG.md

  Software: Barry Hansen, K7BWH, barry@k7bwh.com, Seattle, WA
  Hardware: John Vanderbeck, KM7O, Seattle, WA

  Purpose:  This is a GPS display for your vehicle's dashboard, showing
            your position in your Maidenhead Grid Square, with distances 
            to nearby squares. This is optimized for ham radio rovers. 
            Read about the Maidenhead Locator System (grid squares) 
            at https://en.wikipedia.org/wiki/Maidenhead_Locator_System

            +---------------------------------------+
            |              CN88  30.1 mi            |
            |      +-------------------------+      |
            |      |                      *  |      |
            | CN77 |       CN87              | CN97 |
            | 61.2 |                         | 37.1 |
            |      |                         |      |
            |      +-------------------------+      |
            |              CN86  39.0 mi            |
            |            47.5644, -122.0378         |
            +---------------------------------------+

  Units of Time:
         This relies on "TimeLib.h" which uses "time_t" to represent time.
         The basic unit of time (time_t) is the number of seconds since Jan 1, 1970,
         a compact 4-byte integer.
         https://github.com/PaulStoffregen/Time

  Scheduling:
         This uses the simple but powerful elapsedMillis library originally written
         by Paul Stoffregen at PJRC (manufacturer of the Teensy line).
         The key is that elapsedMillis objects can be reset to zero at any time, 
         allowing the value to be directly compared with a task delay value.
         https://github.com/pfeerick/elapsedMillis/wiki
         https://electricfiredesign.com/2021/03/18/simple-multi-tasking-for-arduino/

  Real Time Clock:
         The real time clock in the Adafruit Ultimate GPS is not directly readable nor
         accessible from the Arduino. It's definitely not writeable. It's only internal
         to the GPS. Once the battery is installed, and the GPS gets its first data
         reception from satellites it will set the internal RTC. Then as long as the
         battery is installed, this program can read the time from the GPS as normal.
         Even without a current "gps fix" the time will be correct.
         The RTC timezone cannot be changed, it is always UTC.

  Tested with:
         1. Arduino Feather M4 Express (120 MHz SAMD51)     https://www.adafruit.com/product/3857

         2. Adafruit Ultimate GPS                           https://www.adafruit.com/product/746
               Tested and works great with the Adafruit Ultimate GPS module (Mediatek MTK33x9 chipset)
         3. Quectel LC86L GPS chip on a breakout board of our own design
               L86 is an ultra compact GNSS POT (Patch on Top) module (MediaTek MT3333 chipset)
               High sensitivity: -167dBm @ Tracking, -149dBm @ Acquisition

         4. Adafruit 3.2" TFT color LCD display ILI-9341    https://www.adafruit.com/product/1743
            How to:      https://learn.adafruit.com/adafruit-2-dot-8-color-tft-touchscreen-breakout-v2
            SPI Wiring:  https://learn.adafruit.com/adafruit-2-dot-8-color-tft-touchscreen-breakout-v2/spi-wiring-and-test
            Touchscreen: https://learn.adafruit.com/adafruit-2-dot-8-color-tft-touchscreen-breakout-v2/resistive-touchscreen

         5. Adafruit BMP388 Barometric Pressure, SPI        https://www.adafruit.com/product/3966
            Adafruit BMP280 Barometric Pressure, I2C        https://www.adafruit.com/product/2651
 
         5. One-chip audio amplifier, digital potentiometer and mini speaker
            Speaker is a commodity item and many devices and options are available.
            We tested a piezo speaker but they're tuned for a narrow frequency and 
            unsatisfactory for anything but a single pitch.
            Breadboard-friendly speaker:   https://www.adafruit.com/product/1898
            Better fidelity speaker:       https://www.adafruit.com/product/4445
            Micro speaker:                 https://www.digikey.com/en/products/detail/cui-devices/CES-20134-088PM/10821309

  Source Code Outline:
         1. Hardware Wiring  (pin definitions)
         2. Helper Functions (touchscreen, fonts, grids, distance, etc)
         3. Model
         4. Views
         5. Controller
         6. setup()
         7. loop()
*/

#include <Adafruit_ILI9341.h>         // TFT color display library
#include <Resistive_Touch_Screen.h>   // Touchscreen built in to 3.2" Adafruit TFT display
#include <Adafruit_GPS.h>             // Ultimate GPS library
#include <Adafruit_NeoPixel.h>        // On-board color addressable LED
#include <DS1804.h>                   // DS1804 digital potentiometer library
#include <elapsedMillis.h>            // Scheduling intervals in main loop
#include "save_restore.h"             // save/restore configuration data to SDRAM
#include "constants.h"                // Griduino constants, colors, typedefs
#include "hardware.h"                 // Griduino pin definitions
#include "logger.h"                   // conditional printing to Serial port
#include "grid_helper.h"              // lat/long conversion routines

#include "view.h"                     // Griduino screens base class, followed by derived classes in alphabetical order
#include "view_altimeter.h"           // altimeter
#include "view_battery.h"             // coin battery
#include "view_baro.h"                // barometric pressure graph
#include "view_events.h"              // counting days to/from calendar events
#include "view_grid.h"                // primary grid displays of position or speed+compass
#include "view_grid_crossings.h"      // list of time spent in each grid
#include "view_help.h"                // help screen
#include "view_sat_count.h"           // show number of satellites acquired
#include "view_screen1.h"             // starting screen animation
#include "view_splash.h"              // splash screen
#include "view_status.h"              // status screen 
#include "view_ten_mile_alert.h"      // microwave rover screen
#include "view_time.h"                // GMT time screen 

#include "cfg_audio_type.h"           // config audio Morse/speech
#include "cfg_crossing.h"             // config 4/6 digit crossing
#include "cfg_gps.h"                  // config GPS (alphabetical order)
#include "cfg_gps_reset.h"            // config GPS reset to factory
#include "cfg_nmea.h"                 // config NMEA broadcasting
#include "cfg_reboot.h"               // show firmware update option
#include "cfg_reformat.h"             // reformat flash memory
#include "cfg_rotation.h"             // config screen rotation 
#include "cfg_units.h"                // config english/metric
#include "cfg_volume.h"               // config volume level

#if defined(SAMD_SERIES)
  #warning ----- Compiling for Arduino Feather M4 Express -----
#elif defined(ARDUINO_ADAFRUIT_FEATHER_RP2040)
  #warning ----- Compiling for Arduino RP2040 -----
#else
  #error Hardware platform unknown.
#endif

// ---------- extern
//extern bool newScreenTap(Point* pPoint);       // Touch.cpp
//extern uint16_t myPressure(void);              // Touch.cpp
//void initTouchScreen(void);                    // Touch.cpp
void processCommand(char *cmd);                // commands.cpp

// ---------- TFT display
Adafruit_ILI9341 tft = Adafruit_ILI9341(TFT_CS, TFT_DC);

// ---------- Touch Screen
Resistive_Touch_Screen tsn(PIN_XP, PIN_YP, PIN_XM, PIN_YM, XP_XM_OHMS);

// to select a different SPI bus speed, use this instead:
// -----------------------------------------------
//    #include <Adafruit_SPIDevice.h>           // from library Adafruit_BusIO, file Adafruit_SPIDevice.h
//    #define SPL06_DEFAULT_SPIFREQ (1000000)   // clock speed, default is spi_dev =
//    Adafruit_SPIDevice mySPI = 
//        Adafruit_SPIDevice(TFT_CS,                  // chip select
//                           SPL06_DEFAULT_SPIFREQ,   // frequency
//                           SPI_BITORDER_MSBFIRST,   // bit order
//                           SPI_MODE0,               // data mode
//                           theSPI);
//    if (!spi_dev->begin()) {
//      return false;
//    }
//    Adafruit_ILI9341(mySPI, TFT_DC, TFT_CS);
// -----------------------------------------------

// Hardware serial port for USB
Logger logger = Logger();

// Hardware serial port for GPS
Adafruit_GPS GPS(&Serial1);           // https://github.com/adafruit/Adafruit_GPS
/* "Ultimate GPS" pin wiring is connected to a dedicated hardware serial port
    available on an Arduino Mega, Arduino Feather and others.

    The "Ultimate GPS" LED indicates status:
        1-sec blink = searching for satellites
        15-sec blink = position fix found
*/

// ---------- config settings
// these are controllable by serial USB commands (command.h)
bool showTouchTargets = false;
bool showCenterline   = false;

// ---------- lat/long and date/time conversion utilities
Grids grid = Grids();
Dates date = Dates();

// ---------- Neopixel
Adafruit_NeoPixel pixel = Adafruit_NeoPixel(NUMPIXELS, PIN_NEOPIXEL, NEO_GRB + NEO_KHZ800);

// ---------- Digital potentiometer
// ctor         DS1804( ChipSel pin, Incr pin,  U/D pin,  maxResistance (K) )
#if defined(ARDUINO_ADAFRUIT_FEATHER_RP2040)
  // todo - for now, RP2040 has no DAC, no volume control, no audio output
#else
  DS1804 volume = DS1804( PIN_VCS, PIN_VINC, PIN_VUD, DS1804_TEN );
#endif

int gWiper = 15;                      // initial digital potentiometer wiper position, 0..99
int gFrequency = 1100;                // initial Morse code sidetone pitch
int gWordsPerMinute = 18;             // initial Morse code sending speed

// ------------ definitions
const int howLongToWait = 6;          // max number of seconds at startup waiting for Serial port to console

// ---------- Morse Code ----------
#include "morse_dac.h"                // Morse Code using digital-audio converter DAC0
#if defined(ARDUINO_ADAFRUIT_FEATHER_RP2040)
  // todo - for now, RP2040 has no DAC, no speech, no audio output
#else
  DACMorseSender dacMorse(DAC_PIN, gFrequency, gWordsPerMinute);
#endif

// ----------- Speech PCM Audio Playback
#if defined(ARDUINO_ADAFRUIT_FEATHER_RP2040)
  // todo - for now, RP2040 has no DAC, no speech, no audio output
#else
  #include <Audio_QSPI.h>               // Audio playback library for Arduino
                                        // https://github.com/barry-ha/Audio_QSPI
  AudioQSPI dacSpeech;
#endif

// 2. Helper Functions
// ============== Touchable spots on all screens ===============
Rect areaGear { {0,                  0},  {gScreenWidth * 4/10, gScreenHeight * 5/10}};
Rect areaArrow{ {gScreenWidth *5/10, 0},  {gScreenWidth * 5/10, gScreenHeight * 5/10}};
Rect areaBrite{ {0, gScreenHeight *2/3},  {gScreenWidth,       (gScreenHeight * 1/3)-1}};

void showDefaultTouchTargets() {
  if (showTouchTargets) {
    tft.drawRect(areaGear.ul.x,areaGear.ul.y,   areaGear.size.x, areaGear.size.y,  ILI9341_MAGENTA);
    tft.drawRect(areaArrow.ul.x,areaArrow.ul.y, areaArrow.size.x,areaArrow.size.y, ILI9341_MAGENTA);
    tft.drawRect(areaBrite.ul.x,areaBrite.ul.y, areaBrite.size.x,areaBrite.size.y, ILI9341_MAGENTA);
  }
}

void showWhereTouched(ScreenPoint touch) {
  if (showTouchTargets) {
    const int radius = 1;     // debug
    tft.fillCircle(touch.x, touch.y, radius, cTOUCHTARGET);  // debug - show dot
  }
}

// ============== helpers ======================================
void floatToCharArray(char* result, int maxlen, double fValue, int decimalPlaces) {
  String temp = String(fValue, decimalPlaces);
  temp.toCharArray(result, maxlen);
}

//==============================================================
//
//    GPS Model
//    This is MVC (model-view-controller) design pattern
//
//    This model collects data from the GPS sensor
//    on a schedule determined by the Controller.
//
//    The model knows about:
//    - current grid info, such as lat/long and grid square name
//    - nearby grids and distances
//    - when we enter a new grid
//    - when we lose GPS signal
//
//    We use "class" instead of the usual collection of random subroutines 
//    to help guide the programmer into designing an independent Model object 
//    with very specific functionality and interfaces.
//==============================================================
#include "model_gps.h"                // Model of a GPS for model-view-controller

// create an instance of the GPS model
Model modelGPS;                       // normal: use real GPS hardware
MockModel modelSimulator;             // test: simulated travel (see model_gps.h)

// at power-on, we choose to always start with real GPS receiver hardware 
// because I don't want to bother saving/restoring this selection right now
Model* model = &modelGPS;

void fSetReceiver() {
  model = &modelGPS;                  // use "class Model" for GPS receiver hardware
}
void fSetSimulated() {
  model = &modelSimulator;            // use "class MockModel" for simulated track
}
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
void loop() {

  GPS.read();   // if you can, read the GPS serial port every millisecond

  if (GPS.newNMEAreceived()) {
    // optionally send NMEA sentences to Serial port, possibly for NMEATime2
    // Note: Adafruit parser doesn't handle $GPGSV (satellites in vieW) so we send all sentences regardless of content
    // But first, our GPS sends several NMEA sentences in a row, so let's flag the start of each group in the log
    char firstNMEA[7] = "$GPGGA";
    if (strncmp(GPS.lastNMEA(), firstNMEA, sizeof(firstNMEA)-1) == 0) {
      // insert divider into log for readability
      char divider[5] = "----";
      logger.log(NMEA, INFO, divider);
    }
    logger.log(NMEA, INFO, GPS.lastNMEA());

    // sentence received -- verify checksum, parse it
    // a tricky thing here is if we print the NMEA sentence, or data
    // we end up not listening and thereby might miss other sentences
    // so be very wary if using OUTPUT_ALLDATA, which generates loads of sentences,
    // since trying to print them all out is time-consuming
    // GPS parsing: https://learn.adafruit.com/adafruit-ultimate-gps/parsed-data-output
    if (!GPS.parse(GPS.lastNMEA())) {
      // parsing failed -- restart main loop to wait for another sentence
      // this also sets the newNMEAreceived() flag to false
      return;
    }
  }

  // look for the first "setTime()" to begin the datalogger
  if (waitingForRTC && date.isDateValid(GPS.year, GPS.month, GPS.day)) {
    // found a transition from an unknown date -> correct date/time
    // assuming "class Adafruit_GPS" contains 2000-01-01 00:00 until
    // it receives an update via NMEA sentences
    // the next step (1 second timer) will actually set the clock
    waitingForRTC = false;

    char msg[128];                    // debug
    snprintf(msg, sizeof(msg), "Received first valid GPS time: %d-%02d-%02d at %02d:%02d:%02d",
                                GPS.year,GPS.month,GPS.day, 
                                GPS.hour,GPS.minute,GPS.seconds);
    logger.log(CONFIG, INFO, msg);    // debug

    // write this to the breadcrumb trail as preliminary indication of acquiring satellites
    TimeElements tm{GPS.seconds, GPS.minute, GPS.hour, 0, GPS.day, GPS.month, (byte)(2000-1970+GPS.year)};
    time_t firstTime = makeTime(tm);
    trail.rememberFirstValidTime(firstTime, GPS.satellites);
    trail.saveGPSBreadcrumbTrail();   // ensure its saved for posterity
  }

  // every 1 second update the realtime clock
  if (displayClockTimer > CLOCK_DISPLAY_INTERVAL) {
    displayClockTimer = 0;

    // update RTC from GPS
    if (date.isDateValid(GPS.year, GPS.month, GPS.day)) {

      setTime(GPS.hour, GPS.minute, GPS.seconds, GPS.day, GPS.month, GPS.year);
      // adjustTime(offset * SECS_PER_HOUR);  // todo - adjust to local time zone. for now, we only do GMT
    }
    pView->updateScreen();                   // update time on current view
  }

  // periodically save the number of satellites acquired for later analysis
  static elapsedSeconds satCountTimer;       // timer for saving number of GPS satellites
  const int SAT_SAVE_INTERVAL = 30;          // every thirty seconds
  if (satCountTimer > SAT_SAVE_INTERVAL) {
    satCountTimer = 0;

    satCountView.push(now(), model->gSatellites);
  }

  // send RTC to a (possible) Windows program, e.g. https://github.com/barry-ha/Laptop-Griduino
  // as GMT using ISO date/time formatted string: YYYY-MM-DD[*HH[:MM[:SS[.fff[fff]]]][+HH:MM[:SS[.ffffff]]]]
  // e.g. 2022-01-02 12:34+00:00
  // Note: do not use the GPS clock, since it might not have sat lock and therefore no reports
  time_t rtc = now();
  if (second(rtc) != second(prevTimeRTC)) {    // if RTC has ticked over to the next second
    char msg[32];      // strlen("2022-01-01 21:49:49+00:00") = 25
    snprintf(msg, sizeof(msg), "%04d-%02d-%02d %02d:%02d:%02d+00:00\n",
                         year(rtc), month(rtc), day(rtc), hour(rtc), minute(rtc), second(rtc));
    logger.log(GMT, INFO, msg);
    prevTimeRTC = rtc;
  }

  // every 15 minutes read barometric pressure and save it in nonvolatile RAM
  // synchronize showReadings() on exactly 15-minute marks 
  // so the user can more easily predict when the next update will occur
  time_t rightnow = now();
  if (rightnow >= nextSavePressure) {

    // log this pressure reading only if the time-of-day is correct and initialized
    if (timeStatus() == timeSet) {
      baroModel.logPressure(rightnow);
      //redrawGraph = true;             // request draw graph
      nextSavePressure = date.nextFifteenMinuteMark( rightnow ); // production
      //nextSavePressure = date.nextOneMinuteMark( rightnow );   // debug
    }
  }

  // periodically, ask the model to process and save the current GPS location
  if (saveGpsTimer > GPS_PROCESS_INTERVAL) {
    saveGpsTimer = 0;
//  if (millis() - prevTimeGPS > GPS_PROCESS_INTERVAL) {
//    prevTimeGPS = millis();           // restart another interval

    model->processGPS();               // update model

    // update View
    pView->updateScreen();             // update current view, eg, updateGridScreen()
  }

  //if (!spkrMorse.continueSending()) {
  //  // give processing time to SpeakerMorseSender component
  //  // "continueSending" returns false after the message finishes sending
  //}

  // check for transition to "loss of signal"
  if (model->signalLost()) {   // test and write LOS and AOS to gps history log
    losTimer = 0;              // start timer for announcing LOS
  }

  // if GPS enters a new grid, notify the user and draw new display screen
  char newGrid6[7];
  grid.calcLocator(newGrid6, model->gLatitude, model->gLongitude, 6);

  if (model->enteredNewGrid4()) {
    logger.fencepost("Griduino.ino new grid4",__LINE__);  // debug

    pView->startScreen();          // update display so they can see new grid while listening to audible announcement
    pView->updateScreen();
    announceGrid(newGrid6, 4);     // announce with Morse code or speech, according to user's config

    Location whereAmI;
    model->makeLocation(&whereAmI);
    trail.rememberGPS(whereAmI);
    trail.saveGPSBreadcrumbTrail();   // entered new 4-digit grid

    model->save();                 // entered new 4-digit grid

  } else if (model->enteredNewGrid6()) {
    logger.fencepost("Griduino.ino new grid6",__LINE__);  // debug
    if (!model->compare4digits) {
      announceGrid(newGrid6, 6);   // announce with Morse code or speech, according to user's config
    }
    Location whereAmI;
    model->makeLocation(&whereAmI);
    trail.rememberGPS(whereAmI);    // when we enter a new 6-digit grid, save it in breadcrumb trail
    trail.saveGPSBreadcrumbTrail();   // entered new 6-digit grid 
    // one user's home was barely in the next grid6
    // and we want to show his grid6 at next power up
    // ALSO when entering a 6-digit grid: tell the model to save itself!
    // It's the _model_ that puts up the starting location at next power-up 
    model->save();                  // entered new 6-digit grid 
  }

  // if we drove far enough, add this to the breadcrumb trail
  static PointGPS prevRememberedGPS{0.0, 0.0};
  PointGPS currentGPS{model->gLatitude, model->gLongitude};
  if (grid.isVisibleDistance(prevRememberedGPS, currentGPS)) {
    Location whereAmI;
    model->makeLocation(&whereAmI);
    trail.rememberGPS(whereAmI);
    prevRememberedGPS = currentGPS;

    if (0 == (trail.getHistoryCount() % trail.saveInterval)) {
      logger.log(GPS_SETUP, DEBUG, "Moved a visible distance (line %d)", __LINE__);  // debug
      trail.saveGPSBreadcrumbTrail();   // have moved a visible distance
    }
  }

  // if we lost GPS signal for a long time, issue audible announcement
  if (model->gHaveGPSfix) {
    // satellites are in view, business as usual, restart LOS timer
    losTimer = 0;
  } else {
    // no GPS position available, let's wait see if it's reacquired soon
    if (losTimer > LOS_ANNOUNCEMENT_INTERVAL) {
      // it's been a few minutes without GPS
      sendMorseLostSignal();    // announce GPS signal lost by Morse code
      losTimer = 0;             // restart LOS timer
    }
  }

  // periodically log the coin battery's voltage 
  // todo: sensor exists only on PCB v7+
  if (batteryTimer > LOG_COIN_BATTERY_INTERVAL) {
    batteryTimer = 0;

    const float analogRef     = 3.3;    // analog reference voltage
    const uint16_t analogBits = 1024;   // ADC resolution is 10 bits

    int coin_adc       = analogRead(BATTERY_ADC);
    float coin_voltage = (float)coin_adc * analogRef / analogBits;
    logger.logFloat(BATTERY, INFO, "Coin battery = %sv", coin_voltage, 3);

    trail.rememberBAT(coin_voltage);
  }
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

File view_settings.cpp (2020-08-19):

/*
  File: view_settings.cpp

  Software: Barry Hansen, K7BWH, barry@k7bwh.com, Seattle, WA
  Hardware: John Vanderbeck, KM7O, Seattle, WA

  Purpose:  This is the 'control panel' for one-time Griduino setup.
            Since it's NOT intended for a driver in motion, we use a
            much smaller font and cram more stuff onto the screen.

            +-----------------------------------+
            | Settings                          |
            |                                   |
            | Breadcrumb trail    [ Clear ]     |
            | 123 of 6000                       |
            |                                   |
            | Route         (o)[ GPS Receiver ] |
            |                  [  Simulator   ] |
            |                                   |
            | Version 0.21                      |
            |     Compiled Aug 18 2020  19:32   |
            +-----------------------------------+
*/

#include <Arduino.h>
#include "Adafruit_ILI9341.h"       // TFT color display library
#include "constants.h"              // Griduino constants and colors
#include "model.cpp"                // "Model" portion of model-view-controller
#include "TextField.h"              // Optimize TFT display text for proportional fonts

// ========== extern ===========================================
extern Adafruit_ILI9341 tft;        // Griduino.ino
extern Model* model;                // "model" portion of model-view-controller

void fSetReceiver();                // Griduino.ino
void fSetSimulated();               // Griduino.ino
int fGetDataSource();               // Griduino.ino
void setFontSize(int font);         // Griduino.ino
int getOffsetToCenterTextOnButton(String text, int leftEdge, int width ); // Griduino.ino
void drawAllIcons();                // draw gear (settings) and arrow (next screen) // Griduino.ino

// ========== forward reference ================================
void fClear();
void fReceiver();
void fSimulated();
void fFactoryReset();

// ============== constants ====================================
// vertical placement of text rows
const int yRow1 = 70;             // "Breadcrumb trail", "Clear"
const int yRow2 = yRow1 + 20;     // "%d of %d"
const int yRow3 = yRow2 + 50;     // "Route", "GPS Receiver"
const int yRow4 = yRow3 + 38;     // "Simulator"
const int yRow9 = 234;            // text: "v0.21, Aug 18 2020 12:34:56"

// color scheme: see constants.h
#define col1 10                   // left-adjusted column of text
#define xButton 160               // indented column of buttons

// ========== globals ==========================================
enum txtSettings {
  SETTINGS=0, 
  TRAIL,   TRAILCOUNT,
  GPSTYPE, /*RECEIVER, SIMULATED,*/
  COMPILED,
};
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

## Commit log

2020-01-06 no functional change
    Commented out a "Serial.print" debug statement about "omg, you touched the screen"
2020-01-06 added string length limit protective coding
    Try to avoid runaway string print (snprintf) while debugging a crasher bug in model's date
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2020-01-14 cosmetic comment updates
    no functional changes
    [BOM Griduino 2020-01-12.xlsx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]
2020-01-14 remove accidentally committed temp file
    [Griduino-B_Cu.gbr]
2020-01-14 remove accidentally committed file
    [Griduino-B_Mask.gbr]
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2020-03-05 fix include "SPI.h"
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2020-03-24 update BOM after assembling a Rev.2 board
    Removed unused connectors, changed all electrolytics to 25v, reduced PCB price to reflect 2-layer board
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2020-04-29 insert function isTouching(void) which is missing from Touch library
    A few changes to comments, too.
    [Barograph.ino]
2020-04-29 moved "TouchScreen::isTouching(void)" into main program
    "isTouching()" implementation is missing from the Touch library. At first we modified the library but then it goes missing again if the Github library is updated. So we put it here for all eternity.
    [Griduino.ino]
2020-04-30 patch isTouching() to fix GPS instability
    [Griduino.ino]
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2020-05-02 fix GPS instability by making iTouching() run faster
    [Griduino.ino]
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2020-05-04 fix TouchScreen::isTouching() using CraigV's new code
    [Griduino.ino]
2020-05-05 move three buttons toward bottom of screen, making more room for title and "next screen" touch
2020-05-07 set screen orientation, selectable 180-degree flip
    Lets you flip the device to use it with the Arduino USB connector on either the top or bottom.
    [Griduino.ino, constants.h]
2020-05-13 updated TouchScreen code
    Implement TouchScreen::isTouching() which is missing from Adafruit's TouchScreen.cpp module.
    Replace TouchScreen::pressure() with ::myPressure() because Adafruit has a bug. That is, one of the DAC reads (z2) was reporting a reversed value. That is, 1023 for no pressure, somewhere in the 500's if the screen was pressed
    [Altimeter.ino, Barograph.ino, Griduino.ino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]
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2020-05-21 add route history array to the model
    By saving the route history, the track can be redisplayed when changing views. Previously the "history" was only retained in the TFT display module.
2020-05-23 fix static text; add print(float)
2020-05-25 make buttons have a smaller touch target
    Currently, the whole screen is divided into two very large touch targes: "left" and "right". This made the unit hard to handle because it'd react to almost anything. Now, the button targets are much smaller -- they're still larger than the button icons, but not too large. There's a new #define SHOW_TOUCH_TARGET that will enable drawing the target boundaries.
2020-05-27 calculate the degrees lat/long of the box shown which contains current grid square
2020-06-02 refactored to replace all 'class String' in the model with 'char*'
    [Griduino.ino]
2020-06-03 remove unused font global vbls
    Now that class TextField handles placing text on the screen, we no longer need to keep track of character cell dimensions. This cleans up the font code before refactoring it. Removed: gUnitFontWidth, gUnitFontHeight, gCharWidth, gCharHeight.
    [Griduino.ino]
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2020-06-23 preparing to add new "Settings" view
    This step updates the visual appearance of the Hints screen by adding a "Settings" button, without actually detecting or implementing the new button.
2020-06-23 add skeleton of "View Settings" (not working yet)
    [Griduino.ino, view_settings.cpp]
2020-07-05 implement new "settings" layout
    Added just only the settings screen layout; the buttons are not functional yet.
2020-07-07 change "model" reference to use a pointer
    This is in preparation for a user setting at runtime to select GPS Receiver vs simulated track (MockModel object)
2020-07-17 Add Gerber files for PCB v4
    Anyone can order PCBs using this known-good thru-hole layout generated by Kicad.
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2020-08-01 fix image for ceramic capacitors
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2020-08-14 implement switching views using new icons
    We rotate three user views: Grid -> GPS Status -> GMT Time
    and two control panel views: Audio Volume -> Settings
2020-08-17 fix image links in assembly instructions
2020-08-17 fix image links in assembly instructions
    Previously, the ASSEMBLY document moved from root to a new folder "docs" and didn't update the paths. Today, I moved all the images to a subfolder "docs/img" and edited the paths in the document to match.
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2020-08-20 v0.21 fixed audio volume set-save-restore bug
    The setup() routine needs to set the digital potentiometer hardware to a known state, so it will match the software object that keeps track of increment/decrement commands. So we added "volume.setToZero()"
    [Griduino.ino]
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2020-08-27 updated Barograph UI
    Major change. Display three days of barometer readings instead of just two. Improve text with more readable fonts, colors and sizes. The rising/falling arrow doesn’t appeal to me, so removed it. Later will replace it with a trend line on the graph for recent pressure readings.
    [Baroduino.ino, constants.h]
2020-08-28 added save/restore barometric pressure history to non-volatile RAM
    Also moved hardware pin definitions to a central place "constants.h" (for now). Since this is common to all example programs for Griduino, it should probably become its own file, such as "hardware.h"
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2020-09-02 replaced view subroutines (screens) with base class "View" and derived classes
    [Griduino.ino, constants.h, view.h]
2020-09-03 cleaned up spurious "showNameOfView()" and fixed errors from conditional compile
    [Griduino.ino]
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2020-09-20 replaced (yy,mm,dd,hh,mm,ss) with time_t structure
    [Baroduino.ino]
2020-09-20 fixed time-of-day clock display
    [Baroduino.ino]
2020-09-20 fixed compile error for #define RUN_UNIT_TESTS
    [Baroduino.ino, constants.h]
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2020-09-27 fixed drawGraph, added unit test
    [Baroduino.ino]
2020-09-30 tried to fix timing so that first graph would be shown right away. Getting closer but it's not working yet, still has a 5-min delay to first graph.
    [Baroduino.ino, constants.h]
2020-09-30 fixed scheduling of 5-minute and 15-minute events (show pressure, and log pressure)
    [Baroduino.ino]
2020-09-30 fixed auto-scaling for empty array of stored pressure values
    [Baroduino.ino]
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2020-10-09 fixed illustration to put circles around all five electrolytic capacitors
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2020-10-16 fixed remnant line after waitForSeial() animation, fixed delay with blank screen after animation
    [Griduino.ino]
2020-10-20 renamed model.cpp to model_gps.h
    This is in preparation for adding another "model" to our MVC design for handling barometric pressure/temperature hardware
2020-10-27 changed IIR filter to be more lively; fixed serial port debug messages
    [Baroduino.ino]
2020-10-28 added hole to click Reset button with a toothpick without removing cover
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2020-10-29 resolved the missing "Adafruit SAMD Boards" issue during Arduino IDE setup
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2020-11-03 slowed the ground speed of simulated travel, so it won't announce 6-digit grid crossings as often
    [model_gps.h]
2020-11-22 refined descriptions of TVS diode, testing Feather, case options, and using Griduino
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2020-12-19 fixed background color of activity indicator on bottom row
    [Baroduino.ino, Griduino.ino, constants.h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]
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2020-12-28 added test program that generates audio tones by playing a waveform table from interrupt level
2021-01-21 changed one 20-pin socket to two 2-pin sockets on the display; added solder suggestion
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2021-01-30 revised assembly instructions for 2-pin headers under TFT display. Added photos. Other minor updates found while assembling SN024.
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2021-01-30 starting work on sending Morse code from interrupt level, an unfinished prototype
2021-01-31 updated to use latest Adafruit_BMP3XX library v2.0, for the BMP390 pressure sensor
2021-01-31 added how to use a toothpick for the hole in the front cover to reach Reset button
2021-02-01 version 0.31: fixed vertical scale and tick marks on vertical axis
    [Baroduino.ino]
2021-02-02 changed "miles/kilometers" to "english/metric" so it handles barometric pressure units along with distances
2021-02-02 added a "clear selected screen rows" function so that drawing pressure graph doesn't blink entire screen
    [view.h]
2021-02-02 merged pressure graph from the Baroduino example into the main Griduino program as a new "view"
2021-02-03 fixed setting for english/metric config so it's saved after it's changed
    [constants.h, model_baro.h, model_gps.h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]
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2021-02-11 shortened name of color from cTEXTFAINT to cFAINT because it's more memorable
    [view.h]
2021-02-25 fixed the 3-day graph so it fills all three days, not just 2 days
    [model_baro.h]
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2021-02-25 fixed "Sync" button to auto adjust Altitude from barometer reading to match the Altitude from GPS reading
    [view_altimeter.h]
2021-02-25 version 0.34: fixed several bugs in Altimeter. Fixed the 3-day graph of barometric pressure.
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2021-03-17 added new program to list files on the 2MB onboard flash memory Quad-SPI chip
2021-03-25 changed order to install barometric sensor and battery holder (short items) before GPS (tall item)
2021-03-29 fixed remaining issues; it can play sample audio okay
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2021-04-08 fixed typos in comments
    [Baroduino.ino]
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2021-04-25 added console message to help debug a Baroduino time problem
    [Griduino.ino]
2021-04-26 replaced entire status screen layout with "Grid Size and Scale" information
    [constants.h]
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2021-06-24 updated list of interesting count-down events, added "More" button to cycle between the 5 events
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2021-07-10 fixed Altimeter display problem with screen orientation
    [Griduino.ino, cfg_rotation.h, constants.h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]
2021-07-10 fixed screen orientation problem
    [view_altimeter.h]
2021-07-12 fixed saving timezone offset from GMT to local time
    [model_gps.h]
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2021-07-21 fixed Microwave Rover view
    [view_ten_mile_alert.h]
2021-07-21 fixed typo in comment
    [constants.h]
2021-08-07 Fixed the Ten Mile Alert screen
    [Griduino.ino, constants.h, view_date.h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]
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2021-10-11 version 1.06: added "internal case temperature" to main display; new starburst animation
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2022-05-21 updated TFT resistance calibration values
    Modern TFT displays have apparently changed the resistance values used on the touch panel. Current calibration is way off.
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2022-06-03 re-check the file system every 30 seconds
    Periodically repeat the entire file test, to allow the user to attach to the serial monitor at any time
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2022-06-06 fix volume control
    Random bug in only some units that leave volume level at a fixed level and not responding to touch control.
    [Griduino.ino, cfg_volume.h]
2022-06-06 refactored pin definitions into hardware.h (no functional change)
    advanced version number to 1.08
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2022-06-06 refactored pin definitions into hardware.h
    also formatted with clang, advanced version number to 1.08
2022-06-06 refactored pin definitions into hardware.h
    formatted with clang; bump version number to 1.08
2022-06-08 fixed hang condition in startup Hint screen
    The GPS data logger history buffer was too large, causing memory problems. Reduced size from 'history[1600]' to 'history[1500]'. Change file signature to v11, to force everyone to rewrite new GPS data log.
    [Griduino.ino, model_gps.h, save_restore.cpp]
2022-06-18 fixed hang on Hints screen
    Rewrote entire save/restore of GPS history file. It will use a CSV text file instead of blobbing the C++ object to NVR.
    [model_gps.h, save_restore.cpp]
2022-06-18 fixed hang on Hints screen
    [Griduino.ino]
2022-06-19 fixed infinite loop when gpshistory.csv file not found
    [model_gps.h, save_restore.cpp]
2022-06-21 fixed 'nextHistoryItem' pointer
    After restoring GPS bread crumb trail, the next GPS item logged goes into the first empty slot. If no slots are empty, then find the oldest item and begin overwriting there.
    [model_gps.h]
2022-06-23 changed Serial.print() to logger.info()
    We want to "quiet down" the USB console to reduce jitter of time messages sent to NMEATime2 (www.visualgps.com). This is a first step.
    [cfg_audio_type.h, cfg_gps.h, cfg_rotation.h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]
2022-07-27 replace Serial.print() with logger.info()
    This change assigns levels to output messages (debug, info, warning, error) and allows them to be turned on/off to make output more readable.
    [cfg_volume.h, model_baro.h, model_gps.h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]
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2022-08-21 removed include Arduino.h
    "include Arduino.h" has been moved into constants.h, and is no longer needed here
    [model_baro.h]
2022-08-29 added prototype "Grid Crossing Log"
    The main idea is to summarize when and how long you were in the most recent grids. This provides a way to check that your WSJT log file has the right grids at the right times.
2022-08-29 added command show/hide touch
    This is a debug feature to visually show the exact screen area to which a button will respond. We changed a compile-time option to run-time control.
2022-08-31 added new command "view help"
    This will switch Griduino display to the Help screen, allowing it to remain as long as you want. This aids debugging.
2022-09-01 removed #define USE_SIMULATED_GPS
    Obsolete. This has long since be replaced with a run-time GPS simulator function.
    [constants.h, model_gps.h]
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2022-11-04 replaced SaveRestore class with a do-nothing stub
    temporarily removed all save/restore to work around a File vs SDFile class problem
    [save_restore.cpp]
2022-11-12 created software reset example
    The first version will reset the Arduino. This is a bit easier than single-clicking the reset button especially if the cover is on.
2022-11-14 changed KML to bullets with timestamps
    Removed the line between GPS coordinates and added timestamps. This allows Google Earth to show when you're at each spot, which helps you to verify logbook entries have used the correct grid square.
    [model_gps.h]
2022-11-16 added "How to Use a Serial Console"
    This description helps you download GPS tracks from Griduino without the Arduino IDE.
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2022-11-22 Revert "removed unused variable declaration"
    This reverts commit b58602414359c624375ab5b8437ac3b82c623001.
    [model_gps.h]
2022-11-26 fixing the GPS breadcrumb history
    The NMEA date is not being correctly converted to time_t timestamps in the history[] array
    [model_gps.h]
2022-11-26 fixed date stamp in GPS history trail
    works!
    [model_gps.h]
2022-12-04 fixed grid8 calculator
    This was a 'to-do' item. The 8-char grids were not previously implemented. Also rewrote the whole calcLocator() method in a much more understandable and extendible style.
    [grid_helper.h]
2022-12-12 added simple USB REBOOT screen button
    [Griduino.ino]
2022-12-12 removed BMP388 error message from RP2040
    The Rev.6 hardware does not have any pressure sensor.
    [Griduino.ino]
2022-12-13 refactored rebootGriduino(), modified default touch spots
    Moved rebootGriduino() to new module view_reboot.h
    [Griduino.ino]
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2022-12-22 fixed screen brightness control on rp2040
    For ver.6 hardwared with rp2040, we replaced analogWrite() with its new programmable PWM capability. Also changed pin number from 4 to 6 in hardware.h.
    [Griduino.ino]
2022-12-23 changed pin A0 (DAC0) to be input-only on RP2040 so it doesn't load 3v coin battery
    [Griduino.ino, morse_dac.h]
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2023-01-10 fixed Altimeter example so it works both Feather M4 + RP2040
    [Altimeter.ino]
2023-01-10 fixed Barograph example for both Feather M4 + RP2040
    [Barograph.ino]
2023-01-14 fixed a log message
    [cfg_rotation.h]
2023-01-14 fixed file handling both Feather M4 & RP2040
    [save_restore.cpp]
2023-01-14 fixed compiler errors in Feather M4 target
    [view_reboot.h]
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2023-02-08 fixed case of filename Arduino.h
    In response to my new 'lint' github action output listing
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2023-03-05 starting to fix Baraduino hang condition
    [Baroduino.ino, model_baro.h]
2023-03-13 fixed barometric pressure
2023-03-21 fixed assembly.doc broken h3
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2023-03-21 fixed compile error for measuring coin battery
    [Griduino.ino, model_adc.h, model_gps.h]
2023-03-24 fixed analog read coin battery
    [model_adc.h]
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2023-03-28 fixed BMP280 sensor
    Note that I2C on the rp2040 requires Wire1 (not Wire)
    [model_baro.h]
2023-03-29 fixed compile error
    There was a compile error as a result of merge
    [Griduino.ino, cfg_volume.h]
2023-03-30 changed a Serial.print to logger.error
    [Griduino.ino]
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2023-03-30 removed "Reboot" option from Help screen and from touch-handling
    This is the first step in moving "Reboot" to a settings screen.
    [Griduino.ino]
2023-03-30 moved 'reboot' screen into configuration menus
    [Griduino.ino, cfg_reboot.h, view_screen1.h]
2023-03-31 fixed command "dump gps"
    The format specifiers were miscounted and misaligned.
    [model_gps.h]
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2023-04-08 fixed isEmpty() and isGPS()
    [constants.h]
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2023-04-09 fixed save/restore breadcrumb trail
    Significant update to unittest.cpp for testing history[] trail to files
    [Griduino.ino, model_breadcrumbs.h]
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2023-04-10 refactored breadcrumb trail
    Removed all "nextHistoryItem" and replaced with head/tail/iterator
    [model_breadcrumbs.h]
2023-04-11 fixed iterators on breadcrumb trail
    [model_breadcrumbs.h]
2023-04-11 replaced with Griduino's latest constants.h
    [constants.h]
2023-04-12 fixed bugs in breadcrumb trail
    [Griduino.ino, model_breadcrumbs.h, model_gps.h]
2023-04-13 fixed an extra result returned from next() function
    [model_breadcrumbs.h]
2023-04-13 fixed runaway trail save
    [Griduino.ino]
2023-04-19 fixed case-sensitive compare
    WSJT-X stores current grid as EL29GP and AutoGrid has it as EL29gp, causing continuous "Sending Grid Change to WSJT-X" every second.
    [AutoGridCL.py]
2023-04-19 fixed exception thrown by original forked wsjtx_packets.py
    [AutoGridCL.py]
2023-04-19 fixed case-insensitive comparison
2023-04-24 removed #define FASTBOOT
    The "fast boot" code was removed months ago. This change removes the #define that is no longer used anywhere.
    [Griduino.ino, constants.h]
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2023-04-29 shortened some logging info
    [save_restore.cpp]
2023-05-01 fixed crasher in 'dump kml'
    There's an Arduino compiler bug that randomly crashes the device when snprintf() uses a message buffer larger than about 250 bytes. We broke up a lengthy print statement into a dozen separate lines each of 128 characters or less.
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2023-05-12 fixed memory corruption in makeLocation()
    [Griduino.ino, model_breadcrumbs.h, model_gps.h]
2023-05-17 fixed compile error (missing subroutine)
    [Griduino.ino]
2023-07-07 fixed RTC lockup bug by using ElapsedMillis
    [Griduino.ino, constants.h]
2023-07-12 commented reminder that time_t = seconds since Jan 1, 1970
    Also corrected comment about which GitHub repository provides time_t
    [constants.h, view_altimeter.h, view_baro.h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]
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2023-12-25 rewrite touch calibrator example with hysterisis and other fixes
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2024-01-04 fix 1-second update interval for displaying current time-of-day
    [Griduino.ino]
2024-01-10 temporarily disabled Speech output
    Speech on the Feather M4 build has a crasher that bricks the program until you recompile and reinstall it.
    [cfg_audio_type.h]
2024-01-10 replaced local Touch.cpp with new Resistive_Touch_Screen library
    See https://github.com/barry-ha/Resistive_Touch_Screen
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2024-01-17 replaced Adafruit_Touchscreen with Resistive_Touch_Screen library
2024-01-18 replaced Adafruit_Touchscreen with my own Resistive_Touch_Screen library
    [Baroduino.ino]
2024-01-21 replaced Adafruit_Touchscreen with my new Resistive_Touch_Screen library
    [Griduino.ino, view.h]
2024-01-22 fixed the startup display location if you power off right after crossing a 6-digit grid boundary
    [AutoGridCL.py, Griduino.ino]
2024-01-22 fixed settings button, make it return to normal grid view after cycling through all the settings
    [Griduino.ino]
2024-01-26 fixed delay in leaving time panel
    [Griduino.ino]
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2024-02-13 fixed save/restore NMEA sentences
    [cfg_nmea.h, cfg_rotation.h, cfg_volume.h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]
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2024-03-11 fixed typo in debug string
    [constants.h]
2024-03-12 fixed commands sent by Arduino IDE
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2024-09-09 replaced logger.config() and logger.info() more general logger.log()
    [cfg_audio_type.h]
2024-09-09 replaced logger.config() with more general logger.log()
    [cfg_gps_reset.h]
2024-09-09 replaced logger.config() / info() / error() with more general logger.log()
    [cfg_nmea.h]
2024-09-09 replaced logger.config() / warning() with more general logger.log()
    [cfg_reboot.h]
2024-09-09 replaced logger.config() / error() with more general logger.log()
    [cfg_units.h]
2024-09-09 replaced logger.config() / info() with more general logger.log()
    [cfg_volume.h]
2024-09-09 replaced logger.config() / info() / and Serial.print() with more general logger.log()
2024-09-09 replaced Serial.println() with more general logger.log()
    [grid_helper.h]
2024-09-11 fixed logger bug in reporting coin battery voltage
    [Griduino.ino]
2024-12-03 fixed the logger for Flash Chip
    [save_restore.cpp]
2024-12-17 fixed NMEA sentence logging
    [Griduino.ino, cfg_nmea.h, model_gps.h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]
2024-12-17 fixed JEDEC ID log item
    [save_restore.cpp]
2024-12-18 continue work on Flash Reformat feature
    This is "minimally changed" code that compiles and doesn't hang the processor.
    [cfg_reformat.h, save_restore.cpp]
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2025-04-14 fixed GPS baud rate
    Removed leftover testing code that set baud rate for a GPS chip different than Adafruit Ultimate GPS
    [Griduino.ino]
2025-04-19 partial fix for identifying v4 versus v11 hardware
    [model_adc.h]
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2025-06-07 fix compiler warnings
    Removed unused variables. No functional changes.
    [grid_helper.h, model_baro.h, model_gps.h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]
2025-06-09 fix some compiler warnings
    [view_altimeter.h, view_baro.h]
2025-06-09 fixed some compiler warnings
    [TFT_Compass.h, cfg_audio_type.h, cfg_reboot.h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]
2025-06-12 replaced magic numbers with named constant
    [TFT_Compass.h]
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2025-06-13 fixed heading angle calculations
    [grid_helper.h]
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2025-06-16 fixed compass pointer, unit test
    [TFT_Compass.h, grid_helper.h]
2025-06-18 fixed simulated speed calculation
    [constants.h, model_gps.h]
2025-06-24 fix English/Metric selection
    Refactor view_units.h to handle onTouch much better
    [cfg_units.h]
2025-06-27 fix control panel screen sequence
    [Griduino.ino, cfg_reboot.h]
2026-11-01 add suggestions from Claude code review
    fix comments that contradict the code
    don't compute gDuration/gStep twice
    init PIN_VCS in case another sketch left it locked
    clang format
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2026-11-03 Use gpsBattery.readCoinBatteryVoltage() for periodic battery log
    Remove duplicated ADC math from loop() and skip the log on PCB v4,
    which has no coin battery sensor.
    Claude-Session: https://claude.ai/code/session_01WqF9eqRjcHUPukGDUMUSCW
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2026-11-04 fixed SPI vs I2C bus detection
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
